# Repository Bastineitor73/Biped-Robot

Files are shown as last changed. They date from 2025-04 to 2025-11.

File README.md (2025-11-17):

# Contacto

Quieres ser parte de B1P0? Envía un correo a josespi@udec.cl, mariomedina@udec.cl, agarrido2018@udec.cl o ginostroza2020@udec.cl

# Contenidos
- [Proyecto B1P0](#proyecto-b1p0)
  * [Objetivo](#objetivo)
  * [Visiones](#visiones)
  * [Temas actuales](#temas-actuales)
  * [Diagrama Electrico](#diagrama-electrico)
- [Avances](#avances)
- [Invitacion Charla](#invitacion-charla)
- [Contacto](#contacto)

# Proyecto B1P0


Quieres ser parte de B1P0? Envía un correo a agarrido2018@udec.cl o a ginostroza2020@udec.cl

## Objetivo
"Crear un robot bípedo estable y escalable a lo largo del tiempo desarrollado por alumnos del DIE, capaz de desenvolverse en entornos industriales complejos, catástrofes naturales, inspecciones y escenarios de alto riesgo humano"

## Visiones
<p align="center">
  
  
  
</p>

## Temas actuales
1.- Modelación física y desarrollo de un gemelo digital para entrenamiento y simulaciones

2.- Rediseño estructural del robot bípedo existente, mediante análisis de esfuerzos, estudio de materiales, mejoras en sistemas mecánicos y resistencia.

3.- Diseño e integración de una arquitectura de software basada en ROS/ROS2 para la comunicación entre CPU, microcontroladores, actuadores y usuario

4.- Diseño e implementación de un sistema de control remoto inalámbrico utilizando tecnologías RF, WiFi o Bluetooth.

5.- Diseño e implementación de un sistema de control adaptativo o predictivo para la estabilidad del robot bípedo

6.- Desarrollo de un sistema de estimación de estados mediante fusión de datos inerciales (IMU) y modelos dinámicos

7.- Implementación de un sistema de percepción visual y mapeo de entorno mediante cámara de profundidad

# Avance Actual

## Octubre 2025

https://github.com/user-attachments/assets/e0c73ede-dcd1-4829-920c-aed435cbe2b3

# Revisa nuestra Charla

https://www.canva.com/design/DAG2QE-IAb0/ETZ7DED0be4jHASCjCmeyw/view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

invitacion_2

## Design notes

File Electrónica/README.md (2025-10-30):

# Diagrama Electrico


# Lista de Dispositivos

## Microcontrolador Teensy 4.1


## SparkFun OpenLog Artemis


## Raspberry Pi 5, 16 GB RAM


## Cámara Intel RealSense D435i


## Batería Lipo
- 22.2V
- 6 celdas
- 5000 mAh


# Desarollo PCB's
Interacción de los componentes



## Monitor de bateria y Medidor de combustible
- Monitor MP2790
- Fuel Gauge MPF42795
- Comunicacion por I2C con librería "MP27XX.h"

- Placa accesoria para llave de paso MOS

- Placa accesoria UI Medidor de combustible
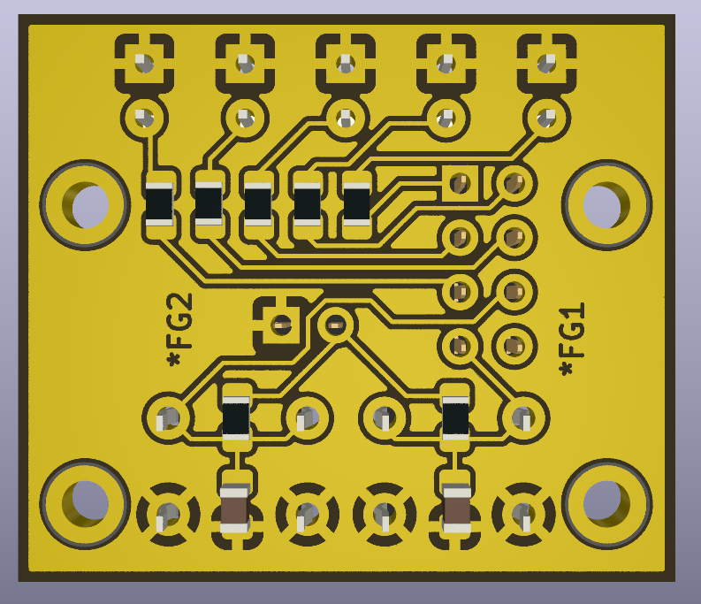
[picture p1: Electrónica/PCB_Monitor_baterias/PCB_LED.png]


## Placa de alimentacion
- Conversor buck TPS54531 5V @25W
- Regulador lineal TLV757p 3V3 @3W
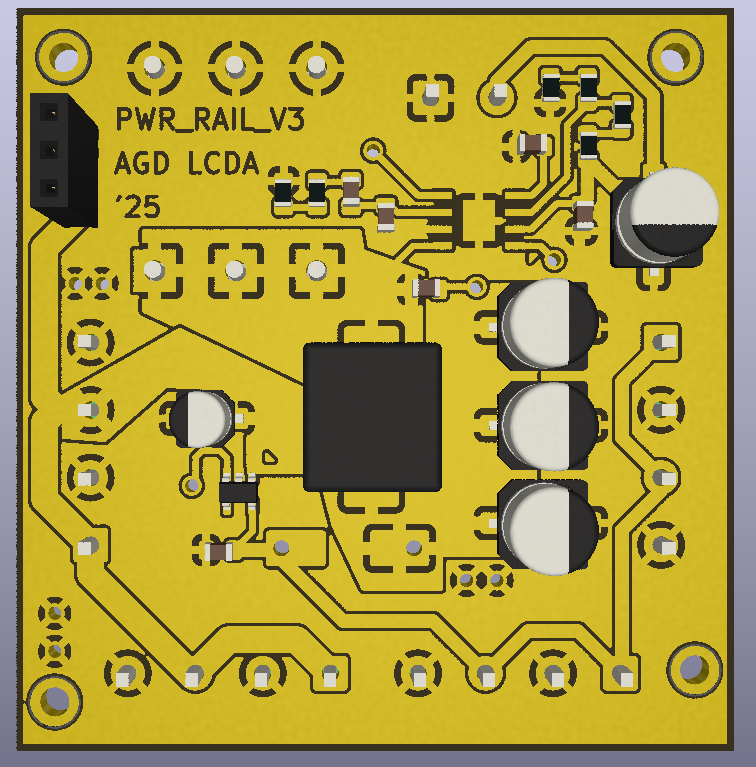
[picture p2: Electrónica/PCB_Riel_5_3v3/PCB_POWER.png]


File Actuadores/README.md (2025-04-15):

# Lista de Dispositivos

## Odrive S1
Driver de control de motores, utilizados para manejar los 6 actuadores del robot utilizando comunicación CAN.
- Voltaje de Operación: 12-48V
- Corriente Máxima: 40A (Continua)
- Modos de Control: Torque, Velocidad, Posición y Trayectoria
- Incluye encoder magnético MA702
- Peso: 35g
- Datasheet: https://docs.odriverobotics.com/v/latest/hardware/s1-datasheet.html
  


## Motor Eaglepower
Músculos principales del robot, cada motor (6 en total) son montados en 2 piernas (3 en cada una) por medio de una caja reductora de relación 9:1, amplificando así el torque de cada actuador.
- 90KV
- 40 polos





Parametros tabla KV90 con propeller T2795

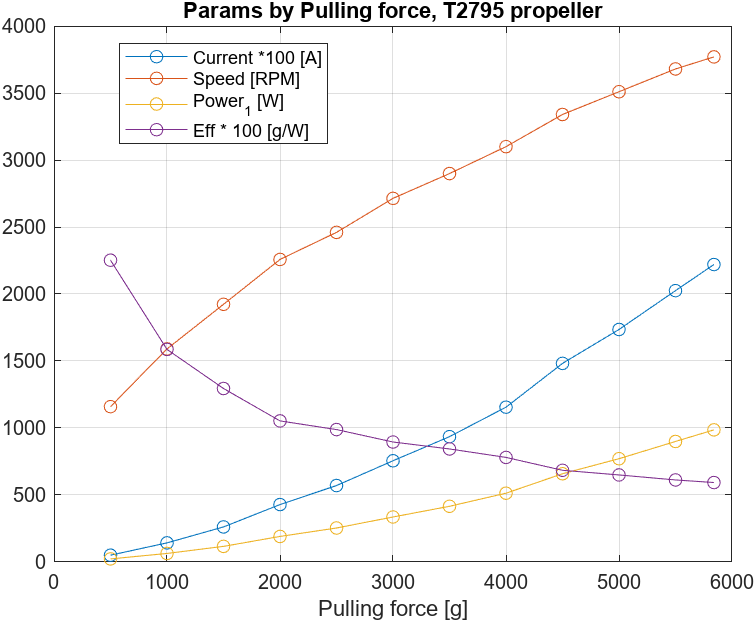
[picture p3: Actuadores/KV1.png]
Tabla KV90


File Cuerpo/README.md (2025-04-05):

# Materiales

## Filamento PLA


## Placa de fibra de carbono 
- 200x250mmx2mm



## Tubos de Fibra de carbono
- 19x17mm largo 500mm (x2)
- 12x10mm largo 500mm (x2)
- 28x26mm largo 500mm (x2)



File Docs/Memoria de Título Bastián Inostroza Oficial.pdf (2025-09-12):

UNIVERSIDAD DE CONCEPCIÓN
FACULTAD DE INGENIERÍA
DEPARTAMENTO DE INGENIERÍA ELÉCTRICA

DISEÑO E INTEGRACIÓN DE ACTUADORES QUASI-DIRECT DRIVE PROPIOCEPTIVOS EN UN ROBOT BÍPEDO DE ALTA DINÁMICA

POR

Bastián Nicolás Inostroza Sanzana

Memoria de Título presentada a la Facultad de Ingeniería de la Universidad de Concepción para optar al título profesional de Ingeniero(a) Civil Electrónico(a)

Profesor(es) Guía
José Rubén Espinoza Castro

Septiembre 2025
Concepción (Chile)

©2025 Bastián Nicolás Inostroza Sanzana

ii

©2025 Bastián Nicolás Inostroza Sanzana

Se autoriza la reproducción total o parcial, con fines académicos, por cualquier medio o procedimiento, incluyendo la cita bibliográfica del documento.

iii

A Dios por la fuerza que me da para no rendirme. A toda mi familia que amo y siempre me ha apoyado. A mi pareja y amigos que creyeron en mí. Y por los alumnos del pasado, presente y futuro del L.C.D.A.

iv

## Agradecimientos

Primero que todo le doy gracias a Dios por darme la energía y perseverancia en esta memoria. Sin duda, si no fuera por Él, no habría logrado terminar un proyecto tan ambicioso y grande como lo

es el construir un robot de este alcance.

También le doy gracias a mis padres y familia que siempre creyeron en mis capacidades, me

educaron para lograr todas las metas que me proponga, me apoyaron cuando necesitaba ayuda y para

aconsejarme.

Gracias le doy al profesor José Espinoza por creer en este proyecto desde el primer día,

gestionar cada material, ser un excelente mentor y académico, que en mi opinión, es el mejor de la

Universidad de Concepción.

Gracias le doy a mi pareja por alentarme cada día, apoyarme cuando me sentía cansado y

siempre levantarme los ánimos durante largas jornadas de trabajo.

Gracias le doy a mis amigos que creyeron en mí, me brindaron ideas, me criticaron

constructivamente y en ciertas ocasiones me colaboraron con el armado del robot.
Gracias le doy enormemente a don René Álvarez por apoyarme en el ensamblado del robot y

la manufactura de piezas, además de sus sabios consejos profesionales que los llevaré siempre en mis

recuerdos.

Gracias por su puesto al director del Departamento de Ingeniería Eléctrica, el profesor Juan

Tapia, junto con el profesor Luis Morán y el vicedecano Eduardo Balladares, por haber contribuido

en gran manera con el financiamiento de este proyecto.

También agradezco a don Ramón Lillo por facilitar sus instrumentos de laboratorio y su

colaboración en la mantención de algunos motores.

Por último pero no menos importante, agradezco a los compañeros del L.C.D.A. que fueron

casi como una familia a lo largo del semestre, sin duda sus consejos u opiniones fueron de gran ayuda

para el desarrollo de este proyecto.

Nadie llega lejos solo, detrás de grandes proyectos, hay grandes equipos. Sin embargo, a pesar

de todo, mi mayor fuente de inspiración y perseverancia ha sido la fe. Con ese espíritu de confianza y

resiliencia que ha guiado cada paso, concluyo con una cita que resume mi experiencia:

“Bendito el varón que confía en Jehová, y cuya confianza es Jehová. Porque será como el

árbol plantado junto a las aguas, que junto a la corriente echará sus raíces, y no verá cuando viene

el calor, sino que su hoja estará verde; y en el año de sequía no se fatigará, ni dejará de dar fruto.”

(Jeremías 17:7-8)

v

## Sumario

En la última década, la robótica bípeda ha experimentado un progreso gigante. El desarrollo

de plataformas como Atlas (Boston Dynamics), Cassie (Agility Robotics) o Tron 1 (Limx Dynamics)

han mostrado que los principales desafíos siguen siendo la estabilidad, planificación de trayectorias,

eficiencia energética, reducción de masa y últimamente los tipos de actuadores. En este escenario, los

actuadores Quasi Direct Drive (QDD) se han transformado en un hito tecnológico al permitir

transmisiones bajas y compactas, con alta densidad de torque, bajo peso y buena eficiencia energética,

condiciones críticas para lograr movimientos rápidos y controlados en tiempo real. Universidades

reconocidas como MIT, Stanford, UCLA o empresas privadas como Boston Dynamics han liderado

estas investigaciones, estableciendo un estándar que enseña e inspira desarrollos a nivel global.

En este contexto, la presente memoria aborda el diseño y validación de un actuador QDD

propioceptivo e integrado en el robot bípedo B1P0 de 6 grados de libertad, cumpliendo los objetivos

de: (i) comunicación CAN multi-driver operativa; (ii) modelo 3D e integración mecánica; (iii) control

independiente por eje con demostración funcional; y (iv) un actuador de alta densidad de torque capaz

de retroalimentar su posición con exactitud en tiempo real. El actuador desarrollado con un reductor

planetario 9:1 impreso en 3D alcanza una densidad de torque de 20.9 [Nm/kg], con aproximadamente

un 95 % de eficiencia frente al motor desnudo (sin reductor) que genera 5.3 [Nm/kg]. Concluyendo

además, que el actuador construido entrega 8.8 veces más torque útil sin penalizar corriente.

El chasis modular de tres niveles (potencia, control y sensores) permitió fácil mantenimiento

y alta escalabilidad; el sistema entra de forma confiable en lazo cerrado y ejecuta trayectorias por

CAN (video demo en el repositorio). En conjunto, B1P0 constituye hasta donde se tiene registro, el

primer prototipo de robot bípedo de esta envergadura en Chile, desarrollado íntegramente en el

Laboratorio de Control Digital Aplicado (L.C.D.A.) de la Facultad de Ingeniería de la Universidad de

Concepción, dejando una base sólida para iterar en: estructura y materiales livianos, simulaciones

avanzadas, sistemas de control, visión por computadora e inteligencia artificial.

vi

## Summary

Over the last decade, bipedal robotics has experienced tremendous progress. The development

of platforms such as Atlas (Boston Dynamics), Cassie (Agility Robotics), and Tron 1 (Limx

Dynamics) have shown that the main challenges remain stability, trajectory planning, energy

efficiency, mass reduction, and, more recently, actuator types. In this context, Quasi Direct Drive

(QDD) actuators have become a technological milestone, enabling low and compact transmissions

with high torque density, low weight, and good energy efficiency—critical conditions for achieving

rapid, controlled movements in real time. Renowned universities such as MIT, Stanford, and UCLA,

as well as private companies such as Boston Dynamics, have led this research, setting a standard that

teaches and inspires developments globally.

In this context, this paper addresses the design and validation of a proprioceptive QDD actuator

integrated into the 6-degree-of-freedom B1P0 biped robot, fulfilling the objectives of: (i) operational

multi-driver CAN communication; (ii) 3D model and mechanical integration; (iii) independent axis

control with functional demonstration; and (iv) a high-torque-density actuator capable of accurate

position feedback in real time. The developed actuator with a 3D-printed 9:1 planetary gearbox

achieves a torque density of 20.9 [Nm/kg], with approximately 95% efficiency compared to the bare

motor (without gearbox) that generates 5.3 [Nm/kg]. Furthermore, it is concluded that the constructed

actuator delivers 8.8 times more useful torque without any current penalty.

The three-level modular chassis (power, control, and sensors) allowed for easy maintenance

and high scalability. The system reliably enters a closed loop and executes trajectories via CAN (demo

video in the repository). Overall, B1P0 constitutes the first bipedal robot of this size in Chile,

developed entirely in the Applied Digital Control Laboratory (LCDA) of the Faculty of Engineering

at the University of Concepción, leaving a solid foundation for iterating in: lightweight structure and

materials, advanced simulations, control systems, computer vision, and artificial intelligence.

vii

## Tabla de Contenidos

viii

ix

## Lista de Tablas

x

## Lista de Figuras

Figura 1.2: Comparación anatómica de articulaciones inferiores entre humano y avestruz (Haberland

Figura 1.3: Comparativa del movimiento articular entre el colapso de rodilla hacia adelante y la

Figura 1.5: Vista transversal superior del actuador de acero-molibdeno robótico diseñado por la

Figura 2.4: Funcionamiento interno de un motor BLDC comparando señales de entrada y salida ... 14

Figura 2.12: Componentes de un nodo (dispositivo) conectado a un bus de CAN (datasheet modulo

Figura 2.13: Funcionamiento de 2 estados lógicos en protocol CAN, recesivo 1 y dominante 0 (A. Martínez Requena, "Introducción a CAN bus: Descripción, ejemplos y aplicaciones de tiempo

Figura 4.4: Región de operación del control de torque basado en límites de corriente y velocidad.. 42

xi

Figura 5.4: Actuador impreso; a) sin carcasa y salida de pernos, b) con carcasa y salida con polea

### 1. Introducción

### 1.1. Introducción General

Los robots bípedos han evolucionado desde prototipos experimentales de universidades

destacadas hasta plataformas con aplicaciones prácticas en industrias como minería, manufactura,

logística y rescate. Su principal ventaja radica en la capacidad de operar en entornos diseñados para

humanos, incluyendo terrenos irregulares y espacios confinados donde los sistemas con ruedas

resultan ineficientes. Sin embargo, su desarrollo enfrenta tres desafíos fundamentales: (1) la

complejidad en mantener estabilidad con solo dos puntos de apoyo, (2) la alta demanda energética en

movimientos explosivos (como saltos, escaladas, caídas, etc.), y (3) la necesidad de actuadores que

combinen alto torque, precisión y baja inercia sin incrementar excesivamente costos o el peso.

En este contexto, los actuadores eléctricos propioceptivos han surgido como solución clave

para robots dinámicos, destacándose en plataformas como el MIT Mini Cheetah [1], Cassie de Agility

Robotics [2] o en robots comerciales como el construido por la empresa China Limx Dynamics [3],

Fig. 1.1. Estos sistemas integran sensores de posición y control de torque en lazo cerrado, permitiendo

movimientos precisos bajo cargas variables y mejorando la eficiencia energética [4]. No obstante, su

implementación en entornos académicos suele verse limitada por los altos costos de componentes

personalizados y la complejidad en el diseño mecánico de reductores planetarios, como se evidenció

en los prototipos preliminares desarrollados para esta investigación [5].

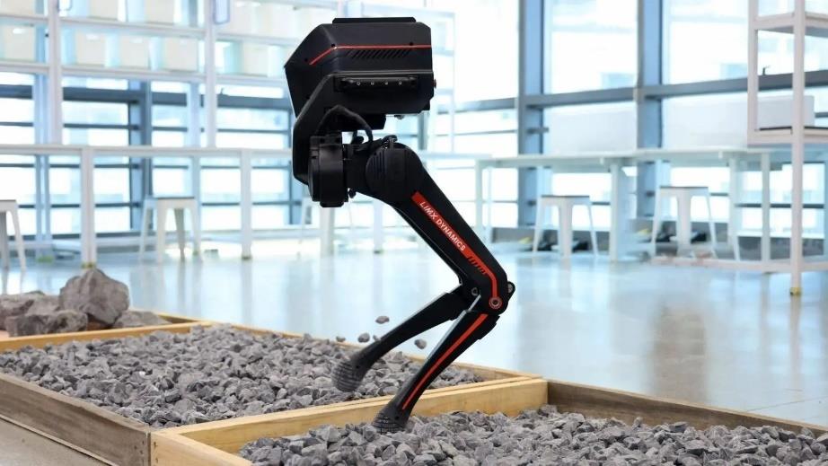
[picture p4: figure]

Figura 1.1: Robot bípedo Tron 1, desarrollado por la empresa LimX Dynamics

Esta memoria, además aborda el diseño, construcción y validación experimental de un

actuador robótico QDD propioceptivo modular de bajo costo, destinado a un robot bípedo de 6 grados

de libertad. La propuesta se basa en tres pilares: (i) el uso de motores BLDC comerciales acoplados a

engranajes planetarios impresos en 3D, validando experimentalmente como se mejora el torque

continuo de salida y la densidad de torque; (ii) la implementación de un sistema de control basado en

el driver Odrive S1 [6], utilizando protocolos CAN bus para sincronización multi-actuador; y (iii) la

modelación 3D de un robot bípedo con su respectivo prototipo físico.

Los resultados obtenidos no solo tienen potencial aplicación en industrias de alta dinámica y

terrenos complejos como minería, construcción, agronomía, entre otros. Sino que además, presentan

un gran avance en el desarrollo de robots humanoides en Chile, siendo la Universidad de Concepción

de las primeras casas de estudios en diseñar y construir un prototipo de robot bípedo modular y

altamente escalable para investigaciones futuras, dando un paso al frente en la robótica avanzada para

nuestro país.

### 1.2. El riesgo inherente de labores humanas

El uso de robots bípedos en labores de alto riesgo se presenta como una solución eficiente y viable en sectores donde las condiciones de trabajo son peligrosas para los seres humanos. Ámbitos

como el rescate en incendios forestales, las labores de salvamento en entornos urbanos o las

actividades en minería enfrentan riesgos constantes, que van desde accidentes por caídas, colapsos

estructurales, hasta la exposición a gases tóxicos y químicos. Un bombero en acción, por ejemplo, se

ve constantemente expuesto a peligros como quemaduras, derrumbes o la caída de elementos pesados,

como árboles y ramas. En la industria minera, los informes del Servicio Nacional de Geología y

Minería (Sernageomin) señalan que las principales causas de accidentes fatales son los golpes de

rocas, las caídas desde alturas y los deslizamientos de tierra [7]. Además, las estadísticas de

accidentabilidad laboral del 2020 revelan que los accidentes más comunes se originan a partir de

factores materiales, como el uso de herramientas no eléctricas, y condiciones ambientales o

estructurales adversas [8]. Como se ilustra en la Tabla 1.1:

Tabla 1.1: Tabla de indicadores de accidentabilidad año 2021, por SISESAT SUSESO

A partir de estos datos, es evidente que, si bien algunos accidentes pueden originarse por

errores humanos, muchos otros son el resultado de condiciones imprevistas o peligrosas que no pueden

ser fácilmente mitigadas por la intervención directa de los trabajadores. Los robots bípedos, equipados

con sensores avanzados, podrían realizar tareas como la inspección de zonas peligrosas, la detección

de sustancias tóxicas y la evaluación de la estabilidad estructural, minimizando así la exposición de

los trabajadores a estos riesgos. Estos robots no solo serían capaces de acceder a lugares inaccesibles

para los humanos, sino que también ofrecerían una capa adicional de seguridad al acompañar a los

operativos en terreno, anticipando y previniendo posibles accidentes.

Aunque los robots móviles autónomos con ruedas también podrían realizar algunas de estas

tareas, su capacidad para maniobrar en terrenos complejos es limitada. Las ruedas enfrentan

dificultades al sortear obstáculos, subir escaleras o desplazarse en terrenos irregulares, lo que

incrementa el consumo energético y, en muchos casos, hace inviable su uso en entornos altamente

dinámicos. En cambio, un robot bípedo, gracias a su capacidad para adaptarse a variaciones en el

terreno y sortear obstáculos con mayor facilidad, representa una solución más eficiente, segura y

energética para enfrentar desafíos en estos entornos.

### 1.3. Una breve revisión sobre los robots de alta dinámica con patas

Los robots humanoides y con patas han experimentado avances tecnológicos considerables en

las últimas dos décadas. Dos factores principales que han contribuido al desarrollo de la investigación

sobre robots con patas: el hardware y la tecnología de control.

Ahora bien, la pregunta que cualquiera podría realizarse es porque con patas y no con ruedas.

La promesa de los robots con patas frente a los robots con ruedas estándar es proporcionar una

movilidad mejorada en terrenos difíciles. Esta promesa se basa en el desacoplamiento entre el entorno

y el cuerpo principal del robot que permite la presencia de piernas articuladas, con dos consecuencias.

En primer lugar, el movimiento del cuerpo principal del robot puede hacerse en gran medida

independiente de la rugosidad del terreno, dentro de los límites cinemáticos de las piernas. En segundo

lugar, este desacoplamiento permite que las piernas abandonen temporalmente su contacto con el

suelo, pudiendo así superar los puntos de apoyo aislados en un terreno discontinuo, lo que permite

visitar lugares absolutamente fuera de alcance de otro modo y además mejorar la eficiencia energética

en ciertos periodos de tiempo cuando una pierna esté en caída libre.

Aunque todavía no igualan las capacidades de los humanos y los animales, los robots con patas

sí contribuyen a comprender su locomoción y estilo de movimiento, como lo demuestran las muchas

colaboraciones fructíferas entre investigadores en robótica y biomecánica.

Recientemente, diferentes institutos de investigación han desarrollado robots cuadrúpedos más

avanzados, como HyQ, ANYmal, MITCheetah y MiniCheetah. En el caso de los robots bípedos y

humanoides, se han publicado en la literatura muchos logros de investigación significativos como

TORO, TALOS, E2-DR, Cassie o algunos robots industriales de origen privado como el Biped Robot

Tron 1 de Limx Dynamics, Digit de Agility Robotics, Optimus Gen 2 de Tesla, o el recientemente

actualizado robot Atlas de Boston Dynamics.

El progreso en las últimas décadas ha sido notable. Preguntas profundas han sido finalmente

respondidas: ahora se entiende cómo hacer que los robots con patas caminen y corran de manera

bastante práctica. Pero aún quedan otras preguntas profundas por responder, como cuál es la mejor

manera (o manera óptima) de hacer que caminen y corran eficientemente, o también si es posible

estandarizar o generalizar un método de locomoción bípeda en la mayoría de robots.

El rendimiento de los robots con patas necesita ser mejorado de muchas maneras: energía,

velocidad, reactividad, versatilidad, robustez, etc. Por lo tanto, seguiremos discutiendo en el siguiente

tema los problemas más relevantes que actualmente intrigan a nuestra comunidad robótica.

### 1.4. La eficiencia anatómica de robots bípedos con rodillas hacia atrás

El diseño de robots bípedos se basa en principios anatómicos observados en la naturaleza,

destacando la orientación de las rodillas. En el estudio de Haberland y Kim (2015) [4], se demuestra

que las rodillas hacia atrás optimizan la eficiencia de locomoción al reducir la dependencia del torque

en la cadera y permitir que una sola articulación combine funciones de propulsión y elevación. Este

diseño es más eficiente en un 80% de los casos evaluados en cuanto al costo mecánico de transporte,

con una significativa disminución del esfuerzo en la cadera.

Sin embargo, es importante aclarar que el diseño del robot bípedo no utiliza rodillas en el

sentido convencional. Aunque el estudio se basa en la eficiencia de rodillas hacia atrás, en el futuro

robot lo que parecen ser las rodillas, de hecho, son tobillos modificados con una configuración similar

a las rodillas hacia atrás como se puede ver en la Figura 1.2. Esto significa que, aunque la anatomía y

la mecánica son las de un tobillo, visual y funcionalmente adoptan un principio similar al de las

rodillas hacia atrás, favoreciendo la propulsión y la elevación sin depender del movimiento de la

cadera.

Figura 1.2: Comparación anatómica de articulaciones inferiores entre humano y avestruz (Haberland y Kim, 2015)

Ventajas funcionales clave de este diseño:

1. Propulsión y elevación simultáneas: Las articulaciones modificadas, que imitan el

comportamiento de las rodillas hacia atrás, permiten que el robot mantenga propulsión

sin depender de la cadera. Como se observa en la Figura 1.3, una rodilla tradicional

hacia adelante no podría realizar este tipo de propulsión sin la ayuda de la cadera.

2. Reducción de pérdidas de energía por impacto: Al igual que en el caso de las

rodillas hacia atrás, este diseño reduce el torque cuadrático, optimizando el costo de

transporte y mejorando la eficiencia energética.

Figura 1.3: Comparativa del movimiento articular entre el colapso de rodilla hacia adelante y la propulsión con rodilla hacia atrás (Haberland y Kim, 2015)

Aunque el estudio de Haberland y Kim [4] no evalúa explícitamente terrenos irregulares, los

principios mencionados sugieren que este tipo de diseño también es ventajoso en contextos de

variabilidad del terreno debido a:

- Menor dependencia de la cadera: La reducción del torque necesario en la cadera minimiza

los desbalances causados por cambios en la altura del terreno o impactos laterales.

- Adaptación a variaciones del terreno: La capacidad de los tobillos modificados para realizar

propulsión y elevación permite ajustes rápidos en la zancada sin comprometer la estabilidad.

- Centro de masa estable: Concentrar la masa cerca del torso reduce el momento de inercia,

facilitando el equilibrio ante perturbaciones externas.

Este diseño con tobillos modificados que simulan rodillas hacia atrás se presenta como una

solución eficiente y funcional para superar las limitaciones comunes en la locomoción robótica. La

capacidad de reducir la dependencia de la cadera, optimizar el torque en las articulaciones y adaptarse

dinámicamente a variaciones del terreno resalta como una ventaja clave para el rendimiento del robot,

posicionándolo como una opción robusta para aplicaciones en terrenos complejos.

### 1.5. Requisitos de diseño en actuadores modulares para robots de alta dinámica

Un robot bípedo sin un buen actuador, es como un deportista sin buenos músculos. El diseño

de actuadores modulares para robots de alta dinámica, siendo generalmente estudiado por las

universidades mas reconocidas del mundo en robótica, debe equilibrar torque, eficiencia, velocidad y

peso. A continuación se presentan los requisitos clave extraídos de actuadores desarrollados por

algunas academias, como la Universidad de Genoa, la Universidad de Denver y el Instituto

Tecnológico de Massachusetts (MIT).

1. Densidad de torque y eficiencia:

El robot Mini Cheetah del MIT (ver Figura 1.4) optimiza la densidad de torque mediante un

rotor personalizado, logrando un torque máximo de 34 [Nm] sin aumentar el tamaño del motor [9].

Este enfoque de alta densidad de torque es esencial para generar fuerza en un tamaño compacto.

Similarmente, el actuador de la Universidad de Genoa prioriza alta velocidad y torque continuo

mediante un diseño de baja reducción, alcanzando un torque continuo de 26.4 [Nm] con una eficiencia

de 80% [10].

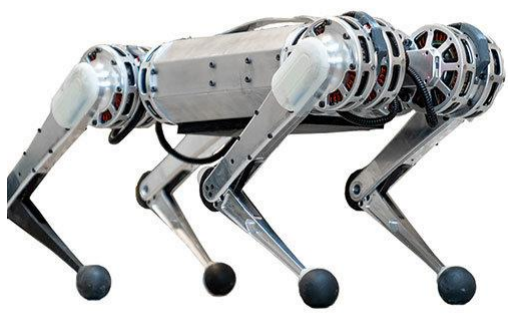
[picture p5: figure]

Figura 1.4: Robot Mini Cheetah del Instituto Tecnológico de Massachusetts

2. Reducción de inercia y aumento de compacidad:

El Mini Cheetah y el robot Mithra de la Universidad de Denver colocan los actuadores de

manera proximal para reducir la inercia, facilitando movimientos rápidos y controlados [9][11].

Mithra también utiliza mecanismos de 4 barras en el tobillo para reducir la masa distal y mejorar la

dinámica.

3. Adaptabilidad dinámica y control:

El actuador del MIT y de Genoa integran sensores de retroalimentación como encoders

magnéticos y control FOC, lo que permite ajustar la respuesta del actuador en tiempo real durante

tareas dinámicas [9][10], asegurando un control preciso incluso en altas velocidades, permitiendo que

el actuador mantenga un rendimiento estable bajo condiciones dinámicas

4. Resistencia estructural:

La resistencia estructural es clave para soportar fuerzas de impacto y garantizar la durabilidad

del actuador. El uso de materiales ligeros y resistentes en el MIT Mini Cheetah y el robot Mithra

aseguran la resistencia estructural sin aumentar mucho el peso. El robot de Genoa utiliza engranajes

de acero-molibdeno (ver Figura 1.5) en su caja reductora para proporcionar rigidez adicional [10].

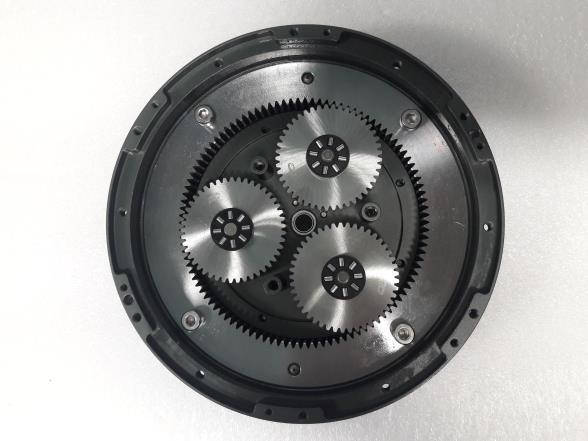
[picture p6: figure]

Figura 1.5: Vista transversal superior del actuador de acero-molibdeno robótico diseñado por la Universidad de Genoa, Italia.

### 1.6. Objetivos

1.6.1 Objetivo General

Diseñar, construir y validar actuadores robóticos QDD propioceptivos capaces de funcionar

simultáneamente integrados en un robot bípedo de 6 grados de libertad.

1.6.2 Objetivos Específicos

- Establecer un protocolo de comunicación para el trabajo simultáneo de múltiples drivers

y verificar su correcto funcionamiento.

- Construir un actuador robótico de baja relación de transmisión capaz de retroalimentar su

posición en tiempo real.

- Diseñar un modelo 3D para un robot bípedo de 6 grados de libertad.
- Lograr un movimiento independiente de cada eje del robot bípedo.

### 1.7. Alcances y Limitaciones

Este trabajo se enfoca en desarrollar actuadores robóticos para un robot bípedo, pero con

algunas restricciones importantes. No se diseñarán los circuitos electrónicos ni los motores desde cero,

se utilizarán componentes ya disponibles en el mercado. Tampoco se harán optimizaciones mecánicas

muy avanzadas, sino que se limitará a modelado 3D básico con los materiales que se tengan a mano.

Lo que sí se logra es crear un sistema completo donde varios actuadores trabajen

independientemente, con un protocolo de comunicación implementado. El robot tendrá 6 grados de

libertad y se validará el funcionamiento con pruebas prácticas de movimiento y torque, sabiendo que

será un prototipo académico más que un producto industrial terminado.

La idea es demostrar que se puede armar un sistema robótico funcional con componentes

accesibles, sentando bases para futuras mejoras. No es perfecto, pero sirve para investigar conceptos

clave de locomoción bípeda, sistemas de comunicaciones, actuadores eléctricos, cinemática, visión

artificial y varios conceptos más abordados por diferentes alumnos de la facultad de ingeniería, de tal

manera de crear un proyecto sólido y escalable a lo largo del tiempo.

### 1.8. Temario y Metodología

Esta memoria sigue una estructura progresiva que avanza desde los fundamentos teóricos hasta

la implementación práctica, organizada en seis capítulos principales. El Marco Teórico (Capítulo 2)

establece las bases físicas y mecánicas del proyecto, incluyendo dinámica rotacional, diseño de

actuadores y protocolos de comunicación, respaldado por revisión bibliográfica de referencias clave.

Los Capítulos 3 y 4 analizan soluciones existentes y presentan una propuesta de diseño, centrada en

modularidad y bajo costo mediante modelado 3D y componentes comerciales.

La metodología combina prototipado ágil (impresión 3D, pruebas incrementales) con

validación experimental sistemática. Finalmente el Capítulo 5 detalla la implementación del actuador

y los resultados de torque y sincronización de actuadores, contrastando datos teóricos y empíricos. El

proceso se apoya en herramientas como Fusion 360, lenguaje C++, Python, entre otras. Asegurando

constantemente el cumplimiento de los objetivos específicos planteados en la sección 1.6.2.

### 2. Marco Teórico

### 2.1. Motores DC Brushless y operación

Los motores DC Brushless, conocidos popularmente como BLDC (Brushless DC), son

motores eléctricos de corriente continua que no poseen escobillas ni sistemas de conmutación

mecánica, a diferencia de los motores DC tradicionales. Esta ausencia de partes móviles de fricción

proporciona beneficios como mayor vida útil, menor mantenimiento y una eficiencia energética

superior.

Aunque estos motores suelen clasificarse como motores DC debido a su alimentación directa

con corriente continua, técnicamente pertenecen a la familia de motores síncronos, caracterizados por

operar a una velocidad sincronizada con la frecuencia de la corriente aplicada mediante un inversor

electrónico. Esta velocidad se define según la fórmula:
N =

120f
P

(2.1)

donde N representa la velocidad de sincronismo en [rpm], f la frecuencia de alimentación, y

P el número de pares de polos del motor [12]. De esta ecuación se concluye que, para realizar un

control continuo y eficiente de la velocidad, es imprescindible modificar la frecuencia de excitación

eléctrica del motor ya que la alternativa de variar físicamente el número de pares de polos es inviable

para aplicaciones dinámicas donde buscamos obtener velocidades variantes y no discretas en el

tiempo.

2.1.1 Construcción

Los motores BLDC presentan dos configuraciones constructivas principales [13]:

- Inrunner: El rotor se ubica en el interior del estator, proporcionando mayores

velocidades de rotación a costa de un menor torque.

- Outrunner: El rotor rodea externamente al estator, resultando en mayores niveles de

torque pero a menores velocidades, como se muestra en la Figura 2.1.

Figura 2.1: Configuraciones clásicas de estator y rotor en motores BLDC

La estructura interna consiste en un rotor provisto de imanes permanentes y un estator con

devanados distribuidos en fases generalmente trifásicas. La Figura 2.2 ilustra esta configuración

básica.

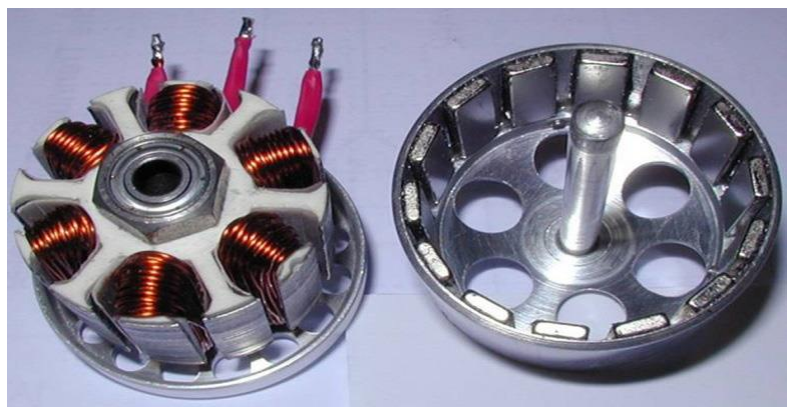
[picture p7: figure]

Figura 2.2: Estructura interna de un motor BLDC de tipo Outrunner

2.1.2 Principio de funcionamiento y sistemas de control

El principio de operación del motor BLDC radica en la interacción entre los campos

magnéticos generados por los imanes permanentes del rotor y los campos electromagnéticos

generados por los devanados del estator. Estos motores están diseñados específicamente para lograr

una fuerza electromotriz (FEM) de forma trapezoidal, lo que exige un flujo magnético uniforme por

parte del rotor [14].

En un motor BLDC trifásico típico, las fases del estator (A, B y C) se energizan

secuencialmente mediante un controlador electrónico, generalmente un inversor trifásico. Esta

secuencia de activación crea un campo magnético rotatorio que interactúa con el campo magnético estático generado por los imanes permanentes del rotor, induciendo así su rotación. La activación de

cada fase debe sincronizarse cuidadosamente en función de la posición angular del rotor, generalmente

detectada por sensores Hall o mediante técnicas de detección de fuerza contraelectromotriz (FCEM).

La Figura 2.3 muestra una configuración típica de un motor trifásico BLDC, donde se

identifican el estator con las bobinas trifásicas (fases U, V y W), el rotor provisto de imanes

permanentes, y el espacio de aire que facilita la interacción magnética.

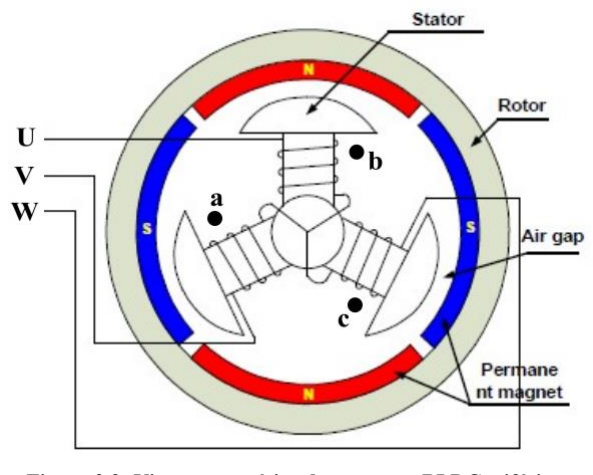
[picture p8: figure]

Figura 2.3: Vista esquemática de un motor BLDC trifásico

La secuencia típica de activación de las fases sigue un patrón como U→V→W, con cada fase

activada en intervalos específicos y alternando la polaridad para asegurar una rotación continua y

uniforme del rotor. Este proceso se repite continuamente mientras se aplica energía al motor [14].

Como se ha explicado anteriormente, para poder controlar la velocidad de un motor síncrono

de una manera continua es necesario ajustar la frecuencia de excitación, por este motivo los motores

BLDC precisan de algún dispositivo capaz de transformar una señal continua en otra alterna; para la

tarea anterior se suele utilizar un inversor, capaz de generar una señal de excitación alterna de

frecuencia deseada con la que poder alimentar a cada fase del motor.

La conmutación y control preciso de los motores BLDC generalmente se realiza mediante

sensores de efecto Hall. Estos sensores proporcionan señales discretas que informan al controlador

electrónico sobre la posición angular del rotor, lo que permite realizar una conmutación adecuada y

precisa de los devanados del estator, asegurando un control estable y eficiente.

Figura 2.4: Funcionamiento interno de un motor BLDC comparando señales de entrada y salida

La Figura 2.4 muestra la relación entre la señal generada por la FEM y la posición codificada

por los sensores de efecto Hall.

En aplicaciones donde los sensores no son una opción viable, por ejemplo en ambientes

herméticos como compresores, se utiliza un método denominado control "sensorless", basado en la

detección de la fuerza contraelectromotriz (FCEM). En este enfoque, la conmutación se realiza

detectando los cruces por cero de la señal FCEM [14].

2.1.3 Comparación respecto a alternativas de motores DC

La elección de motores BLDC para robots dinámicos bípedos está justificada por varias

razones técnicas. Los motores síncronos alimentados por corriente alterna no son adecuados debido a

la limitación práctica de disponer de una red fija de 220 [V]. Por ende, los motores BLDC alimentados

por corriente continua destacan como la opción ideal, al proporcionar alto torque, respuesta rápida y

eficiencia energética con fuentes de alimentación portátiles.

En comparación con otras opciones populares como servomotores o motores paso a paso, los

motores BLDC ofrecen ventajas claras en aplicaciones robóticas dinámicas debido a su mayor

relación torque-peso, alta eficiencia energética y capacidad para respuestas rápidas y precisas en

situaciones cambiantes. Los servomotores tienden a ser más pesados y lentos, mientras que los motores paso a paso generalmente presentan limitaciones en términos de torque dinámico y eficiencia

energética.

### 2.2. Fundamentos físicos y mecánicos

En el desarrollo de actuadores robóticos es preciso entender la física detrás de todo y por

supuesto los objetivos que se desean alcanzar. Cuando se busca obtener un actuador robótico robusto,

de alta dinámica, poca masa y alto torque, buscamos cumplir con principios básicos de física general

y mecánica, como lo es el concepto de torque (o par) ya sea mecánico o eléctrico, un concepto poco

conocido pero muy usado en el diseño de sistemas mecánicos fuertes, como lo es la densidad de

torque. Siguiendo la misma línea, como se ve en capítulos posteriores el diseño de un actuador siempre

debe considerar un sistema de amplificación de fuerzas (torque), lo cual en mecánica, siempre lleva a

la teoría y base de todo, como lo es las velocidades angulares, tangenciales y transmisión de potencia.

2.2.1 Torque eléctrico y mecánico

Cuando se ejerce una fuerza en un objeto rígido que se articula en torno a un eje, el

objeto tiende a dar vuelta en torno a dicho eje. La tendencia de una fuerza a dar vuelta un

objeto en torno a cierto eje se mide mediante una cantidad llamada momento de torsión, torque, par o

en algunos países torca. Denominado comúnmente con la letra griega tau (τ). [15]

La magnitud del momento de torsión se define mediante la siguiente expresión medida en

Newton metro [Nm]:
τ = rFsen(φ) | (2.2)

donde r es la distancia entre el punto de aplicación de la fuerza F y φ es el ángulo con la

horizontal en el punto donde se aplica la fuerza. Notar que si φ = 90° el torque es máximo, por lo

tanto en esos casos se puede simplificar la expresión a simplemente la fuerza aplicada multiplicada

por la distancia al eje de rotación.

Por otro lado, pero de manera similar, en las máquinas eléctricas rotatorias, como lo es

anteriormente explicado un motor BLDC, el concepto de torque físicamente es el mismo orientado a

un eje como lo es el rotor, pero se consideran otras propiedades para calcularlo. como por ejemplo la

corriente que circula por la armadura del motor ya que todos los conductores en el devanado de

armadura desarrollan torque en la misma dirección entonces contribuyen a este torque. De esta manera

el torque medio eléctrico total es:

τ = KaΦIa | (2.3)

donde Φ es el flujo magnético que fluye desde el polo a la armadura, Ka la constante del devanado

que depende del diseño del motor y finalmente Ia que es la corriente de armadura que es proporcional

a la carga del motor [16]. De esta manera, el torque claramente depende de la carga sometida en el eje

la cual se ve reflejada en el consumo de corriente.

2.2.2 Densidad de Torque

En el diseño de sistemas mecánicos y actuadores robóticos, un parámetro frecuentemente

subestimado pero de gran relevancia es la densidad de torque. Este concepto permite evaluar la

capacidad de un componente para entregar fuerza rotacional (torque) en relación con el espacio o

volumen que ocupa, lo que resulta fundamental en aplicaciones donde el tamaño y el peso están

restringidos, como en robótica bípedo.

La densidad de torque se define como la relación entre el torque que puede entregar un

componente y su volumen:

### Densidad de Torque =

τ
V
| (2.4)

donde es el torque entregado y el volumen físico del componente. Sus unidades típicas son Newton-metros por metro cúbico [Nm/m³
] o Joules por metro cúbico. En esencia, cuantifica cuánta fuerza

rotacional puede generar un sistema por unidad de espacio disponible [17].

Este parámetro complementa a la tradicional potencia mecánica, definida como:
Pm = τω | (2.5)

donde ω representa la velocidad angular. Si bien la potencia indica cuánto trabajo puede realizar un

sistema por unidad de tiempo, la densidad de torque se centra en dónde ocurre el trabajo dentro del

espacio físico ocupado. En el mundo de la robótica y a lo largo de esta memoria, este parámetro se

expresa en [Nm/kg], ya que se busca comparar directamente el torque disponible con la masa del

actuador. Porque si bien, el volumen es relevante, este se puede flexibilizar dentro del espacio de un

robot o bien adaptar piezas. Sin embargo, el peso es un factor crítico que determina la dinámica y

eficiencia del robot, no pudiendo modificarse fácilmente.

En el diseño de actuadores robóticos, una alta densidad de torque permite integrar sistemas

potentes en estructuras compactas, optimizando espacio y reduciendo masa. Esto mejora la eficiencia

energética, estabilidad y agilidad del robot, aspectos clave en locomoción bípeda.

Usar este parámetro desde etapas tempranas del diseño facilita decisiones inteligentes al

comparar alternativas con igual potencia pero distinta eficiencia volumétrica. Sus beneficios incluyen

reducción de peso, menor volumen ocupado, ahorro de costos y posibilidad de diseños más

innovadores.

En suma, la densidad de torque es un indicador clave para lograr actuadores eficientes y

funcionales en robots de alta dinámica.

2.2.3 Cinemática rotacional

Cuando un objeto rígido gira respecto a un eje fijo, sus partículas se mueven en trayectorias

circulares alrededor de dicho eje. Este tipo de movimiento da origen a dos conceptos fundamentales

para el análisis cinemático de sistemas rotacionales: velocidad angular y velocidad tangencial [15].

La velocidad angular ω describe qué tan rápido gira un objeto respecto a un eje. Si la

aceleración angular α es constante, la variación de ω a lo largo del tiempo se obtiene integrando la

aceleración, es decir:

ωf = ωi + αt | (para α constante) | (2.6)

Esta expresión permite determinar la velocidad angular en cualquier instante t, siendo ωi
| | la

velocidad angular inicial. Es análoga a la ecuación del movimiento rectilíneo uniformemente

acelerado en dinámica lineal.

Por otro lado, la velocidad tangencial v representa la rapidez lineal de una partícula situada a

una distancia r del eje de rotación. Si bien todas las partículas del objeto giran con la misma velocidad

angular, aquellas más alejadas del eje recorren trayectorias circulares más extensas en el mismo

tiempo, por lo que su velocidad lineal es mayor [15].

La relación entre v y ω se obtiene derivando la distancia recorrida s por una partícula en

función del tiempo como se muestra en la Figura 2.5:

Figura 2.5: Partícula P moviéndose en círculo bajo el centro O con una trayectoria s

v =

ds
dt

= r

dθ
dt

(2.7)

Dado que ω =

dθ
dt

, se concluye que:
v = rω | (2.8)

Esta ecuación muestra que la velocidad tangencial de un punto en rotación es directamente

proporcional a su distancia al eje. Por tanto, en un objeto rígido, aunque todos los puntos compartan

la misma velocidad angular, su velocidad tangencial varía linealmente con r.

En el diseño de sistemas rotacionales como actuadores y transmisiones, estas relaciones son

esenciales para calcular velocidades y fuerzas en distintos puntos del mecanismo, y así optimizar su

desempeño mecánico y dinámico.

### 2.3. Sistema de transmisión mecánica

Un sistema de transmisión eficiente es clave para transformar correctamente la energía del

motor en movimiento útil, especialmente cuando se requiere aumentar el torque disponible. En esta

sección se presentan las generalidades necesarias para comprender el funcionamiento de los

engranajes, base indispensable para entender los sistemas planetarios analizados posteriormente.

2.3.1 Generalidades sobre engranajes

Los engranajes son mecanismos diseñados para transmitir movimiento de rotación entre ejes

mediante el contacto sucesivo de dientes tallados en ruedas dentadas. Su función principal es

modificar el torque y la velocidad angular de manera precisa, sin deslizamientos, lo que los convierte

en elementos fundamentales en sistemas de transmisión mecánica [18].

La geometría de un engranaje está definida por varios parámetros clave. El más importante es

la circunferencia primitiva, que es el círculo teórico donde ocurre el contacto ideal entre dientes. Su

diámetro se denota como d0, y está relacionado con el módulo m y el número de dientes Z por la

expresión:
m =

d0
Z

(2.9)

El módulo representa el tamaño del diente (en mm) y debe ser idéntico en todos los engranajes

que engranan entre sí, siendo un parámetro normativo fundamental en el diseño y fabricación.

Otros elementos relevantes son la circunferencia exterior, que delimita el extremo superior de

los dientes, y la circunferencia de fondo, que marca el límite inferior, el paso circular pc que es el

ancho entre un diente y el hueco siguiente medido sobre la circunferencia primitiva. El diente en sí se

compone de la cara, el flanco y el fondo, zonas que deben estar perfiladas de forma que aseguren un

contacto suave y continuo [18].

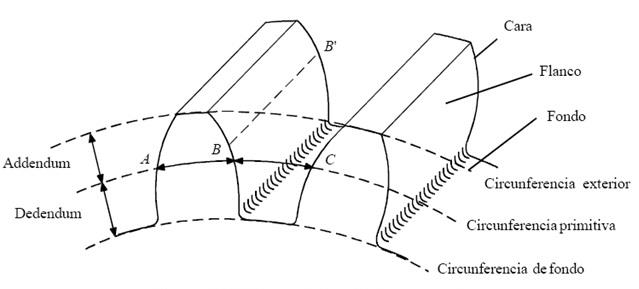
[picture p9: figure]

Figura 2.6: Nomenclatura general de engranajes

Además, la línea de presión define la dirección en que se transmite la fuerza entre dientes y

debe pasar siempre por el punto primitivo, es decir, el punto de tangencia entre las circunferencias

primitivas de los engranajes en contacto.

Estos conceptos geométricos constituyen la base para un análisis riguroso del funcionamiento

de los engranajes y permiten garantizar una transmisión mecánica precisa y confiable.

2.3.2 Tren de engranajes planetarios

Los trenes de engranajes planetarios son sistemas de transmisión en los que al menos un

engranaje denominado planeta gira sobre su propio eje mientras simultáneamente rota en torno a otro

eje central. Este tipo de tren se compone típicamente de tres elementos: el sol o engranaje central, los planetas o satélites que giran y orbitan alrededor del sol, el portador, carrier, o portaplaneta, que

sostiene los planetas y gira junto a ellos y por último [19].

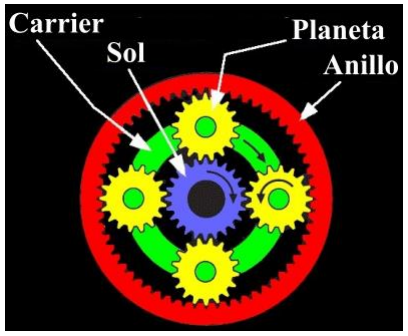
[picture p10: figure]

Figura 2.7: Elementos de un tren de engranajes planetarios

Este sistema permite una alta compacidad y eficiencia en la transmisión de potencia. En el

caso del diseño de nuestro actuador, buscamos con este sistema un incremento de torque mediante la

redistribución de velocidades angulares entre los elementos móviles. El principio físico fundamental

que explica este aumento de torque es la conservación de la potencia mecánica. Recordemos que la

potencia de un sistema rotacional se define como:
Pm = τω | (2.10)

En condiciones ideales (sin pérdidas), la potencia de entrada es igual a la de salida, es decir:

τinωin = τoutωout | (2.11)

De esta igualdad se deduce que, cuando un tren planetario reduce la velocidad angular en la

salida (ωout < ωin), el torque aumenta de manera proporcional (τout > τin). Así, al sacrificar

velocidad se obtiene un incremento directo en el torque disponible, manteniendo constante la potencia

transmitida.

Para comenzar con el diseño de un engranaje planetario, es necesario entender primero como

las velocidades tangenciales y angulares se relacionan en el cálculo de cada engranaje.

Figura 2.8: Velocidades tangenciales de un engranaje en un punto central y exterior

Recordando las secciones anteriores y observando la Figura 2.8, podemos ver que la velocidad

tangencial en el centro y el exterior de un engranaje cualquiera serán:

vcentro = rω | (2.12)
vexterior = 2vcentro | (2.13)

Por ende, para un sistema de engranajes planetarios típico de 3 planetas como se muestra en la

Figura 2.9. Podemos deducir que la velocidad de salida del carrier o porta planeta vc
| (que normalmente

se ubica en el centro de un planeta) y la velocidad tangencial del sol vs
son,
vc = ωc(rs + rp) | (2.14)
vs = ωsrs | (2.15)

Figura 2.9: Velocidades tangenciales y radios de un engranaje planetario de 3 planetas

Donde rp corresponde al radio del planeta. Pero también sabemos que en el punto donde

impacta el engranaje solar, al igual como deducimos anteriormente, la velocidad tangencial es 2 veces

la del carrier.
vs = ωsrs = 2vc = 2ωc(rs + rp) | (2.16)

Luego, si se busca una relación entre la velocidad de salida con la de entrada (carrier con sol

respectivamente) se obtiene,

ωs
ωc

=

2rs+2rp
rs

(2.17)

Sin embargo, si se observa detenidamente la Figura 2.9 podemos derivar el radio de un planeta

a partir del radio del anillo de la siguiente manera,
rr = rs + 2rp | (2.18)
2rp = rr − rs | (2.19)

Donde se obtiene finalmente la siguiente relación de transmisión de velocidad

ωs
ωc

=

2rs+rr−rs rs
= 1 +
rr rs | (2.20)

Para continuar, es necesario expresar la relación anterior en función del número de dientes de

los engranajes. Esto se fundamenta en la condición de engrane, la cual establece que el paso circular

pc debe ser el mismo para todos los engranajes en contacto:

pc =

πds Zs
=
πdr Zr | (2.21)

Finalmente, simplificando obtenemos la relación de transmisión i,

i =

ωs ωc
= 1 +

rr rs
= 1 +
Zr Zs | (2.21)

Cabe destacar que una condición poco considerada en los diseños de engranajes planetarios es

que el número de dientes entre anillo y sol sobre el número planetas Np debe ser un número entero,

asegurando así una correcta simetría en el espacio disponible.

Zr+Zs
Np
= N° entero | (2.22)

Todas estas condiciones nos servirán en un futuro para el diseño de nuestro actuador basado

en una transmisión de potencia con engranajes planetarios.

### 2.4. Protocolo de comunicación CAN

2.4.1 Protocolos de comunicación serial

Los protocolos y estándares de comunicación serial son ideales para dispositivos digitales o

mixtos (analógico-digitales), especialmente con microcontroladores. A diferencia de las

comunicaciones en paralelo, los buses seriales utilizan menos pines para intercambiar información entre múltiples dispositivos como se evidencia en la Figura 2.10. Aunque son más lentos que las

opciones en paralelo, su velocidad es suficiente para la mayoría de circuitos integrados y dispositivos,

permitiendo el envío de comandos y datos eficientemente.

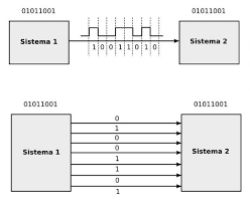
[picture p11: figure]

Figura 2.10: Transmisión de datos serial (superior) y paralela (inferior)

La comunicación serial se puede clasificar en síncrona y asíncrona, la primera requiera una

fuente de reloj común para enviar datos sincronizadamente (según el canto del reloj), la segunda en

cambio no requiere una fuente de reloj común entre el transmisor y receptor, ambos lados funcionan

con relojes independientes. En general los protocolos de comunicación serial más comunes son:

- SPI: De tipo síncrona, usa cuatro líneas (MOSI, MISO, SCK y SS), con un maestro

que controla el reloj y varios esclavos que responden cuando son seleccionados. Es

rápido y confiable, aunque requiere más cables y depende totalmente del maestro.

- I2C: Comunicación síncrona de dos hilos (SDA y SCL) que admite múltiples maestros

y esclavos, cada uno con dirección propia. Simplifica el cableado y la interconexión,

pero es más lento que SPI por el proceso de enmarcado.

- UART/USART: Comunicación serial punto a punto que utiliza TX y RX; en UART

es asíncrona y en USART puede ser también síncrona. Es sencilla y flexible en

velocidad de transmisión, pero solo conecta dos dispositivos a la vez.

- CAN: Protocolo serial asíncrono diseñado para aplicaciones robustas en tiempo real,

especialmente en entornos industriales y automotrices. Utiliza solo dos líneas (CAN_H y CAN_L) para transmitir mensajes basados en identificadores en lugar de direcciones,

lo que permite que múltiples nodos compartan el bus y determinen la prioridad de

forma automática. Es altamente confiable frente a interferencias eléctricas y permite la

comunicación eficiente entre numerosos dispositivos con un cableado reducido.

Para aplicaciones robóticas, aeronáuticas y automotrices de alto estándar, donde se requiere

estar comunicándose en tiempo real con diferentes sensores, motores, periféricos y ser robusto ante

ruido electromagnético, el protocolo dominante en el mercado por creces es el Controller Area

Network (CAN), en la sección siguiente se estudiará en detalle su funcionamiento.

2.4.2 Capa física del protocolo CAN

El protocolo CAN posee una topología del tipo bus, es decir diversos dispositivos se pueden

conectar a un mismo par de cables, llamados CAN-H y CAN-L, y así todos ser parte de una misma

red, como se muestra en la Figura 2.11 extraída del módulo SN65HVD230.

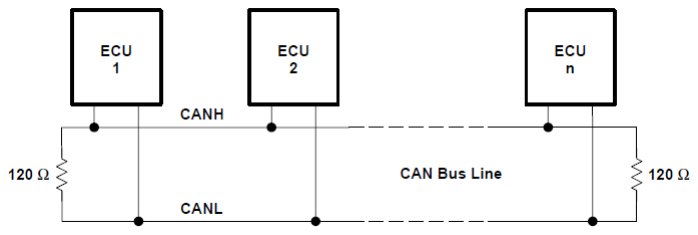
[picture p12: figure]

Figura 2.11: Topología típica de CANbus extraída del datasheet del modulo SN65HVD230

A pesar de poseer una topología simple, no todos los microcontroladores son capaces de

manejar este protocolo, debido a que se necesita un controlador dedicado de CAN. Un sistema CAN

típico se compone de 2 elementos básicos [20].

- Controlador: Gestiona la trama de datos, verifica errores en la transmisión propia o de otros

nodos, así también la detección de colisiones.

- Transmisor/Receptor: También llamado transceptor de CAN. Este módulo se encarga de la

codificación y decodificación de los mensajes en el bus, sincronización, control de los niveles

de la señal o control de acceso al medio llamado arbitraje.

Tanto el controlador como el transceptor de CAN son modulos independientes, pero en conjunto

forman un solo dispositivo (ver Figura 2.12), el cual se llama nodo. Cada nodo puede enviar mensajes y cualquiera lo puede recibir ya que están todos conectados al mismo bus, sin embargo, como se ve

en la sección siguiente cada mensaje al inicio lleva un identificador de nodo (node ID), de esta manera

los dispositivos pueden descartar el mensaje si no coincide con su node ID o bien leerlos si coincide

[20].

Figura 2.12: Componentes de un nodo (dispositivo) conectado a un bus de CAN (datasheet modulo SN65HVD230).

2.4.3 Descripción del protocolo CAN y envío de datos

Una de las mayores ventajas del protocolo CAN es su alta inmunidad al ruido

electromagnético, razón por la cual se emplea ampliamente en la industria automotriz, donde los

cables suelen recorrer grandes distancias cerca de bobinas, altavoces y sensores. A diferencia de otros

protocolos seriales que podrían corromperse fácilmente en estas condiciones, CAN utiliza transmisión

en modo diferencial, lo que significa que la información se transporta mediante dos señales de igual

magnitud pero en direcciones opuestas (CAN_H y CAN_L).

El receptor no mide cada línea respecto a tierra, sino la diferencia entre ambas. Cuando

CAN_H y CAN_L mantienen el mismo nivel (por ejemplo, 2,5 V cada una), el bus se interpreta en

estado recesivo (lógico “1”). En cambio, cuando se genera una diferencia significativa (CAN_H

aumenta y CAN_L disminuye), se obtiene un estado dominante (lógico “0”) [20]. Este principio,

mostrado en la Figura 2.13, permite que el bus distinga con fiabilidad los niveles lógicos incluso en

presencia de ruido, ya que las interferencias afectan a ambas líneas de igual manera y se cancelan al

compararlas.

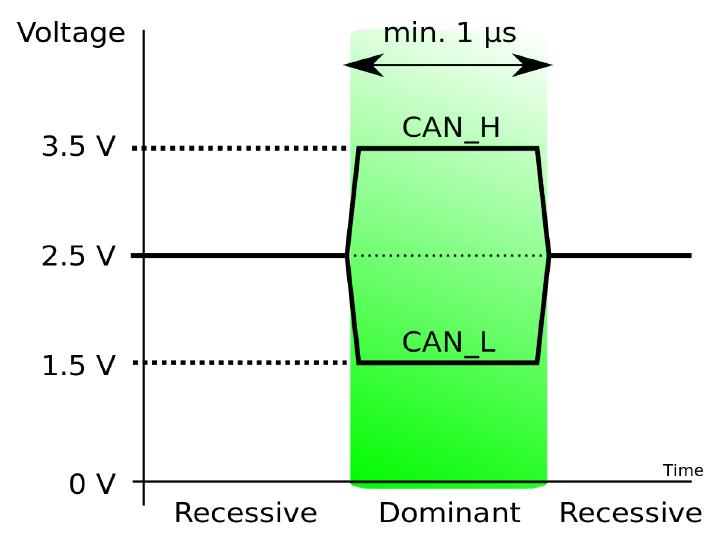
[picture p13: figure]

Figura 2.13: Funcionamiento de 2 estados lógicos en protocol CAN, recesivo 1 y dominante 0 (A. Martínez Requena, "Introducción a CAN bus: Descripción, ejemplos y aplicaciones de tiempo real").

Los mensajes CAN están estructurados en varias tramas de datos garantizando una comunicación

robusta y priorizada entre nodos (ver Figura 2.14) [20].

1. Bit de inicio (SOF - Start of Frame). Un bit dominante marca el inicio de la transmisión,

sincronizando todos los nodos del bus antes de enviar datos.

2. Campo de identificador (ID) y RTR. El identificador (11 bits en formato estándar, 29 bits en

formato extendido) determina la prioridad de la trama: valores más bajos tienen mayor

prioridad debido a su mayor cantidad de bits dominantes al inicio. Incluye un bit RTR (Remote

Transmission Request), que diferencia entre una trama de datos (0) y una solicitud remota (1).

3. Campo de control. Contiene 6 bits, 2 bits reservados (generalmente dominantes) y 4 bits DLC

(Data Length Code), que indican el tamaño del campo de datos.

4. Campo de datos. Transporta la información útil, con un tamaño variable según el DLC. CAN

admite hasta 8 bytes por trama, optimizando la eficiencia en transmisiones cortas.

5. CRC (Cyclic Redundancy Check). Un código de 16 bits (incluyendo un bit delimitador

recesivo) que permite a los receptores detectar errores en los datos recibidos. Si hay

discrepancia, la trama se descarta y se solicita retransmisión.

6. ACK (Acknowledgment). 2 bits (incluyendo delimitador) de reconocimiento, los cuales

confirman recepción correcta.

7. EOF (7 bits recesivos): Marca el fin de la trama y libera el bus para nuevas transmisiones.

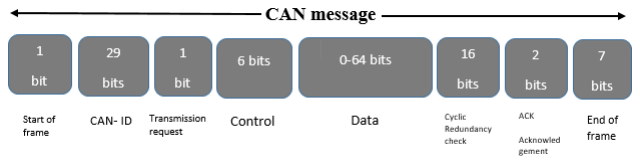
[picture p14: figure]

Figura 2.14: Trama clásica de datos CAN

Como se pudo ver, el manejo de errores en CAN con su sistema de nodos y la protección

contra ruido, convierten al protocolo en un sistema robusto para aplicaciones de altas exigencias.

Sin embargo, lo que destaca al protocolo en usos como la robótica, automóviles y aeronáutica,

es la capacidad de manejar múltiples dispositivos a una velocidad de transmisión muy alta y protegida,

sin la necesidad de mucho material, mas bien con el simple uso de un par de cables trenzados.

### 2.5. Modelación e impresión 3D

La impresión 3D, una tecnología revolucionaria de fabricación por adición permite crear

objetos tridimensionales superponiendo capas de material de manera precisa y eficiente. Surge en los

años 80 con los primeros desarrollos de estereolitografía y el formato STL, pero fue en las últimas dos

décadas cuando se popularizó gracias a la reducción de costos y la mejora en accesibilidad. Hoy, esta

tecnología se usa en campos tan diversos como la medicina, la ingeniería y el diseño industrial,

destacando por su capacidad para producir prototipos rápidos y piezas personalizadas sin necesidad

de costosas herramientas de moldeo.

El proceso comienza con el modelado 3D mediante software CAD, donde se diseña la pieza

con las dimensiones y geometrías necesarias. Una vez definido el modelo, un software de laminado

(o slicer) divide el objeto en capas y genera las instrucciones para la impresora. Entre las técnicas más

comunes está el modelado por deposición fundida (FDM/FFF), donde un filamento termoplástico se

extruye capa por capa como se muestra en la Figura 2.15, ideal para prototipos funcionales por su bajo

costo y versatilidad. Otras técnicas, como el sinterizado láser (SLS), permiten mayor precisión y

resistencia, aunque con equipos más costosos.

Figura 2.15: Proceso de modelado por deposición fundida

Para construir un robot bípedo, la impresión 3D es fundamental. Permite crear piezas ligeras,

resistentes y a medida, optimizando el diseño mediante pruebas rápidas y correcciones inmediatas: si

un componente falla, basta reimprimirlo en horas. Además, su versatilidad de materiales (PLA, nylon,

etc.) permite ajustar flexibilidad y resistencia según cada pieza. Esta tecnología no solo acelera el

desarrollo y abarata costos, sino que también simplifica la fabricación de prototipos complejos, desde

una pierna del robot, hasta la caja reductora de engranajes planetarios, convirtiéndola en una

herramienta clave para la robótica actual.

### 3. Solución propuesta

### 3.1. Problemática actual y sistema para proponer

El diseño y construcción de robots de alta dinámica enfrenta múltiples desafíos:

- Alto costo de componentes.
- Escasa documentación disponible a nivel global.
- Desarrollos aún en etapas tempranas, sin soluciones maduras.
- Poco incentivo para innovar, debido al liderazgo de instituciones académicas y privadas.

Si bien los avances recientes en robótica se han centrado principalmente en software como el

estudio de trayectorias, la visión artificial o los modelos de aprendizaje automático y en la mecánica

con materiales ligeros y rígidos que mejoran la eficiencia estructural, el desarrollo de actuadores

continúa siendo un campo rezagado. Sin actuadores capaces de combinar alta densidad de torque, bajo

peso y retroalimentación precisa, resulta imposible materializar los algoritmos de locomoción más

avanzados ni responder adecuadamente a las exigencias de la robótica dinámica. Los actuadores

tradicionales, como servomotores, motores paso a paso o motores industriales, no ofrecen el

desempeño requerido debido a su exceso de peso, volumen y limitaciones de respuesta.

Frente a esta problemática, el eje central de esta memoria es el diseño y construcción de actuadores

robóticos propioceptivos Quasi Direct Drive (QDD), capaces de integrarse en sistemas de locomoción

dinámica. Para validar su desempeño, dichos actuadores se implementan luego en un prototipo bípedo

modular denominado B1P0 (Biped Penquista), concebido como plataforma experimental para ensayar

y caracterizar simultáneamente múltiples actuadores. Como se muestra en la Figura 3.1, el diseño de

B1P0 contempla una arquitectura en niveles: la base inferior destinada a sistemas de potencia y

baterías, el nivel intermedio para electrónica de control y procesamiento central, y el nivel superior

para cargas ligeras como cámaras o sensores LiDAR. Esta disposición modular facilita la

escalabilidad, el mantenimiento y futuras mejoras, asegurando un entorno de prueba versátil y robusto.

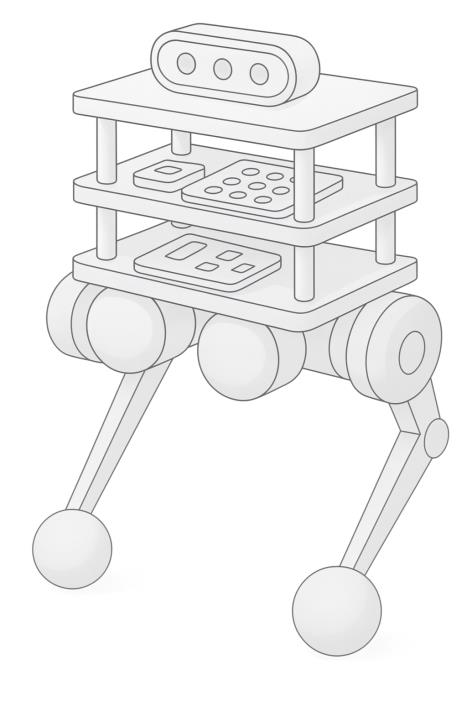
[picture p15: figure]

Figura 3.1: Dibujo conceptual de robot B1P0

La elección de un robot bípedo responde a su capacidad para desenvolverse en entornos de alta

dinámica particularmente aquellos diseñados para el ser humano donde los sistemas con ruedas

resultan poco eficientes frente a terrenos irregulares, escaleras o espacios confinados [7] [8]. Además,

B1P0 incorpora articulaciones que simulan el comportamiento de rodillas hacia atrás, tal como se

fundamenta en estudios previos [4]. Esta configuración no solo mejora la eficiencia de locomoción al

reducir la dependencia del torque en la cadera, sino que también facilita la combinación de funciones

de propulsión y elevación, favoreciendo la estabilidad y la adaptabilidad frente a variaciones del

terreno.

De esta manera, el sistema propuesto permite cumplir con el objetivo central de este trabajo, el

cual es: diseñar, construir y validar actuadores propioceptivos QDD de bajo costo y alta eficiencia,

dentro de una plataforma bípedo modular que asegure condiciones reales de operación para su correcta

evaluación.

### 3.2. Actuadores propuestos

3.2.1 Quasi Direct Drive (QDD)

Los actuadores Quasi-Direct Drive (QDD) se han convertido en la solución preferida para la

robótica dinámica en las principales universidades del mundo. La razón es clara: ofrecen el mejor

equilibrio entre torque y velocidad, manteniendo la capacidad de sentir fuerzas externas, algo esencial

para robots ágiles.

El robot Stanford Doggo [21] es un excelente ejemplo de esta tecnología. Utiliza una

transmisión por correa con relación 6:1, lo que le permite lograr saltos excepcionales y movimientos

dinámicos. Este diseño le dio una ventaja del 22% en agilidad vertical sobre robots anteriores. Lo más

interesante es que todo el robot fue diseñado para ser accesible, con un costo menor a $3000 USD y

usando herramientas comunes.

En la misma línea, el MIT Mini Cheetah emplea también una relación 6:1 (usando engranajes

planetarios) [9], demostrando la efectividad de esta configuración para robots cuadrúpedos que

requieren una locomoción ágil y capacidad de salto. Este robot ha establecido nuevos estándares en

movimientos dinámicos y recuperación de caídas.
Por otro lado, el trabajo presentado en la Universidad de California en Los Ángeles muestra

otra variante del QDD usando engranajes cicloidales con relación 10:1 [22]. Esta solución es

particularmente robusta para aplicaciones donde se esperan cargas pesadas e impactos fuertes, como

en robots que deben soportar caídas. El sistema incluye un estimador de torque basado en redes

neuronales para compensar las no linealidades propias de este tipo de engranajes.

Estos ejemplos demuestran que el QDD no es una solución única, sino un concepto flexible que

puede adaptarse a diferentes necesidades. Tanto la versión de correa (6:1) como la cicloidal (10:1), o

los planetarios del MIT comparten características clave:

- Reducciones moderadas (entre 5:1 y 10:1)
- Baja inercia reflejada
- Capacidad de retroalimentación natural (backdrivability)
- Diseños compactos y eficientes

La elección entre estas variantes depende del balance específico que se busque entre torque,

velocidad y robustez. En todos los casos, desde Stanford [21] hasta el MIT [9] y el actuador cicloidal de UCLA [22], los resultados confirman que estas son las soluciones que están permitiendo a los

robots más avanzados del mundo realizar movimientos dinámicos y complejos.

3.2.2 Actuador propioceptivo

La propiocepción, ese "sexto sentido" que nos permite movernos con precisión sin depender

de la visión, es fundamental para la robótica dinámica. En sistemas biológicos, esta capacidad surge

de mecanorreceptores especializados que monitorean constantemente la posición y movimiento de las

articulaciones. Casos clínicos como el de Ian Waterman, quien perdió esta capacidad y quedó

severamente limitado en sus movimientos, demuestran su importancia fundamental [23].

La solución propuesta implementa esta capacidad mediante encoders magnéticos de alta

resolución, específicamente el modelo MA702 incluido en la placa electrónica ODrive S1 [24]. Estos

sensores proporcionan una precisión angular de hasta 12 bits, actuando como los propioceptores

artificiales del sistema robótico. Su diseño sin contacto los hace particularmente resistentes para

aplicaciones dinámicas donde vibraciones y cargas mecánicas son frecuentes.

El controlador ODrive S1 integra esta información sensorial con un potente sistema de control

para motores BLDC. Sus características clave incluyen: capacidad para manejar hasta 40 [A]

continuos, soporte para múltiples modos de control (torque, velocidad y posición), y una arquitectura

que permite actualizaciones en tiempo real a 8 [kHz] [24]. La combinación de estos componentes crea

un sistema de retroalimentación propioceptiva completo, donde la electrónica de control está

físicamente integrada con el actuador, minimizando latencias y mejorando la respuesta dinámica.

Esta implementación mantiene los principios esenciales de los sistemas biológicos -monitoreo

autónomo y continuo del estado mecánico mientras aprovecha las ventajas de la electrónica moderna.

### 3.3. Diseño conceptual del sistema robótico

3.3.1 Diagrama conceptual de actuador QDD

El actuador Quasi Direct Drive (QDD) propuesto integra en un mismo módulo los elementos

necesarios para generar y controlar el movimiento de manera eficiente y propioceptiva. La

arquitectura del sistema se ilustra en la Figura 3.2.

El actuador recibe energía desde una fuente de corriente continua (DC), la cual alimenta al

driver ODrive S1, encargado de controlar el motor BLDC trifásico mediante las fases A, B y C. A

través de una señal digital de control proveniente de un microcontrolador central, el ODrive con el firmware en su versión más reciente 0.6.11, ejecuta de forma precisa los lazos de posición, velocidad

y torque, además de rutinas de calibración automática y protocolos de comunicación en tiempo real

para la operación de múltiples actuadores en simultáneo.

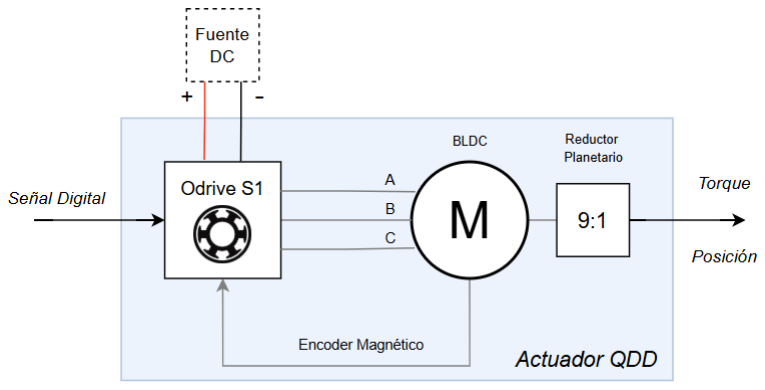
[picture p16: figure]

Figura 3.2: Arquitectura interna del actuador propioceptivo QDD

La propiocepción se obtiene mediante un encoder magnético montado frente al rotor, el cual

detecta el campo magnético rotatorio a través de sensores de efecto Hall. El procesamiento de estas

señales permite calcular en tiempo real el ángulo absoluto del eje [25].

De este modo, el actuador QDD entrega a la salida el torque y la posición requeridos para la

locomoción dinámica, constituyéndose en el núcleo operativo de la plataforma B1P0.

3.3.2 Arquitectura eléctrica de robot B1P0

La Figura 3.3 muestra la arquitectura eléctrica del robot B1P0, organizada para garantizar un

suministro de energía estable y una adecuada separación entre el control de baja y alta complejidad.

La batería principal alimenta a un sistema de monitoreo y distribución de potencia, encargado

de entregar los niveles adecuados de tensión a cada subsistema y medir los consumos de potencia de

ellos.

El microcontrolador recibe datos de sensores como el IMU (Unidad de Medición Inercial) y

otros periféricos, gestionando tareas de baja complejidad pero de alta velocidad de respuesta, tales

como la lectura de posiciones y velocidades angulares, y envío de señales de control a los actuadores.

Solo la información procesada y relevante es transmitida a la CPU, que actúa como el centro de alto

nivel del sistema.

Figura 3.3: Diagrama eléctrico del robot B1P0

La CPU, posiblemente implementada en una plataforma como Raspberry Pi, se encarga de

procesar sensores más complejos, como cámaras de profundidad o sistemas LiDAR, y de ejecutar un

sistema operativo que permita la futura interacción con el usuario mediante una interfaz gráfica.

Además, está destinada a correr algoritmos avanzados de control de estabilidad, locomoción bípeda y

modelos de inteligencia artificial, funciones críticas para aprovechar el potencial dinámico del robot

en labores humanas de alto riesgo.

Las líneas negras en el diagrama corresponden a la distribución de potencia, mientras que las

líneas amarillas indican los canales de comunicación que integran la información entre todos los

subsistemas. Además, como se planteó en un principio del capítulo, la solución propuesta es un robot

bípedo de 6 grados de libertad (6DoF), lo cual se evidencia en el conjunto de 3 actuadores que

conforman una sola pierna.

3.3.3 Condiciones de diseño

El desarrollo del robot bípedo B1P0 se define a partir de las exigencias propias de la

locomoción dinámica y de los aprendizajes obtenidos de proyectos desarrollados en universidades

líderes como el MIT, Stanford, entre otras. A continuación, se detallan las principales condiciones de

diseño y su justificación.

Requisitos para el robot B1P0

- Peso total entre 6–8 [kg] con baterías. Un peso moderado facilita la estabilidad y la

capacidad de sumar cargas livianas. Proyectos como el Stanford Doggo [21] o el Mini Cheetah

[1] priorizan estructuras ligeras para maximizar la agilidad vertical y rápidos movimientos.
- Capacidad para caminar en distintos terrenos. En entornos de rescate, minería, plantas

industriales o espacios urbanos, las irregularidades del suelo hacen inviable el uso de robots

con ruedas. El robot B1P0, al tener dos patas le permite mejorar su adaptabilidad ante los

terrenos mencionados reduciendo riesgos para operadores humanos.

- Soporte de cargas livianas. La arquitectura modular del B1P0, como se ilustra en la Figura

3.1, destina el nivel superior a cargas como cámaras, sensores LiDAR o herramientas ligeras.

Esta característica está alineada con el diseño del robot Mithra, que distribuye masas de forma

proximal para reducir momentos de inercia en las extremidades [11], asegurando estabilidad

pese al agregado de dispositivos.

- Capacidad para subir y bajar escaleras. Diseños como el Stanford Doggo han demostrado

que transmisiones de baja reducción mejoran la agilidad vertical [21], mientras que el uso de

QDD en el MIT Mini Cheetah permite recuperarse de caídas y ejecutar movimientos

explosivos como saltos o trotes [9]. Estas evidencias respaldan la necesidad de que B1P0

cuente con actuadores capaces de generar impulsos suficientes para superar escalones u

obstáculos.

- Articulaciones inspiradas en rodillas hacia atrás. Tal como se fundamenta en estudios de

Haberland y Kim [4], la orientación de rodillas hacia atrás reduce la dependencia del torque

de cadera y mejora la eficiencia del costo mecánico de transporte en un 80% de los casos

evaluados. Aunque en B1P0 se implementan tobillos modificados que replican este principio,

se mantiene la misma ventaja funcional de propulsión y elevación.

Condiciones para el actuador QDD propioceptivo

- Peso máximo de 800 [g] por actuador incluyendo drivers. Considerando que el robot debe

poseer 6 actuadores (6 grado de libertad), el peso total será aproximadamente (incluyendo solo

estos) 4,8 [kg], dejando margen de carga para baterías, sensores y restos del cuerpo como

piernas.

- Relación de transmisión de 9:1 con engranaje planetario. Universidades como Stanford y

UCLA han demostrado que reducciones moderadas (entre 5:1 y 10:1) maximizan la agilidad

y la backdrivability en sistemas QDD [21][22]. La elección de 9:1 en el robot B1P0 prioriza

un aumento significativo de torque sacrificando levemente la velocidad de respuesta ya que

los usos del robot no están pensados para saltos rápidos o carreras, además se usa un reductor

basado en engranajes planetarios por su fácil prototipado y diseño.

- Torque máximo objetivo de 16 [Nm]. El torque requerido se determina considerando la

capacidad del motor sin reductor, la cual según estudios previos fue de un torque máximo de

1.78 [Nm], por lo tanto, este nuevo torque objetivo debe ser nueve veces más que el anterior.

Además, este requisito de torque debe cumplir con la capacidad de levantar al menos el peso

del robot (6-8 [kg]) más un 10% (movimientos de impulso).

- Propiocepción integrada mediante encoders magnéticos. El uso de encoders magnéticos de

alta resolución ha sido un estándar en todos los proyectos de diversas academias

internacionales. En este trabajo se emplean encoders basados en sensores de efecto Hall,

capaces de medir ángulos absolutos en tiempo real y robustos frente a vibraciones.

3.3.4 Lista de materiales

En base a las consideraciones de diseño anteriores, se propone la siguiente lista de materiales para el

desarrollo de ambos sistemas (actuador y robot).

Tabla 3.1: Lista de materiales y su uso para el actuador QDD propioceptivo

Material | Uso
Brushless motor Eaglepower 90KV LA8308 | Motor DC principal (eje solar)
Odrive S1 | Driver de control y monitoreo de parámetros
Rodamiento de bolas 32x15x8mm (x18) | Soporte de engranajes planetarios
Rodamientos de bolas 35x44x5mm (x6) | Soporte de portaplanetas
Imán radial de neodimio 6x2.5mm | Envío de posición mediante encoder magnético
Filamento Creality PLA+ (2kg) | Fabricación de carcasa y reductores en 3D
Pernos y tuercas M2, M3 y M4 | Montaje estructural del actuador
Golillas de presión M4 y M3 | Fijación de pernos
EP-2 Lithium Vistony | Grasa blanca de litio para lubricar engranajes

Tabla 3.2: Lista de materiales y su uso para el resto del robot B1P0

Material | Uso
Placas de fibra de carbono 200x250x2mm (x2) | Placa soporte niveles inferior y superior
Placas de fibra de carbono 200x250x1mm (x1) | Placa soporte nivel intermedio
Tubos de fibra de carbono 12x10x500mm (x3) | Vigas estructurales verticales
Tubos de fibra de carbono 10x8x500mm (x2) | Vigas estructurales cruzadas
Filamento Creality PLA+ (1kg) | Impresión de restos del cuerpo y soportes.
Microcontrolador Teensy 4.1 | Control y monitoreo de bajo nivel
Raspberry Pi 5, 16GB RAM | CPU principal para procesamiento avanzado
SparkFun OpenLog Artemis | Sensor principal IMU
RealSense D435i | Cámara de profundidad para trayectorias
Sistema de montaje PCB y periféricos | Integración y conexión de la electrónica
Conectores JST GH-4Pines | Comunicación entre drivers y microcontrolador
Set de pernos CORGI M2, M3 y M4 1080Pcs | Montaje estructural general del robot
Set de insertos M2, M2.5, M3 y M4 1400Pcs | Refuerzo de uniones roscadas en piezas 3D
Set de tornillos Zonsanta M2, M3 y M4 460Pcs | Fijación de piezas 3D
Polea dentada GT2 diámetro 19mm | Transmisión de torque mediante correas
Correa dentada GT2-6 500mm | Transmisión de movimiento hacia extremidades

### 4. Diseño en detalle

En este capítulo se describen los aspectos técnicos que materializan la solución propuesta,

abordando desde el diseño de la caja reductora y las estrategias de control y comunicación, hasta el

desarrollo del algoritmo y el modelo 3D del robot bípedo B1P0.

### 4.1. Diseño de caja reductora

Como se ha estudiado y definido antes, el sistema de transmisión de potencia mecánica

escogido es un diseño de caja reductora de engranajes planetarios, utilizando un tipo de engranajes

rectos por su facilidad de diseño y prototipado.

Del marco teórico, se obtuvo la siguiente relación de transmisión i para un sistema de

transmisión planetaria.
i = 1 +

Zr
Zs

(4.1)

De las condiciones de diseño, sabemos que se debe reducir la velocidad 9 veces, es decir por

cada 9 vueltas en el eje solar, a la salida (porta planeta) se debe dar 1 vuelta (relación 9:1). Luego, el

módulo de un engranaje está dado por la ecuación 4.2.
m =

d0
Z

(4.2)

Ya que el motor escogido tiene una configuración de rotor Outrunner y cuenta con un diámetro

de 92 [mm] según su hoja de datos, podemos aprovechar este espacio para construir el sistema

planetario de manera de optimizar el torque final. Por ende, si se considera un módulo típico para este

tipo de engranajes de 1 [mm] y un diámetro primitivo de 96 [mm]. Se puede encontrar el número de

dientes inicial para el anillo o corona de la siguiente manera,
Zr =

d0
m

=

96
1
= 96 | (4.3)

Reemplazando el número de dientes en la ecuación de relación de transmisión se obtiene,
9 = 1 +
96 Zs | (4.4)
Zs = 12 | (4.5)

Luego, usando la misma relación del número de dientes con el radio de un engranaje, se puede

derivar el número de dientes de cada planeta mediante el siguiente reemplazo,

rr = rs + 2rp ⟺ Zr = Zs + 2Zp | (4.6)
96 = 12 + 2Zp | (4.7)
Zp = 42 | (4.8)

Luego, se valida su relación geométrica para que cada engranaje esté simétricamente espaciado

mediante la siguiente condición (2.22).

Zr+Zs
Np

=

96+12
3
= 36 | (4.9)

Al ver que se obtiene un número entero, se valida esta condición geométrica y se concluye que

el reductor de engranajes planetarios queda conformado por los siguientes parámetros de diseño.

- Número de dientes del anillo (Zr
): 96
- Número de dientes del sol (Zs): 12
- Número de dientes de cada planeta (Zp): 42
- Módulo (m): 1[mm]
- Relación de transmisión (i): 9

Con estas consideraciones se puede continuar con el diseño 3D del sistema.

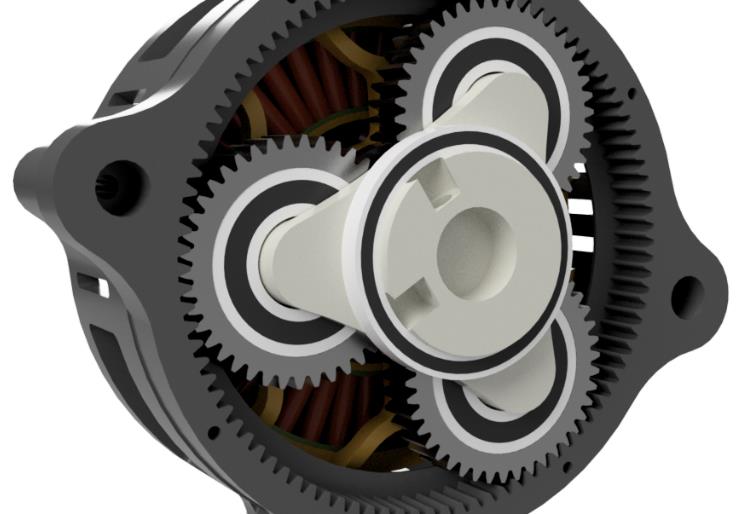
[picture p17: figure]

Figura 4.1: Tren de engranajes planetarios con porta planeta y rodamientos

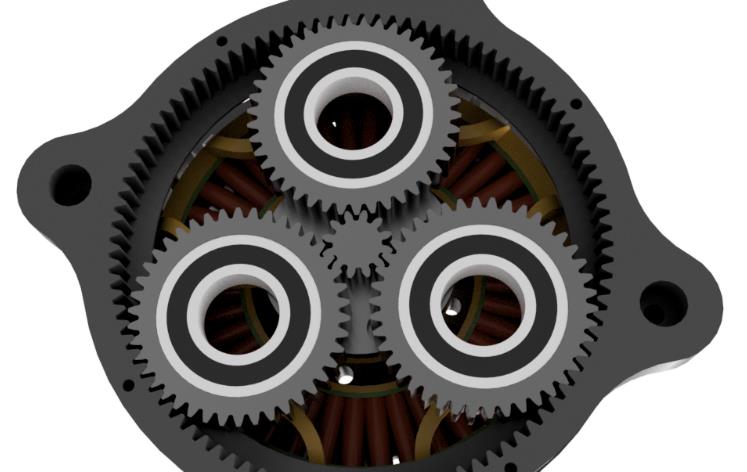
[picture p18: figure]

Figura 4.2: Tren de engranajes planetario sin porta planeta

En las Figuras 4.1 y 4.2 se muestran los resultados del diseño en 3D del sistema planetario.

Como se puede apreciar, se optó por un diseño tipo pancake (utilizado comúnmente en la robótica

académica). Este diseño se caracteriza por ir “apilando” subsistemas desde el eje de giro inicial, hasta

el final. Por esto mismo, detrás de todo se puede apreciar el motor BLDC con sus respectivos

devanados (color rojo). En el eje del motor se acopla el engranaje solar y de esta manera se va

transmitiendo el movimiento hasta llegar al eje final (porta planeta).

### 4.2. Estrategias de control

ODrive implementa una arquitectura de lazos de control en cascada compuesta por

controladores de posición, velocidad y corriente, como se muestra en la Figura 4.3. Cada lazo es de

tipo P o PI, dependiendo del nivel, y opera a distintas velocidades: el lazo de corriente (más interno)

tiene la dinámica más rápida, seguido por el de velocidad, mientras que el de posición (más externo)

opera con la dinámica más lenta [26].

Figura 4.3: Diagrama de control en lazo cerrado en cascada utilizado en Odrive S1

Aunque ODrive cuenta con múltiples modos de operación [26] orientados a diversas

aplicaciones, en el contexto de un robot desarrollado en este trabajo, los modos relevantes son:

- Modo trayectoria: Genera movimientos suaves a partir de límites definidos de velocidad,

aceleración y desaceleración. Mejora la capacidad de rechazo a perturbaciones y facilita el

tuning de los controladores.

- Modo velocidad: Permite aplicar directamente una velocidad angular al motor en [rev/s].
- Modo torque (Figura 4.4): Controla directamente el par aplicado en [Nm]. Para seguridad, este

modo incluye una limitación automática de torque basada en la velocidad.

- Modo posición: Intenta alcanzar una posición objetivo lo más rápido posible, sin considerar

transiciones suaves.

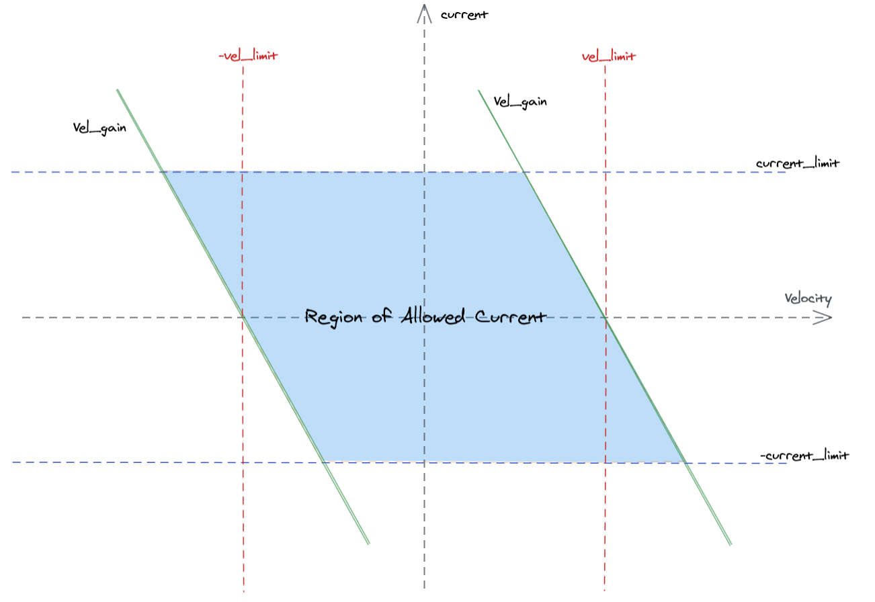
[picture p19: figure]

Figura 4.4: Región de operación del control de torque basado en límites de corriente y velocidad

La región azul de la Figura 4.4 representa la zona segura de operación, delimitada por

vel_limit, current_limit y vel_gain [26].

En cuanto a la implementación física, se utiliza un encoder magnético integrado en el ODrive

S1 (sensor MA702), el cual detecta la rotación de un imán de neodimio montado en el eje del rotor.

Para una lectura confiable del ángulo, se mantiene una distancia entre 0.5 y 3 [mm] entre el sensor y

el imán, tal como recomienda la documentación oficial [25]. Este montaje puede observarse en la

Figura 4.5.

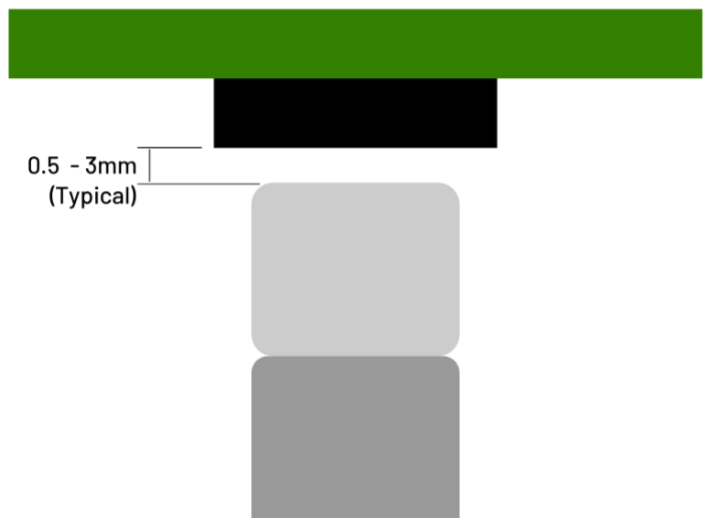
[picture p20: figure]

Figura 4.5: Espacio sugerido entre la cara cercana del imán y el circuito integrado MA702

Previo a la operación, el firmware de ODrive permite ejecutar una rutina de calibración

automática desde la Web GUI y guardarla en la memoria no volátil del hardware. Posteriormente, la

misma interfaz permite ajustar los parámetros de los controladores (Figura 4.6) y analizar

gráficamente las respuestas del sistema (Figura 4.7).

Figura 4.6: Configuración de parámetros de controladores por medio de Web GUI

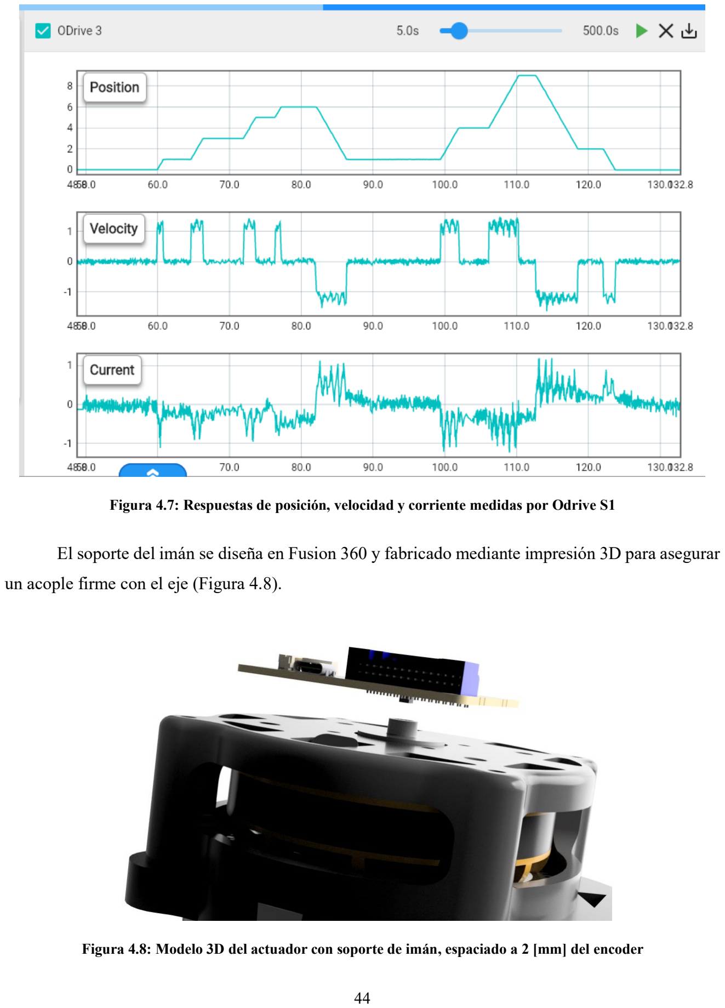
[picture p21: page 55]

Figura 4.7: Respuestas de posición, velocidad y corriente medidas por Odrive S1

El soporte del imán se diseña en Fusion 360 y fabricado mediante impresión 3D para asegurar

un acople firme con el eje (Figura 4.8).

Figura 4.8: Modelo 3D del actuador con soporte de imán, espaciado a 2 [mm] del encoder

Con el sistema calibrado, los lazos de control afinados y el encoder correctamente montado,

el sistema queda en condiciones de aceptar referencias externas y operar bajo los distintos modos de

control habilitados por ODrive.

### 4.3. Estrategia de comunicación CAN para sistema multi driver

4.3.1 Arquitectura electrónica

Esta arquitectura CAN une al Teensy 4.1 (nodo maestro) con los ODrive S1 que actúan como

nodos de potencia. El Teensy trabaja a 3.3 [V] y entrega/recibe tramas por CTX/CRX hacia un

SN65HVD230, que convierte la lógica CMOS a la señal diferencial y viceversa. El pin D del módulo

fuerza los dos bits para ser enviados sobre el bus, percatándose que CANL vaya negado; luego para

recibir, el comparador interno lee la diferencia VCAN_H − VCAN_L y entrega el bit recibido por R

(dominante o recesivo) hacia CRX (ver Figura 4.9).

En el pin 8 se fija una resistencia Rs para escoger el modo de control slope, el cual disminuye

las pendientes de subida y bajada de cada bit para minimizar la interferencia electromagnética (EMI).

Figura 4.9: Diagrama lógico del módulo SN65HVD230

Desde el módulo CAN, el par diferencial se redistribuye por la PCB a los conectores J16 de

cada driver como se muestra en la Figura 4.10. Cada ODrive integra su propio transceptor, por lo que

se conecta en paralelo al bus (solo CAN_H/CAN_L y una referencia GND). Aunque la decisión de

bit es puramente diferencial, llevar GND mantiene el modo común dentro de rango y mejora la

inmunidad frente a ruidos. Los pines 12 [V] de entrada en el conector J16 no participan del enlace

CAN ya que cada dispositivo cuenta con sus propias alimentaciones independientes, como por

ejemplo los drivers que reciben 22.2 [V] por líneas de potencia externas.

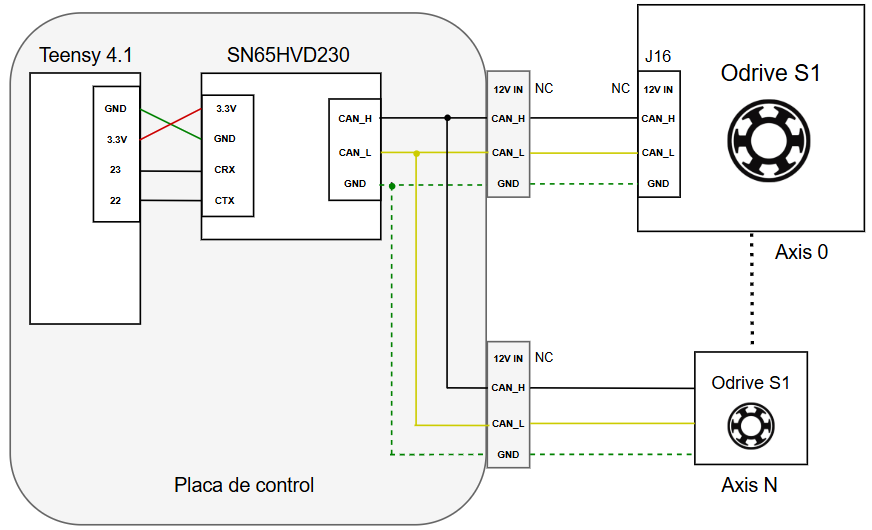
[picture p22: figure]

Figura 4.10: Diagrama electrónico de comunicación CAN

Para el cierre del enlace, el tramo físico debe quedar terminado con 120 [Ω] en cada extremo:

el módulo CAN ya aporta un terminador; el segundo se instala en el último ODrive del mazo o bien

se puede incluir la resistencia de manera externa en la PCB al final del bus. Con esta disposición, el

Teensy direcciona N drivers por su identificador CAN, mantiene el cableado de potencia y

comunicación desacoplado y deja una base escalable para el control simultáneo de todos los

actuadores.

4.3.2 Protocolo CAN en firmware Odrive

En ODrive el bus se maneja con CANSimple y un identificador estándar de 11 bits que parte

el ID en dos campos: node_id (quién) y cmd_id (qué), ver Figura 4.11. Con esto, desde el Teensy se

puede enviar de forma directa a cada driver/axis del robot B1P0 solo tres tipos de órdenes de control:

SetPosition, SetVelocity y SetTorque. Esas tres son las que realmente “mueven” un eje y,

además, reinician el watchdog del ODrive.

Figura 4.11: Trama simple de mensajes CAN

La configuración de cada driverse muestra en la Figura 4.12. El Bitrate es un parámetro crucial

en el cual todos los nodos deben compartir la misma tasa. Para B1P0 se fijó 250 [kbit/s] ya que da

margen suficiente entre cableado interno y ruido electromagnético sin penalizar la latencia de mando.

El Node ID es el identificador de cada eje que debe ser único para cada uno. Puede asignarse por

GUI/USB o vía comandos.

Figura 4.12: Configuración de interfaz CAN por medio de la Web GUI

Los mensajes cíclicos son típicos en este tipo de dispositivos para revisar estados en tiempo

real, el Heartbeat (configurado en 150 [ms]) por ejemplo, es útil para saber si el eje está “vivo”, su

estado y si terminó una trayectoria. El resto de variables importantes como Get_Encoder_Estimates

(corriente, temperatura, etc.) queda desactivado y se pide puntualmente cuando hace falta. Así el

tráfico recurrente es bajo y el bus queda libre para las órdenes Set.

Con estos 3 ajustes: tasa fija, IDs únicos y telemetría cíclica mínima el esquema CAN de B1P0

queda claro: el Teensy publica setpoints (posición/velocidad/torque) a cada node_id, los ODrive

ejecutan en lazo cerrado y devuelven Heartbeats al ritmo configurado, lo suficiente para supervisar

salud básica sin comprometer el ancho de banda del bus.

### 4.4. Algoritmo de control y monitoreo central

El control central se ejecuta en un Teensy 4.1, encargado de coordinar los seis controladores

ODrive S1 a través de un bus CAN. Para organizar esta comunicación, se implementa una estructura

de software que separa dos funciones clave:

- La gestión de los mensajes CAN de forma clara y directa.
- La lógica de control que define qué órdenes enviar y cómo reaccionar a la información

recibida.

Esta división simplifica el desarrollo, evita errores en el manejo de datos y facilita la ampliación

del sistema en el futuro.

4.4.1 Librería ODriveTeensyCAN

ODriveTeensyCAN.h es una librería desarrollada para facilitar la comunicación con

controladores ODrive usando el protocolo CANSimple. Su función es traducir, de forma automática,

las órdenes y datos del Teensy a mensajes CAN que el ODrive entiende, y viceversa. Esto evita que

el programador tenga que construir manualmente cada mensaje byte por byte o descifrar la

información recibida.

En lugar de trabajar con números y tramas CAN crudas, la librería ofrece funciones con

nombres claros, por ejemplo SetPosition() para mover un motor a una posición específica, o

RunState() para cambiar el estado de un eje. De esta manera, la programación se centra en lo que se

quiere hacer, no en los detalles del formato del mensaje.

En este sistema, la librería permite un arranque rápido y seguro de los motores manteniendo

movimientos precisos. Funciones como SetPosition() envían de forma confiable la posición

objetivo a cada motor sin tener que preocuparse por la codificación interna.

A pesar de que la librería cuenta con una serie de comandos integrados, los usados en el código

para validaciones generales son:

- odriveCAN.RunState(axis,8): Cambia un motor a modo control en lazo cerrado,

condición necesaria para que pueda seguir órdenes de movimiento como posición, velocidad

o torque.

- | odriveCAN.SetPosition(axis,position): | Ordena al motor ir a una posición

determinada. Es el comando más usado en las rutinas de prueba y simulación de caminata.

- odriveCAN.Heartbeat(hb,msg): Lee el mensaje (msg) periódico que envía cada ODrive,

obteniendo información sobre su estado y posibles fallos, una vez codificado lo almacena en

la variable hb.

Gracias a esta librería, el código principal se mantiene claro y enfocado en la lógica del robot,

mientras que el envío y recepción de mensajes CAN se maneja de forma confiable y estandarizada.

4.4.2 Lógica y funciones principales

La lógica de control y monitoreo central implementada en el firmware se basa en un flujo

estructurado de inicialización, gestión de comunicaciones y ejecución de comandos hacia los

controladores ODrive mediante el bus CAN. La Figura 4.13 ilustra de forma simplificada este flujo,

destacando las funciones principales y la interacción entre ellas.

En la etapa de inicio, el sistema configura los periféricos esenciales: interfaz CAN a 250

[kbps], puertos seriales, estructuras de datos y pines de control. Para la gestión de parámetros de cada

motor, se utiliza la estructura MotorConfig, diseñada para centralizar la configuración y facilitar el

control individual de cada eje:

// La estructura 'MotorConfig' define las propiedades de cada motor.
struct MotorConfig { | //Estructura de Configuración
uint8_t node_id; | // Node ID en el bus CAN
float pos_a; | // Posición inicial (vueltas)
float pos_b; | // Posición final (vueltas)
float current_target; | // Último objetivo enviado
unsigned long lastMoveTime; // Último cambio
unsigned long intervalo_ms; // Tiempo de espera entre movimientos
float last_position_deg; | // Última posición en grados
float last_current_A; | // Última corriente
};

Cada instancia de esta estructura almacena tanto los parámetros de control (posiciones

objetivo, límites, intervalo de ejecución) como variables para el seguimiento del estado en tiempo

real (posición y corriente leída), permitiendo que las funciones de control accedan a toda la

información relevante desde un único lugar.

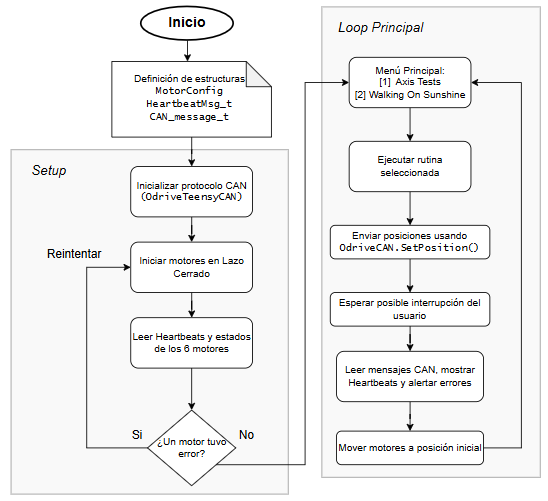
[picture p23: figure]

Figura 4.13: Diagrama de flujo para validación de actuadores integrado en robot B1P0

Una vez configurado el hardware, el sistema ejecuta la secuencia de inicialización de

motores. Mediante la función RunState, cada ODrive recibe el comando para entrar en Closed Loop

Control. Para confirmar que el cambio de estado fue exitoso y que no existen fallos, se utilizan los

mensajes Heartbeats que el ODrive transmite de forma periódica. La gestión de estos mensajes se

realiza principalmente en dos funciones:

- leerErroresCAN(): Lee todos los mensajes CAN entrantes, filtra los que correspondan a

Heartbeats y analiza el contenido para verificar si existe algún axisError o si el estado

(currentState) difiere del esperado. En caso de error, el eje se coloca en IDLE de forma

automática.

- imprimirHeartbeats(): Realiza una lectura puntual de los Heartbeats de todos los ejes,

mostrando por consola valores clave como axisError, estado actual y banderas de

procedimiento.

Durante la operación, el sistema mantiene un ciclo de lectura continua de mensajes CAN, lo que

permite reaccionar ante fallos o desconexiones en tiempo real.

Para la ejecución de movimientos, las funciones SetPosition, SetVelocity y SetTorque

envían comandos precisos a los motores, tomando como referencia los datos definidos en la

estructura MotorConfig. El retorno a la posición inicial se gestiona con

moverMotoresAPosicionInicial(), que envía repetidamente las posiciones de reposo para

garantizar que no se active el watchdog del ODrive.

El bucle principal funciona como un menú interactivo que permite seleccionar distintas rutinas

de prueba o ejecución. Durante la ejecución de cualquier rutina, la función

esperarConInterrupcion() supervisa entradas del usuario para interrumpir el movimiento y

devolver el sistema a un estado seguro.

En conjunto, este flujo de instrucciones permite un control seguro y organizado de múltiples

ejes, priorizando el diagnóstico en tiempo real, inicialización estructurada y alta escalabilidad.

### 4.5. Diseño 3D de robot bípedo

El diseño tridimensional del robot bípedo B1P0 se desarrolla en Autodesk Fusion 360, con el

objetivo de integrar todos los actuadores, sistemas electrónicos y cableado en una plataforma física

coherente con la arquitectura de control previamente descrita. Este modelo 3D permite visualizar la

disposición de los seis actuadores, la estructura de soporte, los puntos de montaje, piernas y cuerpo,

asegurando que los componentes tengan el espacio y fijación necesarios para su operación.

El robot B1P0 como se ha mencionado anteriormente presenta una arquitectura modular por

niveles, el primer piso o nivel más bajo está apartado para sistemas de potencia y baterías, el nivel del

medio está destinado para dispositivos de control y monitoreo, por último el nivel superior está

reservado para agregar sensores LiDAR, cámaras de profundidad o incluso cargas livianas. Este tipo

de estructuras facilita el mantenimiento y sustitución de componentes.

Cada pierna dispone de tres grados de libertad (6 DoF robot completo) distribuidos en los ejes

de cadera, rodilla y tobillo, permitiendo un rango de movimientos suficiente para las pruebas de

locomoción previstas en esta etapa del desarrollo.

a) b)

Figura 4.14: Modelo 3D de robot B1P0; a) vista frontal, b) vista trasera

La Figura 4.14 muestra diferentes vistas del modelo 3D del robot, destacando modularidad y

la anatomía basada en “tobillos” (visualmente simulan rodillas) hacia atrás optimizando su impulso y

menor gasto energético como se menciona en los estudios de Haberland y Kim [4].

Tal como se establece en los objetivos de esta memoria, se omiten estudios avanzados de

mecánica estructural, análisis de esfuerzos o cálculos de resistencia de materiales. El diseño

presentado corresponde a una configuración funcional orientada a la validación del sistema

electrónico y de control, constituyendo un primer prototipo sobre el cual podrán realizarse iteraciones

posteriores.

### 5. Resultados

### 5.1. Pruebas de torque

A partir de las pruebas experimentales que se realizaron anteriormente al motor Eaglepower,

se logra caracterizar dicho motor sin reductor obteniendo sus parámetros más relevantes. Estos datos

son de suma relevancia para comparar el desempeño del actuador QDD y por supuesto, caracterizarlo

en secciones posteriores.

De la sección 2.2.1 se sabe que el torque eléctrico de un motor de corriente continua está dado

por:
τ = KaΦIa | (5.1)

Para efectos prácticos, es común reemplazar KaΦ por una constante, llamada constante de

torque KT. Como se menciona anteriormente, esta constante se determina en experimentos anteriores,

cuyo valor promedio es

KT_mean ≈ 0.42 [

Nm
A
] | (5.2)

Además, el torque máximo de saturación se determinó que era 1.78 [Nm] a una corriente de

4.17 [A]

Con estos datos en mente, procedemos a armar un setup experimental como se muestra en la

Figura 5.1 para medir el torque aplicado en una balanza digital, teniendo en mente la distancia entre

el eje de giro y el punto de apoyo (220 [mm]).

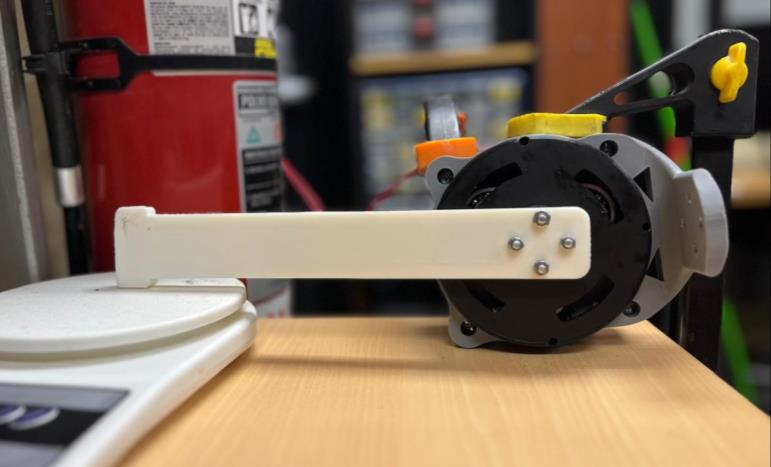
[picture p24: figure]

Figura 5.1: Setup experimental: actuador, balanza digital y brazo de fuerza de 220 [mm]

El objetivo de este experimento es poder obtener el torque máximo de saturación

implementando el reductor planetario, es por esto que se ajusta el controlador de posición del actuador

de tal manera de obtener respuestas agresivas y exigentes, forzándolo a sus límites de corriente.

Después de una serie de pruebas de torque, se obtiene las siguientes muestras en condiciones de

máxima corriente.

Figura 5.2: Resultados experimentales de torque en condiciones de saturación

Se puede ver en la Figuras 5.2, que a pesar de que la corriente tiende a aumentar ligeramente,

la fuerza generada por el actuador a penas logra llegar a los 15.67 [Nm], siendo este valor el torque

máximo medido en las pruebas de manera constante. Cabe destacar que en el momento de medir este

valor máximo de Torque se presentan sonidos agudos en los inductores del motor, aumentando

también su temperatura, lo que indica claramente el momento de saturación y corriente máxima que

soporta el motor, la cual alcanzó los 3.98 [A], muy cercano a la corriente máxima medida en pruebas

con el motor sin reductor (4.17 [A]).

Como observación importante, es posible medir valores de torque mayores al de saturación

mostrado, sin embargo estas mediciones deben ser con una instrumentación mucho más precisa para

poder observar peaks de torque en un instante de tiempo muy acotado.

Con estos datos en mente, se puede ver que el torque final obtenido con el reductor planetario

aumentó alrededor de 8.8 veces en comparación al torque inicial sin reductor, lo cual es

aproximadamente la relación de transmisión de diseño 9:1.

### 5.2. Caracterización final de actuadores

La caracterización comparativa entre el motor base y el actuador QDD desarrollado para el robot

B1P0 evidencia mejoras significativas en parámetros clave. El incremento de la relación de

transmisión a 9:1 permite elevar el torque máximo de 1.78 [Nm] a 15.67 [Nm], manteniendo una

corriente de saturación similar, lo que indica una mayor eficiencia en la conversión de energía eléctrica

en torque útil. La Tabla 5.1 detalla cada comparación.

Tabla 5.1: Caracterización final de actuador QDD propioceptivo

Parámetro | Motor | Actuador QDD Robot B1P0
Masa (g)
Diámetro (mm)
Ancho (mm)
KV (rev/V)
KT (Nm/A)
Relación de Transmisión
Torque máximo de saturación (Nm) Corriente a torque de saturación (A) Potencia máxima (W)
Densidad de torque (Nm/kg) Eficiencia (%)

336
92
28.5
90
0.42
1:1
1.78
4.17
91.74
5.3

750
139
108
10
3.94
9:1
15.67
3.98
87.56
20.9
95%

La densidad de torque pasa de 5.3 [Nm/kg] en el motor base a 20.9 [Nm/kg] en el actuador,

casi cuadruplicando su capacidad relativa y permitiendo un diseño más compacto y potente. La

eficiencia medida del 95% confirma que las pérdidas mecánicas y eléctricas del sistema de transmisión

son mínimas.

En conjunto, estos resultados validan el diseño del actuador como una solución óptima para

aplicaciones de locomoción bípeda, donde se busca un actuador que entregue alto torque sin sacrificar

su velocidad de respuesta y por supuesto, sin sacrificar su peso.

### 5.3. Prototipo final de robot bípedo e integración de actuadores

En esta sección se presentan las imágenes del prototipo final del robot bípedo B1P0, mostrando

la integración física de los actuadores y su disposición en la estructura completa del robot.


Figura 5.3: Piezas 3D impresas y motores previo a ensamblaje

En la Figura 5.3 se muestran las piezas impresas en 3D esenciales para la construcción de cada

actuador y pierna del robot, incluyendo motores.

En la Figura 5.4 se observa el interior de un actuador con y sin carcasa, viendo así el sistema

de reductor planetario que fue propuesto a lo largo de esta memoria, con su respectivo porta planeta

y rodamientos.

a) b)

Figura 5.4: Actuador impreso; a) sin carcasa y salida de pernos, b) con carcasa y salida con polea dentada

Cabe mencionar que se diseñaron 2 tipos de actuadores que, en esencia funcionan de la misma

manera pero el tipo de anclaje final es diferente. El actuador de la Figura 5.4 lado a) posee un eje de

salida con 4 pernos incrustados que sirven como punto de apoyo para unir otros sistemas rígidos.

Por otro lado en la Figura 5.4 lado b) se construyó el mismo actuador pero el porta planeta es

una polea dentada GT2 de 19 [mm] de diámetro. Por esta polea se rodea una correa dentada la cual

permite transmitir el giro desde el actuador hacia una articulación inferior de la pierna. Solamente se

diseñaron dos actuadores de este último modelo ya que solo era necesario dos correas para articular

las dos piernas.


Figura 5.5: Pierna completa de robot B1P0 de 3 grados de libertad

Luego, en la Figura 5.5 se ensamblan los 3 actuadores, pie y muzlo para construir una pierna

completa del robot B1P0 en sus tres ejes de giro. Un detalle no menor es el uso de una esfera como

punto de apoyo en el piso. Se toma esta decisión ya que al no contar con un cuarto actuador en la

planta baja de la pierna, no se puede generar una articulación extra, por lo tanto, se debe optar por un

punto de apoyo rígido en el piso. Sin embargo, para evitar posibles deslizamientos entre el plástico

del pie y el piso, se propone a futuro envolver los dos pies del robot con alguna goma antideslizante.

Figura 5.6: Ensamblaje completo de los 6 actuadores (con drivers) y 2 piernas completes

La integración completa de actuadores, piernas y drivers se muestra en la Figura 5.6, como se

mencionó antes, los únicos actuadores que cuentan con sistema de poleas son los que llevan las

piernas, así poder articularlas.


Figura 5.7: Robot B1P0 completamente armado con subsistemas eléctricos conectados

Finalmente, la integración de todos los sistemas tanto mecánicos, como electrónicos se

implementan en la plataforma robótica B1P0 (Biped Penquista) mostrada en la Figura 5.7. Aquí todos

los actuadores y piernas están unidos a un mismo cuerpo modular separado en niveles. Aunque en la

imagen no se logra apreciar bien, dentro de estos niveles se encuentran los subsistemas de potencia y

control que van conectados a una fuente de poder y a los actuadores. Además, de manera extra se

desarrolló un atril para sostener el robot y realizar pruebas en un entorno más seguro libre de impactos

con el suelo o posibles colisiones.

Aunque uno de los objetivos específicos era solamente el diseño en 3D del robot, con este

primer prototipo funcional no solo se valida dicho diseño, si no que facilita las pruebas posteriores

que se realizarán para validar el sistema de control basado en CAN y Odrive S1.
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

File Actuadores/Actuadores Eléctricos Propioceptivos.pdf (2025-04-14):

DEPARTAMENTO DE INGENIERÍA ELÉCTRICA

FACULTAD DE INGENIERÍA

UNIVERSIDAD DE CONCEPCIÓN

PROYECTO ELECTRÓNICO

### SEMESTRE 2024-2

### Informe final

## Diseño, implementación y caracterización de un actuador eléctrico propioceptivo para uso en robots de alta dinámica

Estudiante(s): | Bastián Nicolás Inostroza Sanzana
Profesor guía: | José Rubén Espinoza Castro


## Fecha de entrega: 5 de diciembre de 2024

# Contenidos

# 1 Introducción

En este último tiempo, el avance de los robots y la inteligencia artificial han sorprendido hasta su público más fanático con grandes innovaciones en temas de programación, hardware, sistemas de control, sensores o lo que se tratará en este documento, sus actuadores eléctricos.

En simples palabras un actuador dentro del entorno robótico ayuda a controlar el movimiento y a crear acciones precisas en los robots. Son básicamente la unión entre distintos enlaces mecánicos para el movimiento, analógicamente a un ser vivo, serían las articulaciones de esté, las que precisamente les dan los grados de libertad.
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

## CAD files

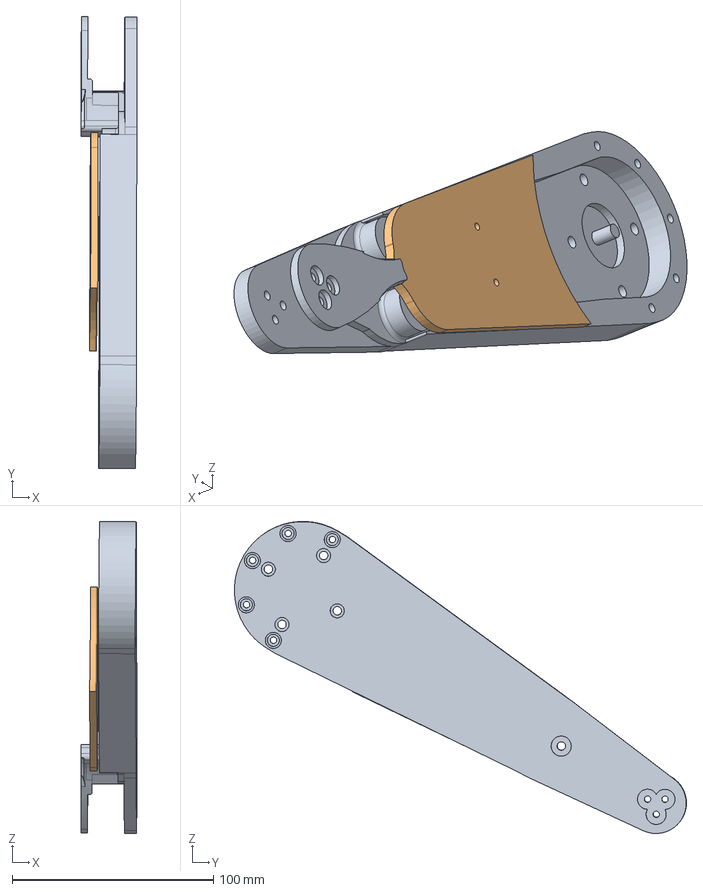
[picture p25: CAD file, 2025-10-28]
Cuerpo/Muzlo.step
27.8 x 224.6 x 155.0 mm
BLDC_Casing
Magnet_Holder FINAL
Encoder_Magnet
75x95x10mm_Bearing
12x28x8mm_Bearing x 3
Stator
Rotar
M4_10mm_Screw
12x28x8mm_Bearing (2)
Anillo_NUEVO
Porta_Planeta
Gear_098 x 3
Planeta_Oficial
Sujetador
Muslo
Componente26
M4_45mm_Screw (1)
Componente32

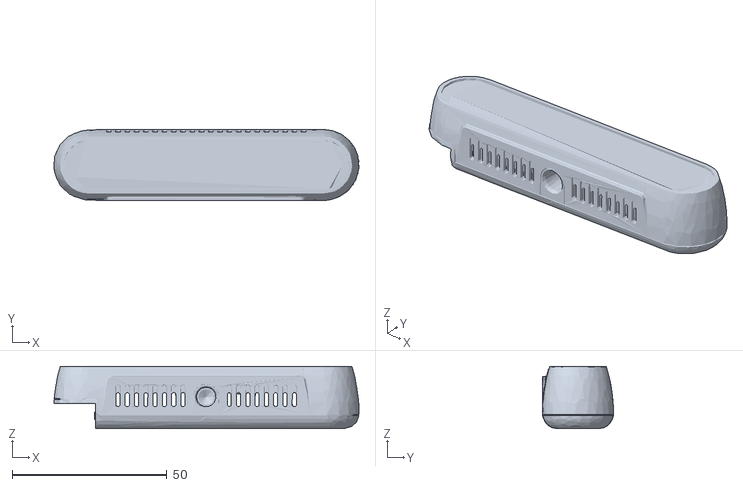
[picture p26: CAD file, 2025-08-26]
Software y Comunicación/Cámara/librealsense/common/res/sources/D415.obj
98.6 x 23.0 x 20.0

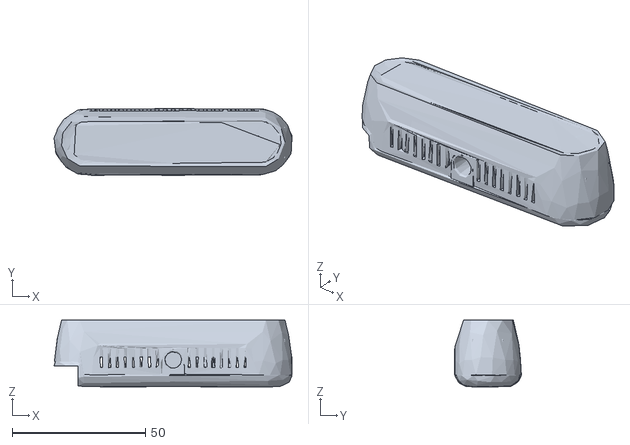
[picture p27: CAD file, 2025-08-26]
Software y Comunicación/Cámara/librealsense/common/res/sources/D435.obj
89.2 x 25.0 x 25.0

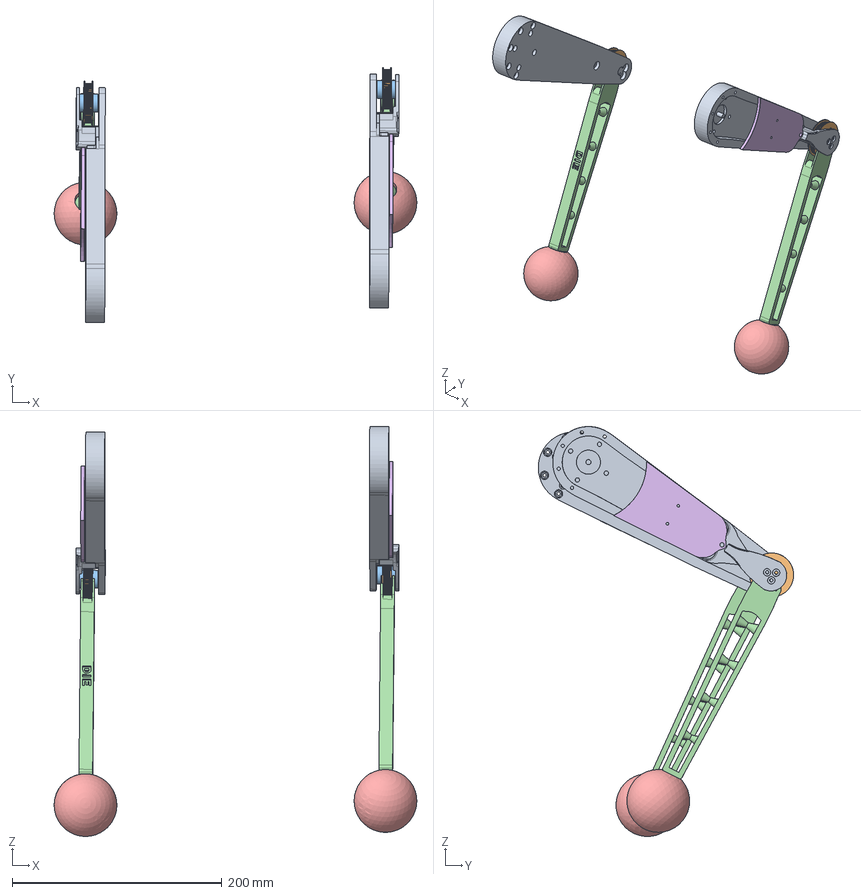
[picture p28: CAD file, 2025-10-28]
Cuerpo/2 piernas.step
346.3 x 243.7 x 391.3 mm
BLDC_Casing x 2
Magnet_Holder FINAL x 2
Encoder_Magnet x 2
75x95x10mm_Bearing x 2
12x28x8mm_Bearing x 6
Stator x 2
Rotar x 2
M4_10mm_Screw x 2
12x28x8mm_Bearing (2) x 2
Anillo_NUEVO x 2
Porta_Planeta x 2
Gear_098 x 6
Planeta_Oficial x 2
Sujetador x 2
Muslo x 2
Componente26 x 2
Rueda x 2
Rodillo x 2
Pata x 2
Pie x 2
M4_45mm_Screw (1) x 2
Componente32 x 2

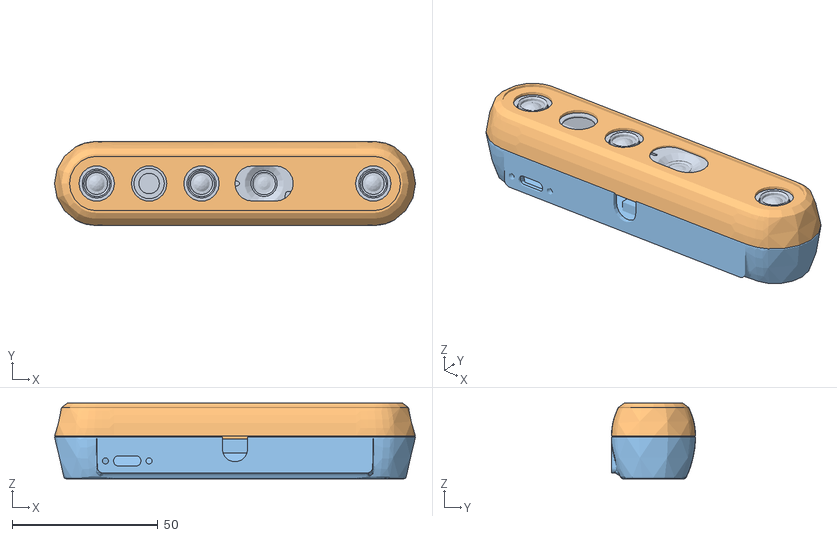
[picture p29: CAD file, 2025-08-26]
Software y Comunicación/Cámara/librealsense/common/res/sources/D455.obj
124.0 x 29.0 x 26.0

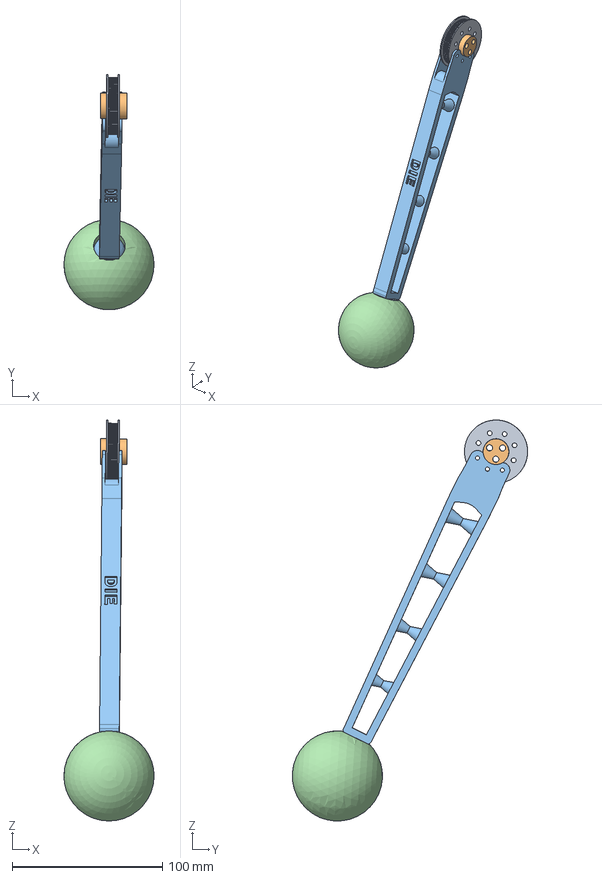
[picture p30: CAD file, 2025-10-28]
Cuerpo/Pantorrilla.step
60.0 x 156.4 x 266.6 mm
BLDC_Casing
Magnet_Holder FINAL
Encoder_Magnet
75x95x10mm_Bearing
12x28x8mm_Bearing x 3
Stator
Rotar
M4_10mm_Screw
12x28x8mm_Bearing (2)
Anillo_NUEVO
Porta_Planeta
Gear_098 x 3
Planeta_Oficial
Sujetador
Componente26
Rueda
Rodillo
Pata
Pie
M4_45mm_Screw (1)

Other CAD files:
Cuerpo/Muzlo 2.step

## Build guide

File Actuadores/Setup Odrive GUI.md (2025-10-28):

## Configuración general de actuadores usando Odrive GUI

### Power Source (Ajustar dependiendo de Batería)


### Motor



### Encoder


### Control Mode


### Interfaces


### Apply and Calibrate
Aplicar todos los cambios, calibrar actuadores y guardar



## Parámetros de controladores

Depende de cada eje!!


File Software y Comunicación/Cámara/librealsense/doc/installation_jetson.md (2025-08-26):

# NVIDIA® Jetson™ Devices

**NOTE**: See [support-matrix.md](./support-matrix.md) to learn more about Jetson support for RealSense devices.

> Check out [www.jetsonhacks.com](http://www.jetsonhacks.com/) for great content on everything Jetson! (not affiliated with Intel RealSense)

## Getting started

### 1. Prerequisites

* NVIDIA® **Jetson Nano™**, **Jetson TX2™**, **Jetson AGX Xavier™** or **Jetson AGX Orin™** board (may also work on other Jetson devices)
* A supported RealSense Camera device

### 2. Establish Developer's Environment

Follow [official instructions](https://developer.nvidia.com/embedded/learn/getting-started-jetson) to get your board ready. This guide will assume you are using **NVIDIA® L4T Ubuntu 18.04/20.04/22.04** image with kernels 4.9/5.10/5.15. Note that in most cases it is necessary to install a toll named "SDK Manager" to flash and install **Jetson** boards with both the L4T (Linux for Tegra) and NVIDIA-specific software packages (CUDA, Tensor Flow, AI, etc.)

For **Jetson Nano™** we strongly recommend enabling the Barrel Jack connector for extra power (See [jetsonhacks.com/jetson-nano-use-more-power/](https://www.jetsonhacks.com/2019/04/10/jetson-nano-use-more-power/) to learn how)

Jetson Nano

### 3. Choose LibRealSense SDK Backend

Librealsense2 SDK supports two API for communication with RealSense device on Linux platforms:

1. Linux native kernel drivers for UVC, USB and HID (Video4Linux and IIO respectively)
2. Using `RSUSB` - user-space implementation of the UVC and HID data protocols, encapsulated and activated by selecting the SDK's `-DFORCE_RSUSB_BACKEND` flag (a.k.a. `-DFORCE_LIBUVC` with SDK versions prior to v.2.30).  

When the second method is selected Librealsense2 communicates with the devices using the standard USB driver, while the higher-level protocols  (UVC/HID) stacks are compiled directly into the SDK.
Currently the two interfaces are mutually-exclusive, thus the choice taken during the SDK configuration stage (CMakes) predefines the selected backend API.

As a general rule it is recommended to use the native kernel drivers, especially in production environment.
The second method augments the native installation and allows for a fully-functional SDK deployment at the expense of certain performance and functional limitations (e.g. multi-cam).
The list of requirements for the second method comprise of a basic USB driver and GCC compiler, thus making it attractive for prototyping and demos in new/previously-unsupported environments.

If that's the case, what is the dilemma?

In order to enable the full capabilities of RealSense devices certain modifications in the kernel (driver) modules shall be applied, such as support of Depth-related streaming formats and access to per-frame metadata attributes. There is a small set of generic kernel changes that are mostly retrofitted with more advanced kernel versions aimed at improving the overall drivers stability.

NVIDIA's L4T delivers an Ubuntu-based distribution with a customized kernel based on version 4.9/5.10. The way the kernel is configured and deployed is different from a desktop Ubuntu image with two notable differences being the list of kernel modules included in default configuration and the way a new image is flashed.

And while it is possible to rebuild and flash a new kernel image the procedure can be perceived as challenging and shall be performed with extra caution.
This guide comes with a script that allows to modify the kernel modules with Librealsense2-related patches without replacing the kernel image. The script has been verified with **Jetson AGX Xavier™** board using L4T versions 5.0.2 and 6.0. Scroll to the end of the guide for details.

### 4. Install with Debian Packages
 The minimum JetPack SDK required to run the precompiled Debians is [JetPack version 5.0.2](https://developer.nvidia.com/jetpack-sdk-441-archive) ( L4T 35.1 , CUDA version 11.4).

Note that a lower version may not work due to non compatible CUDA versions limitation.

<u>Installation steps:</u>

1. Register the server's public key:

    ```sh
    sudo apt-key adv --keyserver keyserver.ubuntu.com --recv-key F6E65AC044F831AC80A06380C8B3A55A6F3EFCDE || sudo apt-key adv --keyserver hkp://keyserver.ubuntu.com:80 --recv-key F6E65AC044F831AC80A06380C8B3A55A6F3EFCDE
    ```

  > In case the public key cannot be retrieved, check and specify proxy settings: `export http_proxy="http://<proxy>:<port>"`, and rerun the command. See additional methods in the following [link](https://unix.stackexchange.com/questions/361213/unable-to-add-gpg-key-with-apt-key-behind-a-proxy).  

2. Add the server to the list of repositories:

    ```sh
    sudo add-apt-repository "deb https://librealsense.intel.com/Debian/apt-repo $(lsb_release -cs) main" -u
    ```

3. Install the SDK:

    ```sh
    sudo apt-get install librealsense2-utils
    sudo apt-get install librealsense2-dev
    ```

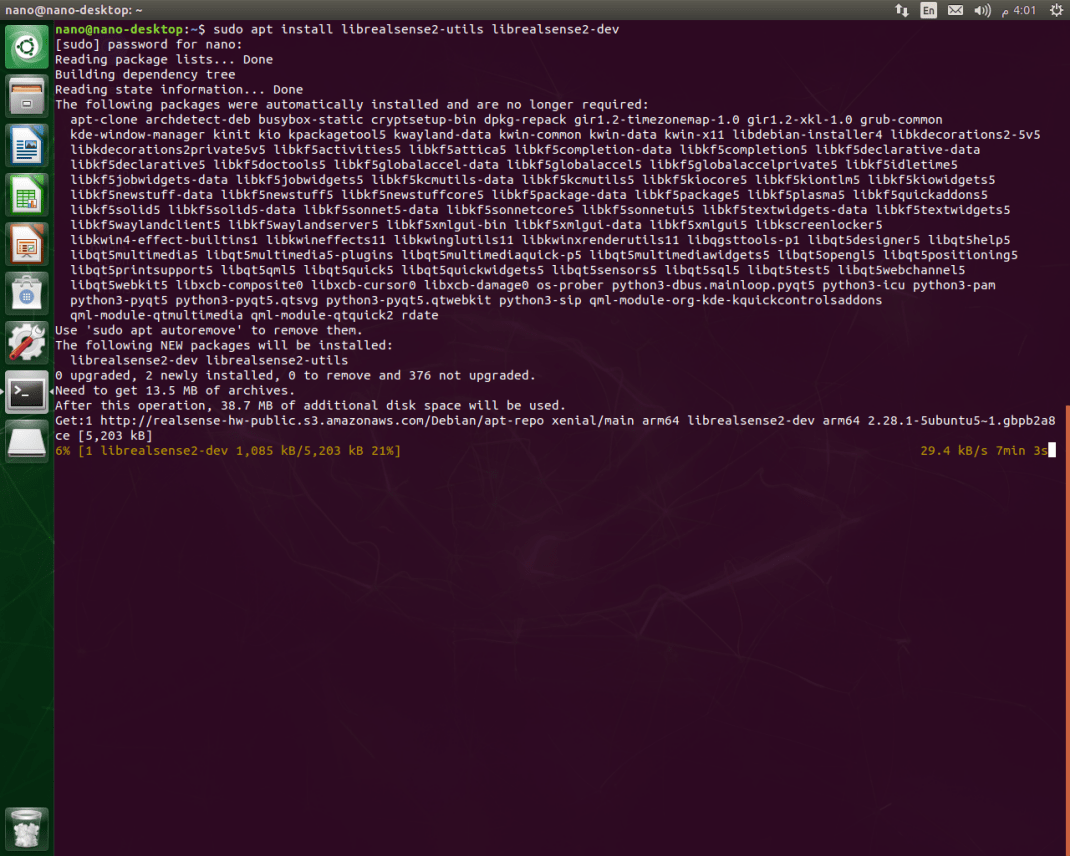
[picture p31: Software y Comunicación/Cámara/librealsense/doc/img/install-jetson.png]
installation
    

    With `librealsense2-dev` package installed, you can compile an application with **librealsense** using `g++ -std=c++11 filename.cpp -lrealsense2` or an IDE of your choice. To get started with RealSense using **CMake** check out [librealsense/examples/cmake](https://github.com/IntelRealSense/librealsense/tree/master/examples/cmake)

4. Reconnect the RealSense device and run the following to verify the installation: `realsense-viewer`

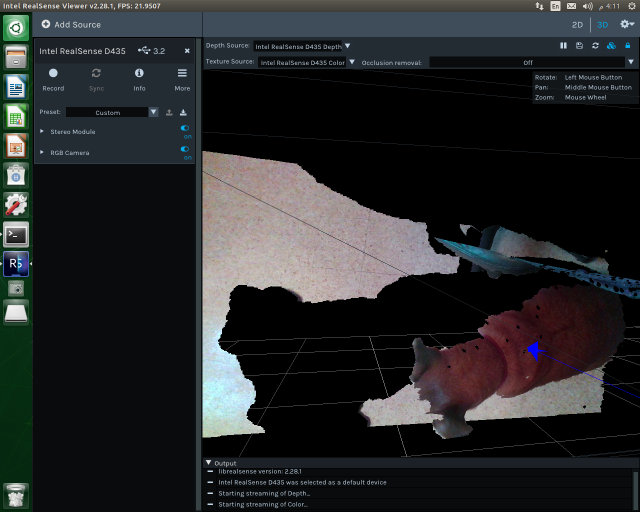
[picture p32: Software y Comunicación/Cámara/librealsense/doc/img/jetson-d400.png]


You can also double-TAB after typing `rs-` to see the full list of SDK examples.

## Building from Source using **RSUSB** Backend

⮕ Use the RSUSB backend without the kernel patching

* In order to build the SDK using the `RSUSB` method and avoid the kernel patching procedure, please refer to [libuvc_installation.sh](https://github.com/IntelRealSense/librealsense/blob/master/scripts/libuvc_installation.sh) script for details. If you have CUDA dev-kit installed, don't forget to add `-DBUILD_WITH_CUDA=true` for optimal performance.

## Building from Source using **Native** Backend

⮕ Use the V4L Native backend by applying the kernel patching

The method was verified with **Jetson AGX Orin™** with JetPack 6.0, **Jetson AGX Xavier™** boards with JetPack **5.0.2**[L4T 35.1.0].

For **Jetson Nano™** setup, please see the following user instructions [NVIDIA Jetson Nano with Intel RealSense Depth Camera Using ROS2 Humble | by Kabilankb | May, 2024 | Medium](https://medium.com/@kabilankb2003/nvidia-jetson-nano-with-intel-realsense-depth-camera-using-ros2-humble-c5926566a4d8)

* **Prerequisite**

  * Verify the board type and Jetpack versions compatibility.  
  * Verify internet connection.  
  * Verify the available space on flash, the patching process requires **~2.5Gb** free space  
    
    >df -h
  * Configure the Jetson Board into Max power mode (desktop -> see the upper right corner)  
  * Disconnect attached USB/UVC cameras (if any).  

* **Build and Patch Kernel Modules for Jetson L4T**

  * Navigate to the root of librealsense2 directory.  
  * Run the script (note the ending characters - `L4T`)

    ```sh
    ./scripts/patch-realsense-ubuntu-L4T.sh  
    ```

  * The script will run for about 30 minutes depending on internet speed and perform the following tasks:

    a. Fetch the kernel source trees required to build the kernel and its modules.  
    b. Apply Librealsense-specific kernel patches and build the modified kernel modules.  
    c. Try to insert the modules into the kernel.

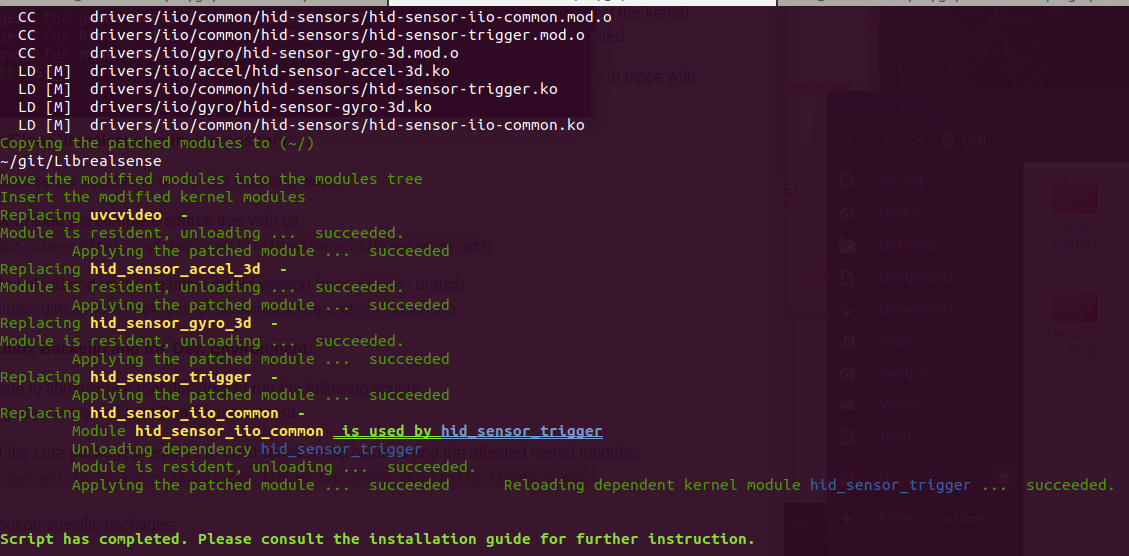
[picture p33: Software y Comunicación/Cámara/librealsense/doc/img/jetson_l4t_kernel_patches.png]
    

* **Build librealsense2 SDK**  
  
  * Navigate to the SDK's root directory.  
  * Follow the [Ubuntu installation guide](./installation.md) to install the missing components and configuration items:

    ```sh
    sudo apt-get install git libssl-dev libusb-1.0-0-dev libudev-dev pkg-config libgtk-3-dev -y
    ./scripts/setup_udev_rules.sh  
    mkdir build && cd build  
    cmake .. -DBUILD_EXAMPLES=true -DCMAKE_BUILD_TYPE=release -DFORCE_RSUSB_BACKEND=false -DBUILD_WITH_CUDA=true && make -j$(($(nproc)-1)) && sudo make install
    ```

  The CMAKE `-DBUILD_WITH_CUDA=true` flag assumes CUDA modules are installed. If not, please reconnect the board to the Ubuntu Host PC and use NVIDIA `SDK Manager` tool to install the missing components.

* **Connect Realsense Device, run `realsense-viewer` and inspect the results**

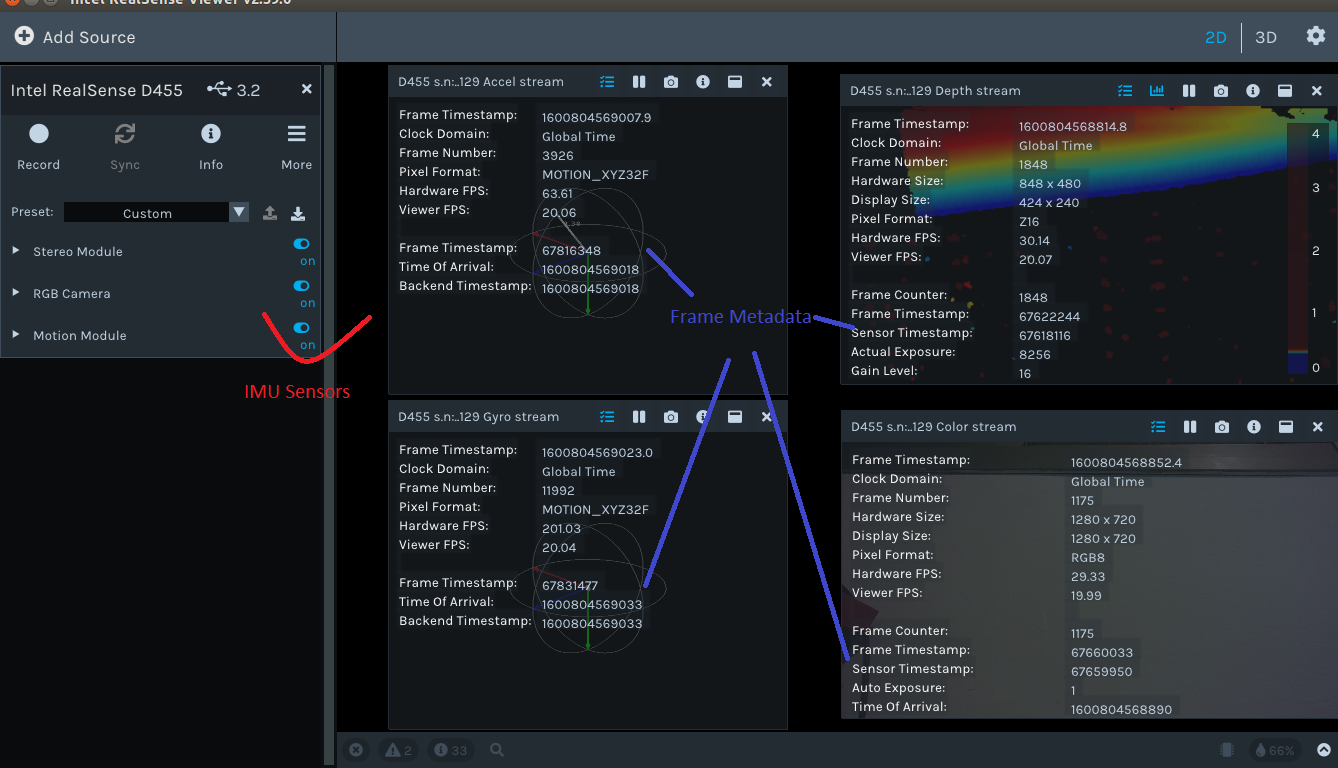
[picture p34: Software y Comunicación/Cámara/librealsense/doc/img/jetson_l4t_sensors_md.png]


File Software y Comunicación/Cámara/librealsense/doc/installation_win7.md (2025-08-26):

# Windows 7 Installation

> **Note:** Intel RealSense products are being regularly validated and receive official support for Windows 10 and Linux eco-systems. Not all product features are enabled on Windows 7. 

> We are constantly expanding the list of supported platforms, devices and features based on customer and community feedback. If your use case is not yet covered, please open [a new issue](https://github.com/IntelRealSense/librealsense/issues/new)

## Getting Started

1. Download [Intel RealSense SDK Installer for Windows 7](https://github.com/IntelRealSense/librealsense/releases/download/v2.16.1/Intel.RealSense.SDK.Win7.exe)
2. Connect the camera (the device must be connected to install the driver)
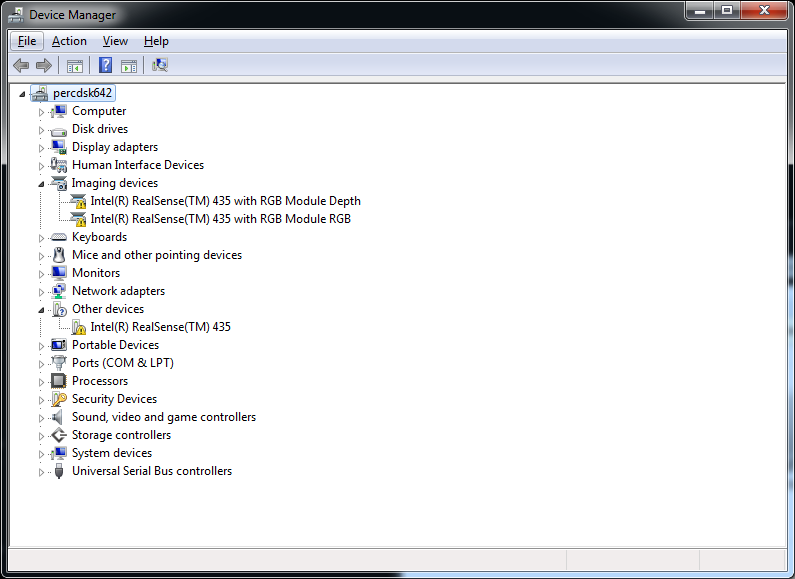
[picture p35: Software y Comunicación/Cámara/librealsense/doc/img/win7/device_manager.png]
dev_man
3. Check the device manager:<br /><br />
> Out of the box Windows 7 will not recognize the D4xx cameras using the inbox driver. 
4. Run the installer and make sure to check **Win7 Drivers**:<br/>
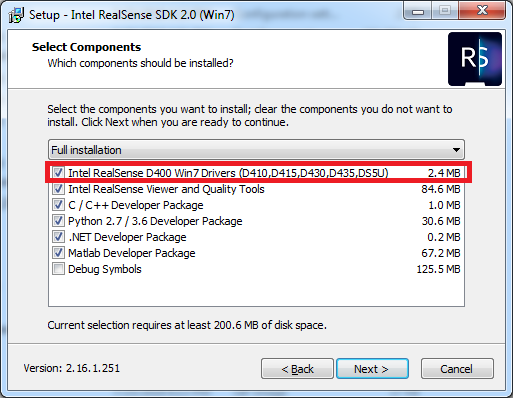
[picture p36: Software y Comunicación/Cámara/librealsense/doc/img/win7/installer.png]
install

5. The installer will prompt to install the driver. This is a one-time step:<br/>
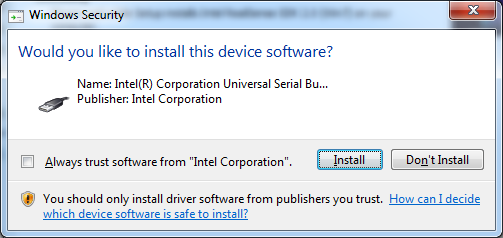
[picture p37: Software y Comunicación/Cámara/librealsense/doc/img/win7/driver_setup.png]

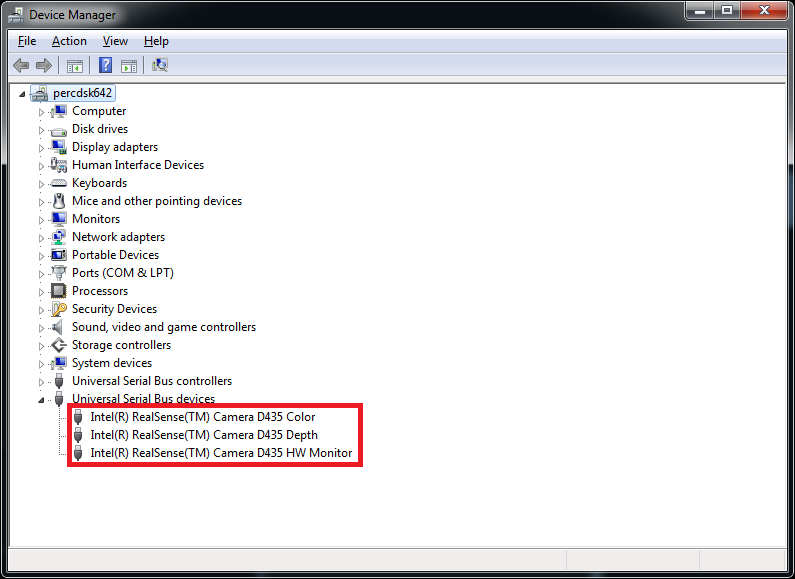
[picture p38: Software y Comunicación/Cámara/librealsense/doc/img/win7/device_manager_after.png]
after


## Supported Devices:
1. Intel(R) RealSense(TM) D410 Module
2. Intel(R) RealSense(TM) D415 Camera
3. Intel(R) RealSense(TM) D430 Module
4. Intel(R) RealSense(TM) D435 Camera

## Known Limitations:
1. Multiple cameras are likely not to work at the moment (not validated)

## Building from Source
The binaries supporting Win7 differ from ones supporting Win10. When building on Win7, CMake will automatically generate binaries for Win7. 
You can also build for Win7 from Win10 by adding `-DFORCE_WINUSB_UVC=true` to CMake flags.
Signed drivers are still required when building from source (can be extracted from the Win7 installer and freely redistributed)

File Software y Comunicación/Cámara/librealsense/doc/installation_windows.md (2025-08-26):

# Windows 10 & Windows 11 Installation

**Note:** Due to the USB 3.0 translation layer between native hardware and virtual machine, the librealsense team does not recommend or support installation in a VM.

librealsense shall be built on Windows using [CMake v3.8+](https://cmake.org/download/) and Visual Studio 2017 / 2019 / 2022: 
(MSVC2015 and older are not fully compatible with the C++14 feature-set).

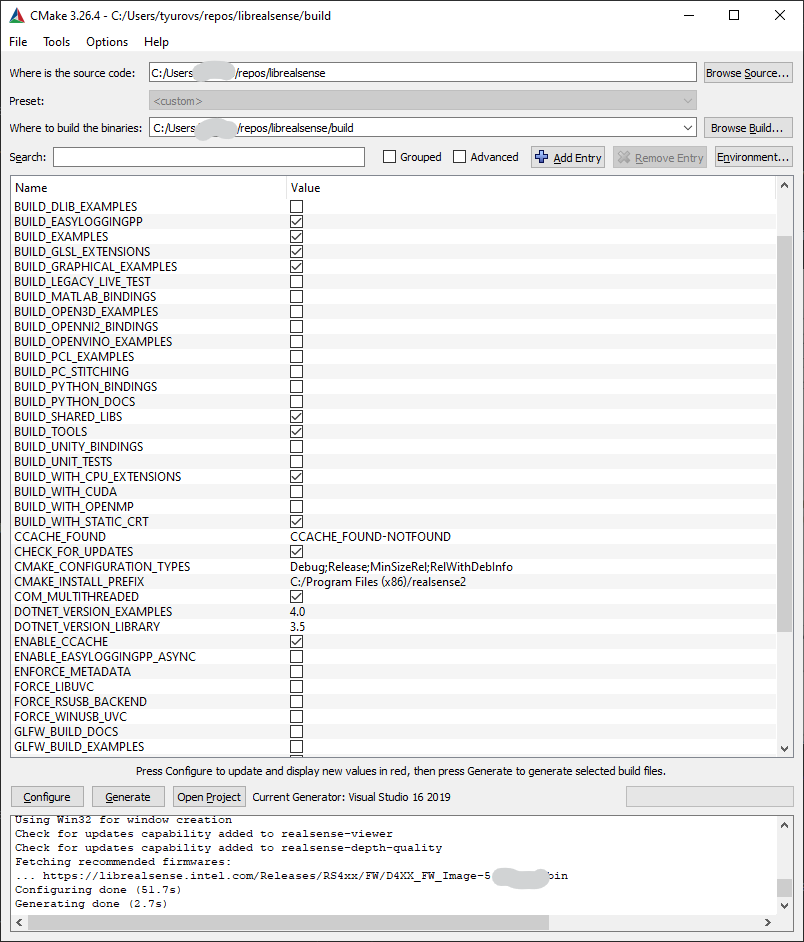
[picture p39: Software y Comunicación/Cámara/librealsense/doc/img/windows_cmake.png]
Windows CMake


Don't forget to check `BUILD_EXAMPLES` if you wish to use librealsense samples.

## Enabling metadata on Windows
Metadata attributes is an advanced capability provided by librealsense.
Read more on this feature in [link](./frame_metadata.md). 
Follow the instructions to enable metadata generation: 

Prerequisites:
- Windows 10 with administrator login.
- WinSDK ver 10 (10.0.15063) or later.

#### Installation:
- Verify OS version:
 - Run `winver` command from desktop/terminal - "Windows 10 (Build 15063 or later, 17763+ recommended) or Windows 11" is expected.

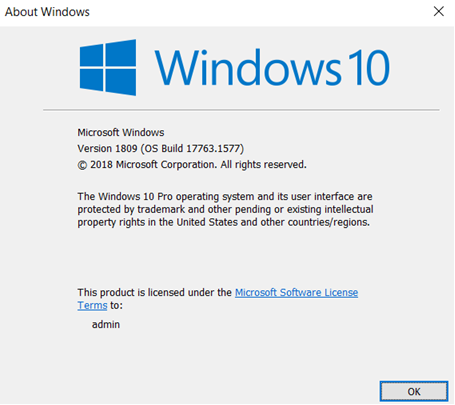
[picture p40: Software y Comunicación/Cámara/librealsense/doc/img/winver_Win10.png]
winver
 

- Install WinSDK ver10:
 - Navigate to "Control Panel" -> "Programs and Features"
 - Double-click on "Microsoft Visual Studio" and select "Modify"
 - Check that SDK version 10.0.10586 or later is present, install if needed:

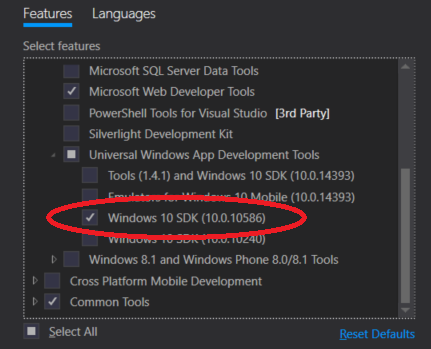
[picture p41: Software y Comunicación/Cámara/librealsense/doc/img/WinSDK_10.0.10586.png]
winsdk
 - 

 ##### Update Registry:
  - Windows OS requires a dedicated registry entry to be present for each unique video device in order to provide metadata. 

  ###### Use automation script:
  - Launch Windows `Powershell` tool as *_Admin_* and navigate to the script directory
  - Run the following: 
    `PS > .\realsense_metadata_win10.ps1 <optional:operation>` 
    The supported parameters are
    - `-op install` adds registry keys for connected Intel Realsense devices
    - `-op install_all` adds keys for all RealSense devices logged in the registry
    - `-op remove` removes registry keys for connected Intel Realsense devices
    - `-op remove_all` removes the keys for all RealSense devices logged in the registry
    Running the script without arguments will is similar to `-op install` operation. 

  -  If you receive `... cannot be
loaded because running scripts is disabled on this system` message, run:

    `PS > Set-ExecutionPolicy RemoteSigned` , answer `Y` and then rerun the script

    **Important** - The registry keys are device-unique. Therefore, __*the script must be executed each time a new RealSense device is attached*__ to the PC.

  ###### Modifying the registry manually
  In case the script cannot be executed due to permissions, or other Host-related issue please follow the instructions to  update the registry manually:
  - Connect Intel® RealSense™ device to the host
  - Navigate to "Control Panel" -> "Device Manager"
  - Browse for Intel® RealSense™ devices
  - Select the first device from the list, e.g. `Intel® RealSense™ Camera D415 Depth` (Step 1)
  - Find device's path (Step 2) and the additional interfaces (Step 3)

    win_dev_master_interface
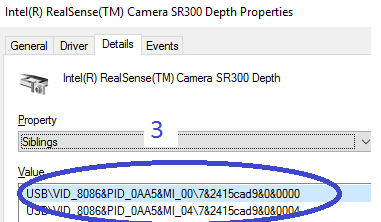
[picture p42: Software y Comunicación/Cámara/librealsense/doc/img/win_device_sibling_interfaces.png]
win_dev_master_interface
    

- Modifying the Windows Registry:
  - For each interface found (Steps 2 and 3) perform
    - Using Registry Editing tool such as "regedit" navigate to `HKLM\SYSTEM\CurrentControlSet\Control\DeviceClasses\{e5323777-f976-4f5b-9b55-b94699c46e44}` branch.
    - Browse into the subdirectory with the name identical to the `Device instance path` obtained from the previous step
      - Expand the entry into `#GLOBAL` -> `Device Parameters`
      - Add `DWORD 32bit` value named `MetadataBufferSizeInKB0` with value 5.
      - Add an additional `DWORD 32bit` value named `MetadataBufferSizeInKB1` with value 5 for RS400 device zero interface `##?##USB#VID_8086&PID... **MI_00**..`
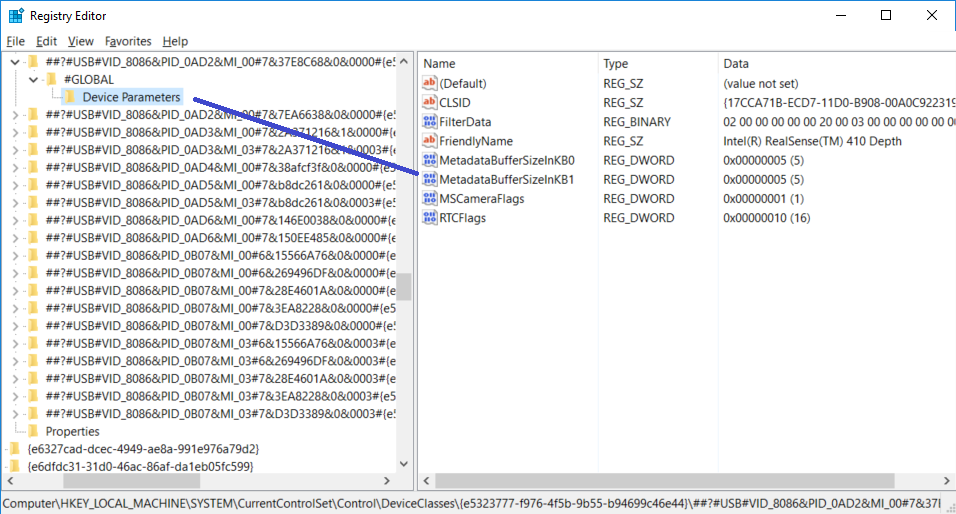
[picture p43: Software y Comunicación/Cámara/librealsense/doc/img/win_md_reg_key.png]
win_md_reg_key
       

    - Repeat the previous step for
      `HKLM\SYSTEM\CurrentControlSet\Control\DeviceClasses\{65E8773D-8F56-11D0-A3B9-00A0C9223196}` branch
- Repeat the procedure for all the additional RealSense devices (e.g. `Intel® RealSense™ Camera D415 RGB`)

#### Compiling Librealsense with Metadata support:
During compilation the library will automatically detect and enable/disable metadata functionality according to the WinSDK version selected.
In case the installed WinSDK doesn't expose metadata the user will be notified that the build does not include metadata generation: 
`Librealsense notification: Featuring UVC Metadata requires WinSDK 10.0.10586.0 toolset.  
The library will be compiled without the metadata support!`

In order to ensure compilation with metadata support check the  `ENFORCE_METADATA` in the [Cmake configuration stage](#cmake_snapshot_win).
When set, the compiler will check the target WinSDK version, and abort the build if it is not compatible with metadata requirements.

**Note** In case of multiple WinSDK version installed, CMake automatically selects the latest version of SDK. In some cases, however, the automatic selection may fail. Then you need to manually retarget the solution for the proper WinSDK version: 
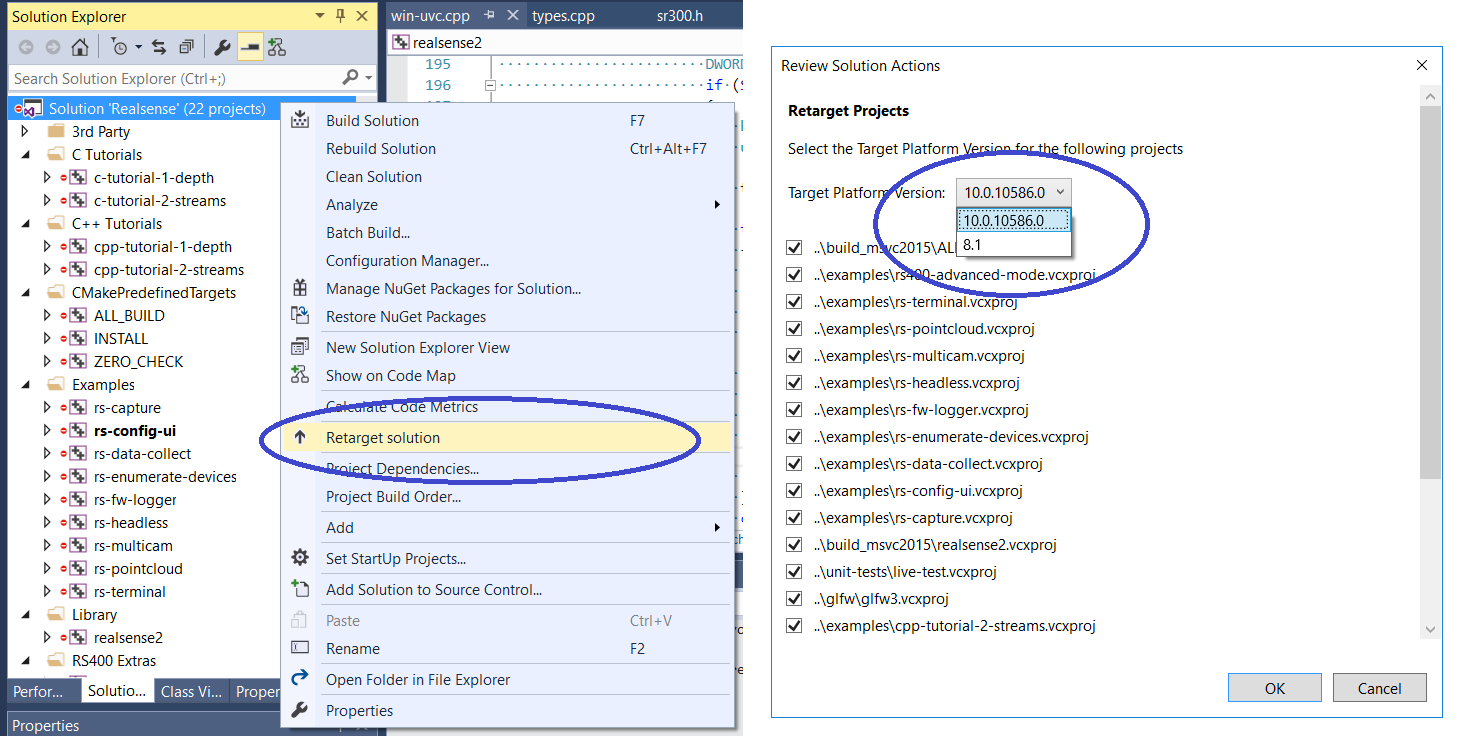
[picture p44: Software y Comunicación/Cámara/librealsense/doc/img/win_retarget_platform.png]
win_retarget_platform


## Troubleshooting Issues

| Error | Cause | Correction Steps |
|---|---|---|
| The camera is not recognized by the SDK | The SDK does not have access to the camera | Make sure that "Allow desktop apps to access your camera" setting is set to on in Windows OS (Setting -> Privacy -> Camera) |

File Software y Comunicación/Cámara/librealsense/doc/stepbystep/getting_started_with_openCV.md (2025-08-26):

# Getting Started with OpenCV

## Displaying Color Frame

In this demo, you will acquire color frame from the RealSense camera and display it using OpenCV.
Before you start, make sure you have librealsense and OpenCV installed and working properly on your system.
Using the editor of your choice create BGR_sample.cpp and copy-paste the following code-snippet:

```cpp
// include the librealsense C++ header file
#include <librealsense2/rs.hpp>

// include OpenCV header file
#include <opencv2/opencv.hpp>

using namespace std;
using namespace cv;

int main()
{
    //Contruct a pipeline which abstracts the device
    rs2::pipeline pipe;

    //Create a configuration for configuring the pipeline with a non default profile
    rs2::config cfg;

    //Add desired streams to configuration
    cfg.enable_stream(RS2_STREAM_COLOR, 640, 480, RS2_FORMAT_BGR8, 30);

    //Instruct pipeline to start streaming with the requested configuration
    pipe.start(cfg);

    // Camera warmup - dropping several first frames to let auto-exposure stabilize
    rs2::frameset frames;
    for(int i = 0; i < 30; i++)
    {
        //Wait for all configured streams to produce a frame
        frames = pipe.wait_for_frames();
    }

    //Get each frame
    rs2::frame color_frame = frames.get_color_frame();

    // Creating OpenCV Matrix from a color image
    Mat color(Size(640, 480), CV_8UC3, (void*)color_frame.get_data(), Mat::AUTO_STEP);

    // Display in a GUI
    namedWindow("Display Image", WINDOW_AUTOSIZE );
    imshow("Display Image", color);

    waitKey(0);

    return 0;
}
```

Compile and run the application from terminal using the following command line:

```shell
g++ -std=c++11 BGR_sample.cpp -lrealsense2 -lopencv_core -lopencv_highgui -o BGR && ./BGR
```

**Result:**

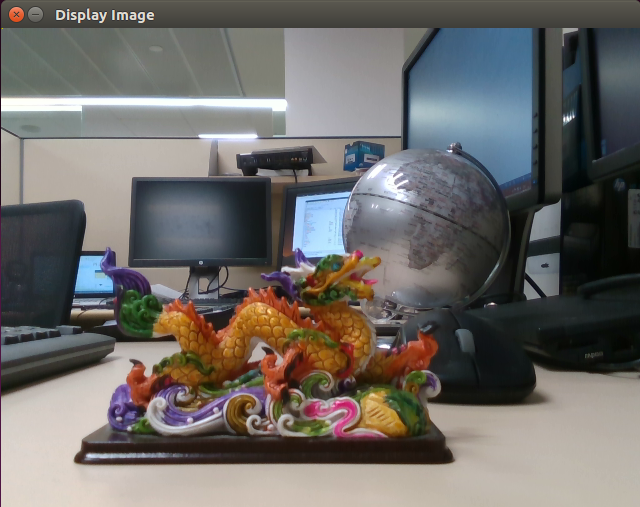
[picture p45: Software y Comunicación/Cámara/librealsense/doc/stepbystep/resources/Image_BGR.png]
BGR_Image


## Displaying Infrared Frame

Displaying Infrared and Depth data is not very different from Color data. Infrared frame is a single channel, 8 bits-per-pixel image.
Copy the following code snippet into IR_sample.cpp:

```cpp
// include the librealsense C++ header file
#include <librealsense2/rs.hpp>

// include OpenCV header file
#include <opencv2/opencv.hpp>

using namespace std;
using namespace cv;

int main()
{
    //Contruct a pipeline which abstracts the device
    rs2::pipeline pipe;

    //Create a configuration for configuring the pipeline with a non default profile
    rs2::config cfg;

    //Add desired streams to configuration
    cfg.enable_stream(RS2_STREAM_INFRARED, 640, 480, RS2_FORMAT_Y8, 30);
    cfg.enable_stream(RS2_STREAM_DEPTH, 640, 480, RS2_FORMAT_Z16, 30);

    //Instruct pipeline to start streaming with the requested configuration
    pipe.start(cfg);

    // Camera warmup - dropping several first frames to let auto-exposure stabilize
    rs2::frameset frames;
    for(int i = 0; i < 30; i++)
    {
        //Wait for all configured streams to produce a frame
        frames = pipe.wait_for_frames();
    }

    //Get each frame
    rs2::frame ir_frame = frames.first(RS2_STREAM_INFRARED);
    rs2::frame depth_frame = frames.get_depth_frame();

    // Creating OpenCV matrix from IR image
    Mat ir(Size(640, 480), CV_8UC1, (void*)ir_frame.get_data(), Mat::AUTO_STEP);

    // Apply Histogram Equalization
    equalizeHist( ir, ir );
    applyColorMap(ir, ir, COLORMAP_JET);

    // Display the image in GUI
    namedWindow("Display Image", WINDOW_AUTOSIZE );
    imshow("Display Image", ir);

    waitKey(0);

    return 0;
}
```

Compile and run the program from the terminal, with the following command:

```shell
g++ -std=c++11 IR_sample.cpp -lrealsense2 -lopencv_core -lopencv_imgproc -lopencv_highgui -o ir && ./ir
```

**Result :**

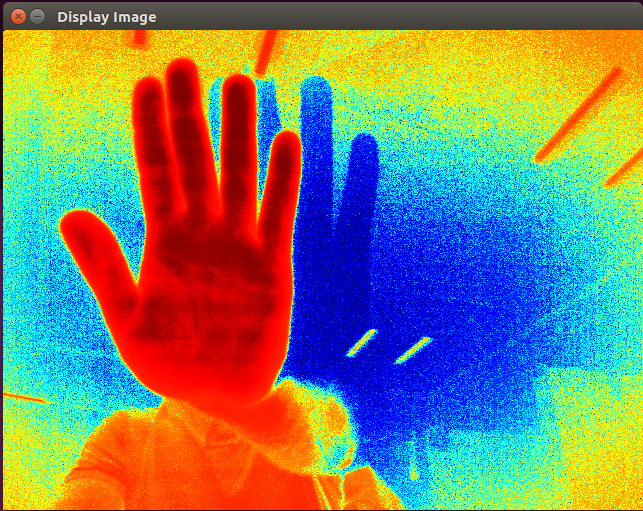
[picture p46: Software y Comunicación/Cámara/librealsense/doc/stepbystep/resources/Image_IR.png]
IR_Image2


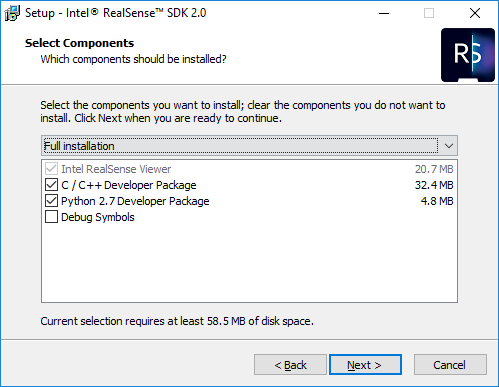
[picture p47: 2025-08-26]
Software y Comunicación/Cámara/librealsense/doc/img/win_step2.PNG

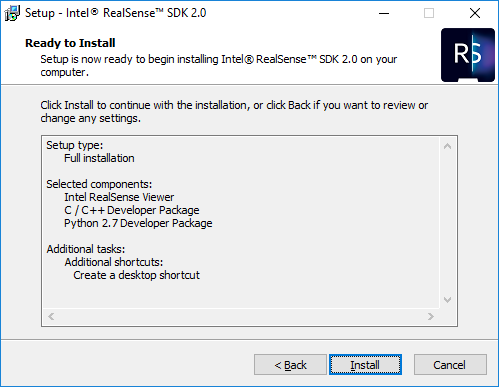
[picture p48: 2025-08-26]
Software y Comunicación/Cámara/librealsense/doc/img/win_step4.PNG

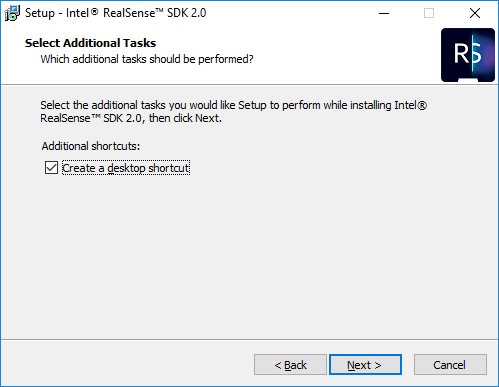
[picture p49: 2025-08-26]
Software y Comunicación/Cámara/librealsense/doc/img/win_step3.PNG

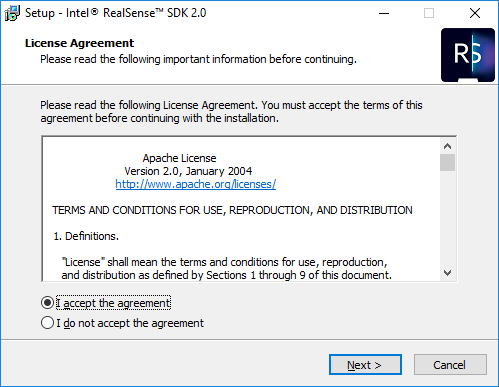
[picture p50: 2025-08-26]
Software y Comunicación/Cámara/librealsense/doc/img/win_step1.PNG

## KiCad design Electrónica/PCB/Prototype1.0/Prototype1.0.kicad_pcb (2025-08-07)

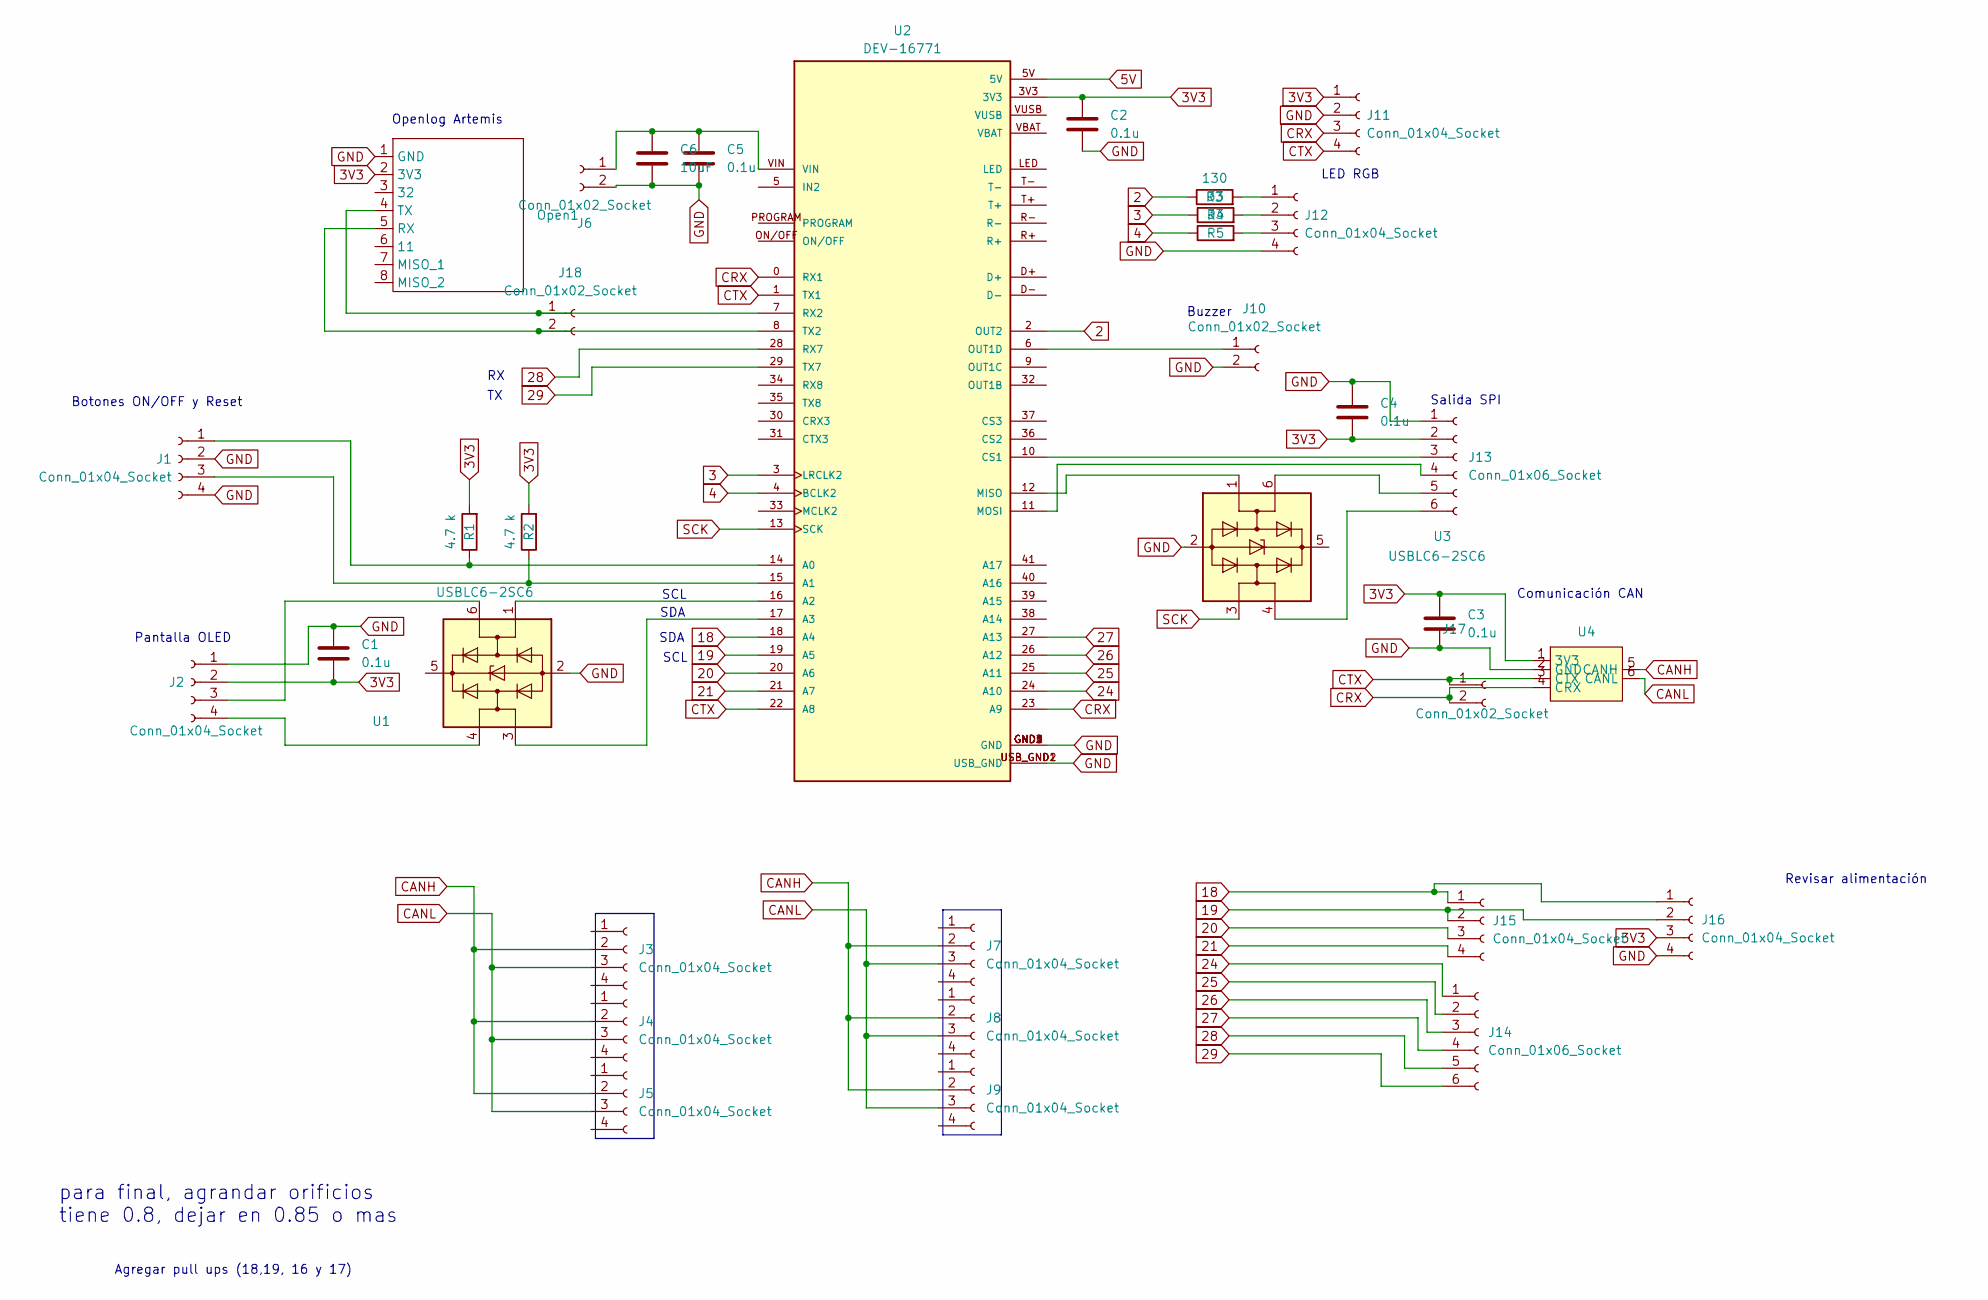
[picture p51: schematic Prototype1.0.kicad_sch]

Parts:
C1, C2, C3, C4, C5: 0.1u; C_0805_2012Metric_Pad1.18x1.45mm_HandSolder
C6: 10uF; C_0805_2012Metric_Pad1.18x1.45mm_HandSolder
J1, J2, J11, J12, J15, J16: Conn_01x04_Socket; PinSocket_1x04_P2.54mm_Vertical
J3, J4, J5, J7, J8, J9: Conn_01x04_Socket; JST_GH_SM04B-GHS-TB_1x04-1MP_P1.25mm_Horizontal
J6: Conn_01x02_Socket; TerminalBlock_Phoenix_MKDS-1,5-2-5.08_1x02_P5.08mm_Horizont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
J10, J17, J18: Conn_01x02_Socket; PinSocket_1x02_P2.54mm_Vertical
J13, J14: Conn_01x06_Socket; PinSocket_1x06_P2.54mm_Vertical
Open1: Openlog Artemis
R1, R2: 4.7 k; R_0805_2012Metric_Pad1.20x1.40mm_HandSolder
R3: 130; R_0805_2012Metric_Pad1.20x1.40mm_HandSolder
R4, R5: 33; R_0805_2012Metric_Pad1.20x1.40mm_HandSolder
U1, U3: USBLC6-2SC6; SOT-23-6
U2: DEV-16771; MODULE_DEV-16771; PARTREV 4.1
U4: ModuloCan

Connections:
2: R3.1, U2.2 (OUT2)
3: R4.1, U2.3 (LRCLK2)
3V3: C1.2, C2.1, C3.1, C4.2, J2.2, J11.1, J13.2, J16.3, Open1.2 (3V3), R1.2, R2.2, U2.3V3, U4.1 (3V3)
4: R5.1, U2.4 (BCLK2)
5V: U2.5V
18: J15.1, J16.1, U2.18 (A4)
19: J15.2, J16.2, U2.19 (A5)
20: J15.3, U2.20 (A6)
21: J15.4, U2.21 (A7)
24: J14.1, U2.24 (A10)
25: J14.2, U2.25 (A11)
26: J14.3, U2.26 (A12)
27: J14.4, U2.27 (A13)
28: J14.5, U2.28 (RX7)
29: J14.6, U2.29 (TX7)
CANH: J3.2, J4.2, J5.2, J7.2, J8.2, J9.2, U4.5 (CANH)
CANL: J3.3, J4.3, J5.3, J7.3, J8.3, J9.3, U4.6 (CANL)
CRX: J11.3, J17.2, U2.0 (RX1), U2.23 (A9), U4.4 (CRX)
CTX: J11.4, J17.1, U2.1 (TX1), U2.22 (A8), U4.3 (CTX)
GND: C1.1, C2.2, C3.2, C4.1, C5.2, C6.2, J1.2, J1.4, J2.1, J6.2, J10.2, J11.2, J12.4, J13.1, J16.4, Open1.1 (GND), U1.2 (GND), U2.GND1 (GND), U2.GND2 (GND), U2.GND3 (GND), U2.GND4 (GND), U2.GND5 (GND), U2.USB_GND1 (USB_GND), U2.USB_GND2 (USB_GND), U3.2 (GND), U4.2 (GND)
unnamed: J1.1, R1.1, U2.14 (A0)
unnamed: J1.3, R2.1, U2.15 (A1)
unnamed: J2.3, U1.6 (I/O1)
unnamed: J2.4, U1.4 (I/O2)
unnamed: C5.1, C6.1, J6.1, U2.VIN
unnamed: J10.1, U2.6 (OUT1D)
unnamed: J12.1, R3.2
unnamed: J12.2, R4.2
unnamed: J12.3, R5.2
unnamed: J13.3, U2.10 (CS1)
unnamed: J13.4, U2.11 (MOSI)
unnamed: J13.5, U3.6 (I/O1)
unnamed: J13.6, U3.4 (I/O2)
unnamed: J18.1, Open1.4 (TX), U2.7 (RX2)
unnamed: J18.2, Open1.5 (RX), U2.8 (TX2)
unnamed: U1.1 (I/O1), U2.16 (A2)
unnamed: U1.3 (I/O2), U2.17 (A3)
unnamed: U2.12 (MISO), U3.1 (I/O1)
SCK: U2.13 (SCK), U3.3 (I/O2)

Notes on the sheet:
Botones ON/OFF y Reset
SDA
Agregar pull ups (18,19, 16 y 17)
SCL
Buzzer
Comunicación CAN
Salida SPI
Revisar alimentación
LED RGB
para final, agrandar orificios tiene 0.8, dejar en 0.85 o mas
Openlog Artemis
Pantalla OLED

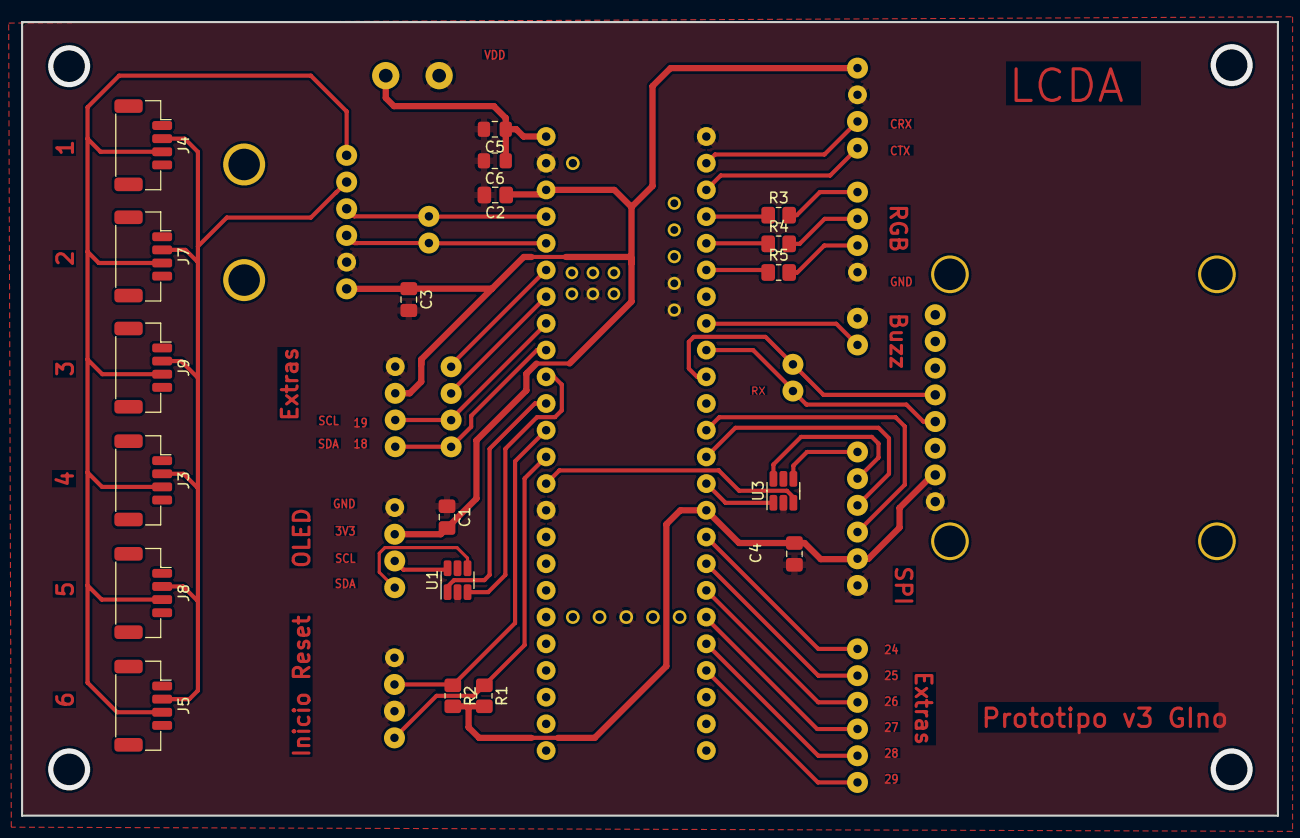
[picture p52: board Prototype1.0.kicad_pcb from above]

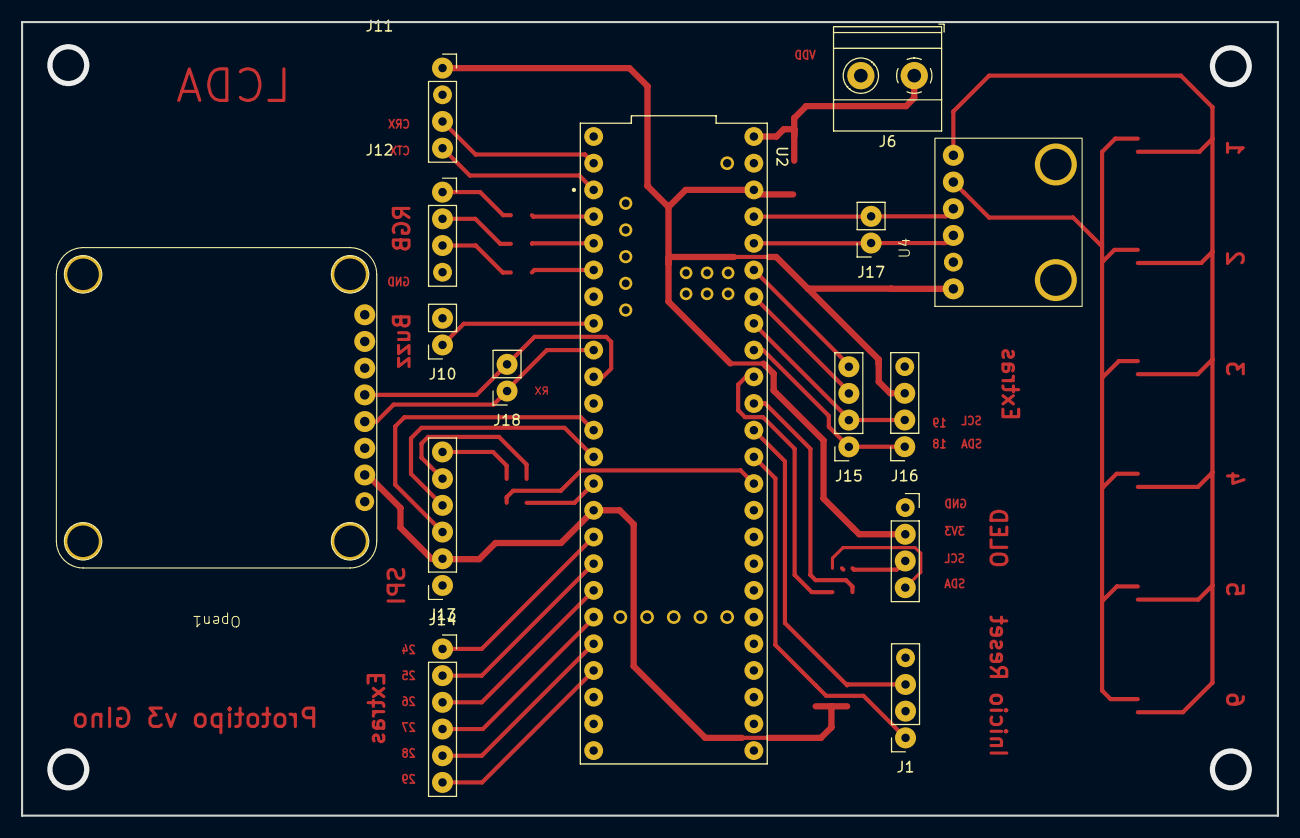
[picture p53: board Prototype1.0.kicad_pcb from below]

Board: 2 copper layers, 119.5 x 75.5 mm, 34 parts (15 on the bottom side), 38 nets.

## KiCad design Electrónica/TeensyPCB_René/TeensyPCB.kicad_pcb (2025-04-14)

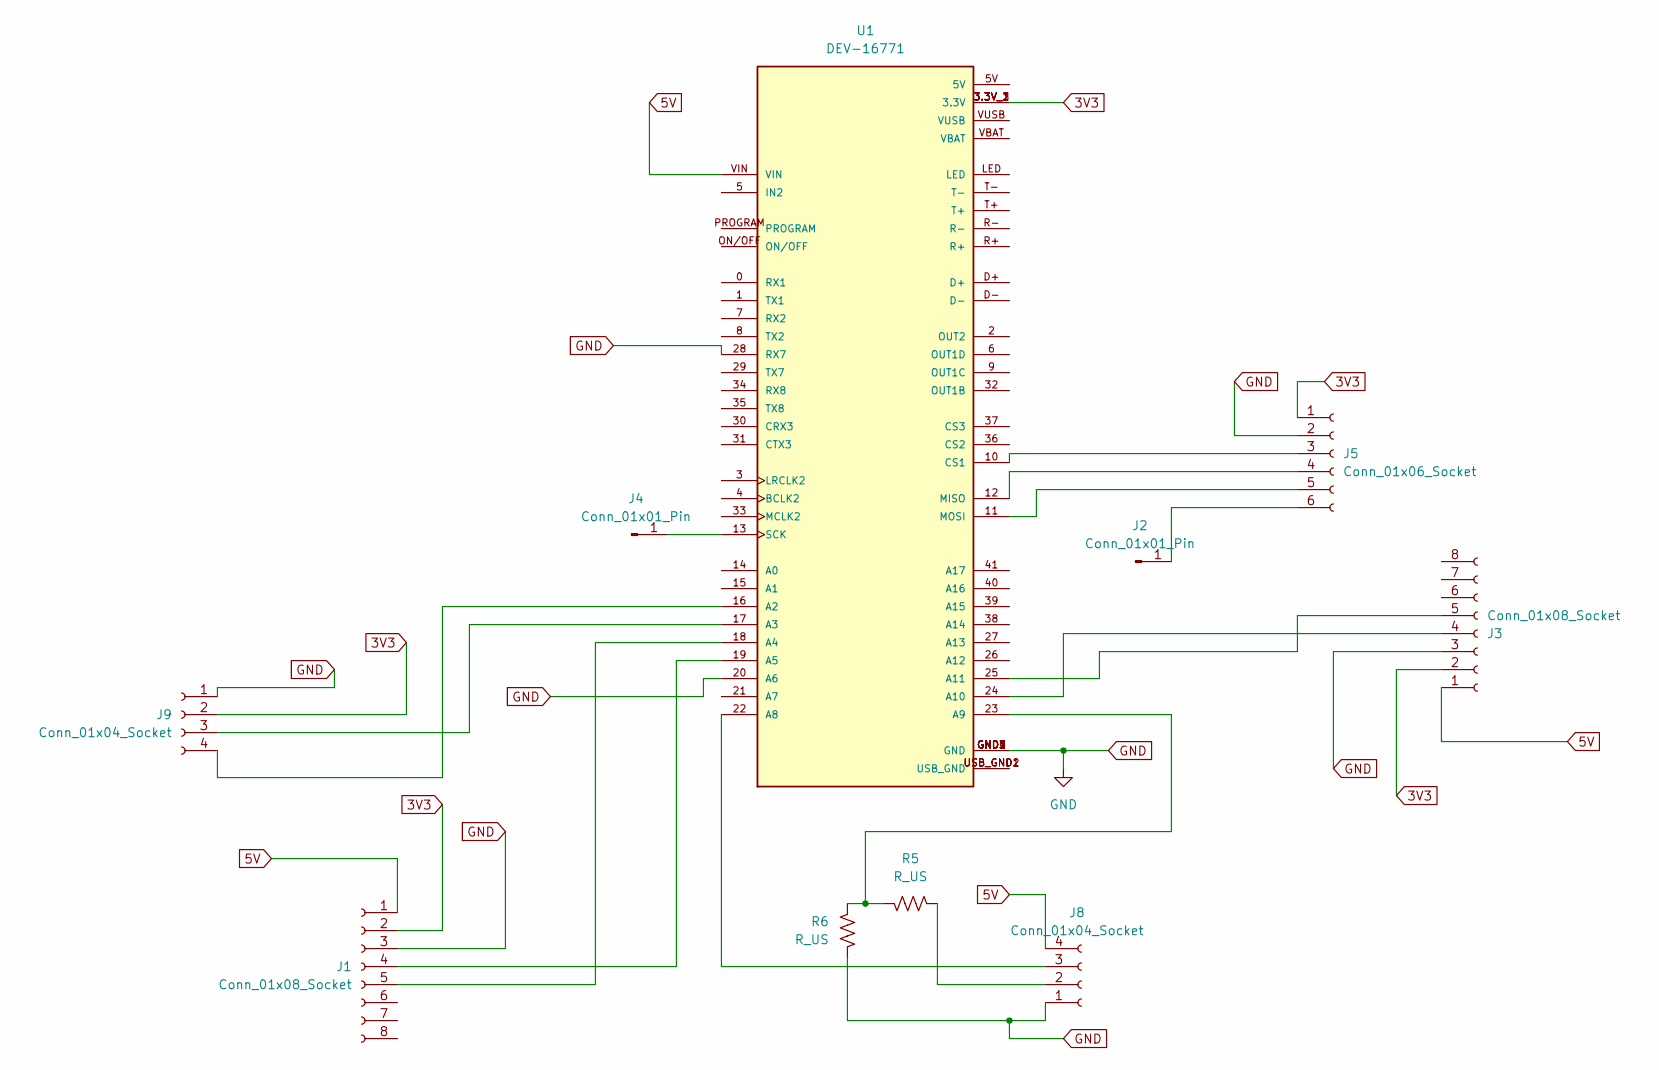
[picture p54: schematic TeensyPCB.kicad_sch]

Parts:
J1, J3: Conn_01x08_Socket; PinHeader_1x08_P2.54mm_Vertical
J2, J4: Conn_01x01_Pin; PinHeader_1x01_P2.54mm_Vertical
J5: Conn_01x06_Socket; PinHeader_1x06_P2.54mm_Vertical
J8, J9: Conn_01x04_Socket; PinHeader_1x04_P2.54mm_Vertical
R5, R6: R_US; R_Axial_DIN0207_L6.3mm_D2.5mm_P10.16mm_Horizontal
U1: DEV-16771; MODULE_DEV-16771; PARTREV 4.1

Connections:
3V3: J1.2, J3.2, J5.1, J9.2, U1.3.3V_1 (3.3V), U1.3.3V_2 (3.3V), U1.3.3V_3 (3.3V)
5V: J1.1, J3.1, J8.4, U1.VIN
GND: J1.3, J3.3, J5.2, J8.1, J9.1, R6.2, U1.20 (A6), U1.28 (RX7), U1.GND1 (GND), U1.GND2 (GND), U1.GND3 (GND), U1.GND4 (GND), U1.GND5 (GND)
unnamed: J1.4, U1.19 (A5)
unnamed: J1.5, U1.18 (A4)
unnamed: J2.1, J5.6
unnamed: J3.4, U1.24 (A10)
unnamed: J3.5, U1.25 (A11)
unnamed: J4.1, U1.13 (SCK)
unnamed: J5.3, U1.10 (CS1)
unnamed: J5.4, U1.12 (MISO)
unnamed: J5.5, U1.11 (MOSI)
unnamed: J8.2, R5.1
unnamed: J8.3, U1.22 (A8)
unnamed: J9.3, U1.17 (A3)
unnamed: J9.4, U1.16 (A2)
unnamed: R5.2, R6.1, U1.23 (A9)
unnamed: U1.USB_GND1 (USB_GND), U1.USB_GND2 (USB_GND)

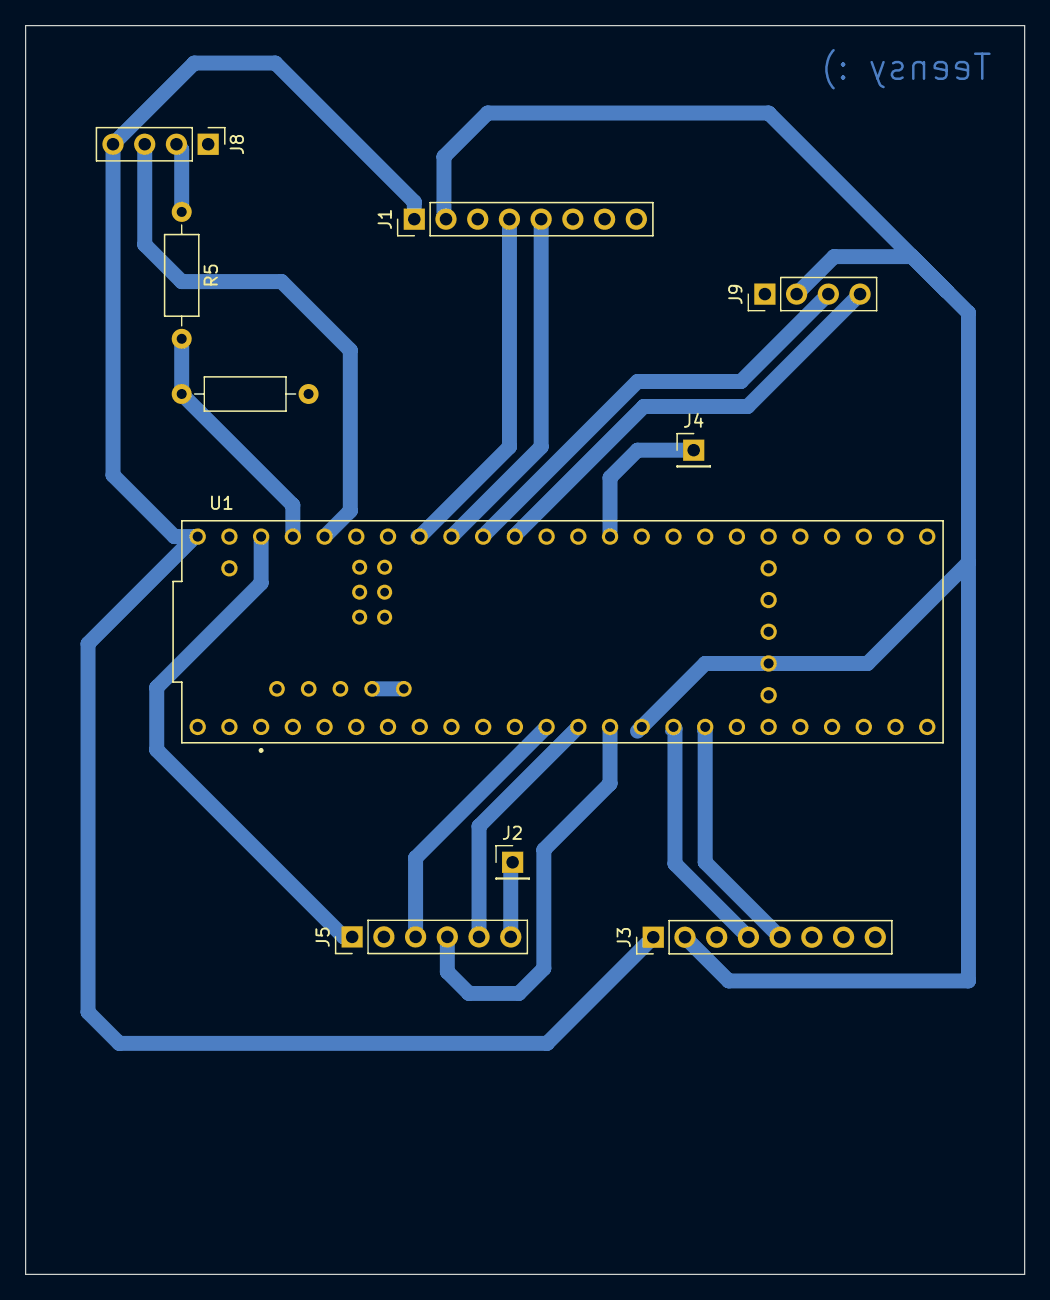
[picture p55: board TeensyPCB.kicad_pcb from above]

Board: 2 copper layers, 80.0 x 100.0 mm, 10 parts (0 on the bottom side), 18 nets.

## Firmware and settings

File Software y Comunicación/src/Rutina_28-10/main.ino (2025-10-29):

#include <Arduino.h>
#include <ODriveTeensyCAN.h>
#include <FlexCAN_T4.h>        // <–– esto debe estar
#include <Wire.h>
#include <Adafruit_GFX.h>
#include <Adafruit_SSD1306.h>
#include <pitches.h>

#define SCREEN_WIDTH  128
#define SCREEN_HEIGHT  64
#define OLED_RESET    -1          // Reset por software (GPIO no usado)
#define LOGO_WIDTH  84
#define LOGO_HEIGHT 52
#define BUZZER_PIN 6
#define PIN_BOTON 38
#define PRESSED LOW
#define NOT_PRESSED HIGH
ODriveTeensyCAN odriveCAN(250000);  // Configuración CAN
Adafruit_SSD1306 display(SCREEN_WIDTH, SCREEN_HEIGHT, &Wire, OLED_RESET);

//----------------CONFIGURACIÓN BUZZER-------------------------------
int melodynokia[] = {
  NOTE_E5, NOTE_D5, NOTE_FS4, NOTE_GS4, 
  NOTE_CS5, NOTE_B4, NOTE_D4, NOTE_E4, 
  NOTE_B4, NOTE_A4, NOTE_CS4, NOTE_E4,
  NOTE_A4
};
int durations[] = {
  8, 8, 4, 4,
  8, 8, 4, 4,
  8, 8, 4, 4,
  2
};
const int melody[] = { 262, 294, 330, 349, 330, 294, 262 };   // C4–D4–E4–F4–E4–D4–C4
const int noteDurations[] = { 200, 200, 200, 200, 200, 200, 400 };
const int melodyLength = sizeof(melody) / sizeof(melody[0]);

const int melodyHigh[] = { 392, 440, 494, 523, 494, 440, 392 };
const int noteDurationsHigh[] = { 150, 150, 150, 200, 150, 150, 300 };
const int melodyHighLength = sizeof(melodyHigh) / sizeof(melodyHigh[0]);

//------ Marcha imperial

int ImperialMarch [] = {
  
  // Dart Vader theme (Imperial March) - Star wars 
  // Score available at https://musescore.com/user/202909/scores/1141521
  // The tenor saxophone part was used
  
  // NOTE_A4,-4, NOTE_A4,-4, NOTE_A4,16, NOTE_A4,16, NOTE_A4,16, NOTE_A4,16, NOTE_F4,8, REST,8,
  // NOTE_A4,-4, NOTE_A4,-4, NOTE_A4,16, NOTE_A4,16, NOTE_A4,16, NOTE_A4,16, NOTE_F4,8, REST,8,
  NOTE_A4,4, NOTE_A4,4, NOTE_A4,4, NOTE_F4,-8, NOTE_C5,16,

  NOTE_A4,4, NOTE_F4,-8, NOTE_C5,16, NOTE_A4,2,//4
  NOTE_E5,4, NOTE_E5,4, NOTE_E5,4, NOTE_F5,-8, NOTE_C5,16,
  NOTE_A4,4, NOTE_F4,-8, NOTE_C5,16, NOTE_A4,2,
  
  NOTE_A5,4, NOTE_A4,-8, NOTE_A4,16, NOTE_A5,4, NOTE_GS5,-8, NOTE_G5,16, //7 
  NOTE_DS5,16, NOTE_D5,16, NOTE_DS5,8, REST,8, NOTE_A4,8, NOTE_DS5,4, NOTE_D5,-8, NOTE_CS5,16,

  NOTE_C5,16, NOTE_B4,16, NOTE_C5,16, REST,8, NOTE_F4,8, NOTE_GS4,4, NOTE_F4,-8, NOTE_A4,-16,//9
  NOTE_C5,4, NOTE_A4,-8, NOTE_C5,16, NOTE_E5,2,

  // NOTE_A5,4, NOTE_A4,-8, NOTE_A4,16, NOTE_A5,4, NOTE_GS5,-8, NOTE_G5,16, //7 
  // NOTE_DS5,16, NOTE_D5,16, NOTE_DS5,8, REST,8, NOTE_A4,8, NOTE_DS5,4, NOTE_D5,-8, NOTE_CS5,16,

  // NOTE_C5,16, NOTE_B4,16, NOTE_C5,16, REST,8, NOTE_F4,8, NOTE_GS4,4, NOTE_F4,-8, NOTE_A4,-16,//9
  // NOTE_A4,4, NOTE_F4,-8, NOTE_C5,16, NOTE_A4,2,
  
};

int tempo = 97;
int wholenote = (60000 * 4) / tempo;
int divider = 0;
int noteDuration = 0;
int notes = sizeof(ImperialMarch) / sizeof(ImperialMarch[0]) / 2;

//-----------CONFIGURACIÓN DISPLAY-----------------------
struct frameOLA{
  char fecha[11];
  char hora[11];
  float accX, accY, accZ;
  float gyroX, gyroY, gyroZ;
  float magX, magY, magZ;
  float temp;
  float freq;
} data;
constexpr int Buff_len = 128;
char Buff[Buff_len];

const unsigned char PROGMEM logo[] = {
	0x00, 0x00, 0x00, 0x00, 0x00, 0x00, 0x00, 0x00, 0x00, 0x00, 0x00, 0x00, 0x00, 0x00, 0x00, 0x00, 
	0x00, 0x00, 0x00, 0x00, 0x00, 0x00, 0x00, 0x00, 0x00, 0x00, 0x00, 0x00, 0x00, 0x00, 0x00, 0x00, 
	0x00, 0x00, 0x00, 0x00, 0x00, 0x00, 0x00, 0x00, 0x00, 0x00, 0x00, 0x00, 0x00, 0x00, 0x00, 0x00, 
	0x00, 0x00, 0x00, 0x00, 0x00, 0x00, 0x00, 0x00, 0x00, 0x00, 0x00, 0x00, 0x00, 0x00, 0x00, 0x00, 
	0x00, 0x00, 0x00, 0x00, 0x00, 0x00, 0x00, 0x00, 0x00, 0x00, 0x00, 0x00, 0x00, 0x00, 0x00, 0x00, 
	0x00, 0x00, 0x00, 0x00, 0x00, 0x00, 0x00, 0x00, 0x00, 0x00, 0x00, 0x00, 0x00, 0x00, 0x00, 0x00, 
	0x00, 0x00, 0x00, 0x00, 0x00, 0x00, 0x00, 0x00, 0x00, 0x00, 0x00, 0x00, 0x00, 0x00, 0x00, 0x00, 
	0x00, 0x00, 0x00, 0x00, 0x00, 0x00, 0x00, 0x00, 0x00, 0x00, 0x00, 0x00, 0x00, 0x00, 0x00, 0x00, 
	0x00, 0x00, 0x00, 0x00, 0x00, 0x00, 0x00, 0x00, 0x00, 0x00, 0x00, 0x00, 0x00, 0x00, 0x00, 0x00, 
	0x00, 0x00, 0x00, 0x00, 0x00, 0x00, 0x00, 0x00, 0x00, 0x00, 0x00, 0x00, 0x00, 0x00, 0x00, 0x00, 
	0x00, 0x00, 0x00, 0x00, 0x00, 0x00, 0x00, 0x00, 0x00, 0x00, 0x00, 0x00, 0x00, 0x00, 0x00, 0x00, 
	0x00, 0x00, 0x00, 0x00, 0x00, 0x00, 0x00, 0x00, 0x00, 0x00, 0x00, 0x00, 0x00, 0x00, 0x00, 0x00, 
	0x00, 0x00, 0x00, 0x00, 0x00, 0x00, 0x00, 0x00, 0x00, 0x00, 0x00, 0x00, 0x00, 0x00, 0x00, 0x00, 
	0x00, 0x00, 0x00, 0x00, 0x00, 0x00, 0x00, 0x00, 0x00, 0x00, 0x00, 0x00, 0x00, 0x00, 0x00, 0x00, 
	0x00, 0x00, 0x00, 0x00, 0x00, 0x00, 0x00, 0x00, 0x00, 0x00, 0x00, 0x00, 0x00, 0x00, 0x00, 0x00, 
	0x00, 0x00, 0x00, 0x00, 0x00, 0x00, 0x00, 0x00, 0x00, 0x00, 0x00, 0x00, 0x00, 0x00, 0x00, 0x00, 
	0x00, 0x00, 0x00, 0x00, 0x00, 0x00, 0x00, 0x00, 0x00, 0x00, 0x00, 0x00, 0x00, 0x00, 0x00, 0x00, 
	0x00, 0x00, 0x00, 0x00, 0x00, 0x00, 0x00, 0x00, 0x00, 0x00, 0x00, 0x00, 0x00, 0x00, 0x00, 0x00, 
	0x00, 0x00, 0x00, 0x00, 0x00, 0x00, 0x00, 0x00, 0x00, 0x00, 0x00, 0x00, 0x00, 0x00, 0x00, 0x00, 
	0x00, 0x00, 0x00, 0x00, 0x00, 0x00, 0x00, 0x00, 0x00, 0x00, 0x00, 0x00, 0x00, 0x00, 0x00, 0x00, 
	0x00, 0x00, 0x00, 0x00, 0x00, 0x00, 0x00, 0x00, 0x00, 0x00, 0x00, 0x00, 0x00, 0x00, 0x00, 0x00, 
	0x00, 0x00, 0x00, 0x00, 0x00, 0x00, 0x00, 0x00, 0x00, 0x00, 0x00, 0x00, 0x00, 0x00, 0x00, 0x00, 
	0x00, 0x00, 0x00, 0x00, 0x00, 0x00, 0x00, 0x00, 0x00, 0x00, 0x00, 0x00, 0x00, 0x00, 0x00, 0x00, 
	0x00, 0x00, 0x00, 0x00, 0x10, 0x00, 0x00, 0x00, 0x00, 0x00, 0x00, 0x08, 0x00, 0x00, 0x00, 0x00, 
	0x00, 0x00, 0x00, 0x00, 0x08, 0x00, 0x00, 0x00, 0x00, 0x00, 0x00, 0x38, 0x00, 0x00, 0x00, 0x00, 
	0x00, 0x00, 0x00, 0x00, 0x00, 0x00, 0x00, 0x00, 0x00, 0x00, 0x00, 0xf0, 0x00, 0x00, 0x00, 0x00, 
	0x00, 0x00, 0x00, 0x00, 0x05, 0x80, 0x00, 0x00, 0x00, 0x00, 0x01, 0xf0, 0x00, 0x00, 0x00, 0x00, 
	0x00, 0x00, 0x00, 0x00, 0x05, 0x80, 0x00, 0x00, 0x00, 0x00, 0x03, 0xe0, 0x00, 0x00, 0x00, 0x00, 
	0x00, 0x00, 0x00, 0x00, 0x00, 0x08, 0x00, 0x00, 0x00, 0x00, 0x09, 0xe0, 0x00, 0x00, 0x00, 0x00, 
	0x00, 0x00, 0x00, 0x00, 0x00, 0x4f, 0x00, 0x00, 0x00, 0x00, 0x6c, 0xc0, 0x00, 0x00, 0x00, 0x00, 
	0x00, 0x00, 0x00, 0x00, 0x00, 0xdf, 0x00, 0x00, 0x00, 0x03, 0xce, 0x00, 0x00, 0x00, 0x00, 0x00, 
	0x00, 0x00, 0x00, 0x00, 0x00, 0xde, 0x1c, 0x00, 0x00, 0x0f, 0xdf, 0x00, 0x00, 0x00, 0x00, 0x00, 
	0x00, 0x00, 0x00, 0x00, 0x00, 0x58, 0x9f, 0x10, 0x0f, 0xc7, 0xde, 0x00, 0x00, 0x00, 0x00, 0x00, 
	0x00, 0x00, 0x00, 0x00, 0x00, 0x03, 0x9e, 0x1f, 0x3f, 0x97, 0xde, 0x00, 0x00, 0x00, 0x00, 0x00, 
	0x00, 0x00, 0x00, 0x00, 0x00, 0x0f, 0xbc, 0x9e, 0x3f, 0xb3, 0xd8, 0x00, 0x00, 0x00, 0x00, 0x00, 
	0x00, 0x00, 0x00, 0x00, 0x00, 0x0f, 0xb9, 0xde, 0xbf, 0x3b, 0x90, 0x00, 0x00, 0x00, 0x00, 0x00, 
	0x00, 0x00, 0x00, 0x00, 0x00, 0x03, 0xb3, 0xdd, 0x9f, 0x79, 0x80, 0x00, 0x00, 0x00, 0x00, 0x00, 
	0x00, 0x00, 0x00, 0x00, 0x00, 0x01, 0xa7, 0xd9, 0xdf, 0x7d, 0x80, 0x00, 0x00, 0x00, 0x00, 0x00, 
	0x00, 0x00, 0x00, 0x00, 0x00, 0x00, 0x0f, 0xdb, 0xde, 0xfe, 0x00, 0x00, 0x00, 0x00, 0x00, 0x00, 
	0x00, 0x00, 0x00, 0x00, 0x00, 0x00, 0x1f, 0xd3, 0xde, 0xf8, 0x00, 0x00, 0x00, 0x00, 0x00, 0x00, 
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


//-------------------BOTONES E IMU-----------------
bool modoIMU = false;               // false: muestra imagen, true: muestra datos
bool currentState;
const unsigned long shortPress = 30;
const unsigned long  longPress = 1500;
const int debounce = 30;
unsigned long counter=0;
bool prevState = NOT_PRESSED;

bool flagShort = false;
bool flagLong  = false;

//-------------CONFIGURACIÓN MOTORES------------------------

// La estructura 'MotorConfig' define las propiedades de cada motor.
struct MotorConfig {          //Estructura de Configuración
  uint8_t node_id;            // Node ID en el bus CAN
  float pos_a;                // Posición 1 (vueltas)
  float pos_b;                // Posición 2 (vueltas)
  float current_target;       // Último objetivo enviado
  unsigned long lastMoveTime; // Último cambio
  unsigned long intervalo_ms; // Intervalo entre movimientos
  float last_position_deg;    // Última posición en grados
  float last_current_A;       // Última corriente
};

// ---------------NOO CAAMBIAAR!!--------------

MotorConfig motores[] = {
  {0, 0.0, -2.5, 0.0, 0, 4000, 0.0, 0.0},      // Motor con Node ID 1
  {1, 0.0, 2.5, 0.0, 0, 4000, 0.0, 0.0},        // Motor con Node ID 0
  {2, 0.0, -0.5, 0.0, 0, 4000, 0.0, 0.0},       // Motor con Node ID 2
  {3, 0.0, 0.5, 0.0, 0, 4000, 0.0, 0.0},         // Motor con Node ID 3
  {4, 0.0, -0.3, 0, 0, 5000, 0,0},
  {5, 0.0, 0.3, 0, 0, 5000, 0,0}     
};

const int num_motores = sizeof(motores) / sizeof(MotorConfig);  //Se calcula automáticamente para saber cuántos motores hay.
const int espera = 700;

// ------------VARIABLES DE CONTROL DE ESTADOS----------------
enum Estado { MENU, EJECUTANDO, DETENIENDO };  // Se define un 'enum' para los estados del programa (código más legible)
Estado estado = MENU; // Estado inicial del programa.
char rutina_seleccionada = 0;// Almacena la opción de rutina ('1', '2').
bool detener_rutina = false;// Bandera para indicar si se debe detener la rutina actual.

void setup() {
  Serial.begin(115200);
  Serial2.begin(115200);         // UART2 (pines 7-8)
  while (!Serial);
  while (!Serial2);
  Wire1.begin();                  // inicia bus I²C en pins 17/16
  Wire1.setClock(400000);         // 400 kHz (rápido y estable)

  pinMode(PIN_BOTON, INPUT_PULLUP);

  if (!display.begin(SSD1306_SWITCHCAPVCC, 0x3C)) { // dirección 0x3C
    while (true) {
      // Si falla, parpadea el LED integrado
      digitalToggle(LED_BUILTIN);
      delay(200);
    }
  }

  //Sonrisa inicial
  display.clearDisplay();
  display.drawBitmap(0,0,logo,128,64,WHITE);
  display.display();


  bool ejesOk[num_motores] = {false};
  bool errorMostrado[num_motores] = {false};

  //------ LÓGICA DE INICIALIZACIÓN Y CHEQUEO DE MOTORES ----------
  while (true) {                  // Bucle principal para asegurar que todos los motores estén en el estado correcto.
    int motoresPendientes = 0;
    for (int i = 0; i < num_motores; i++) {
      if (ejesOk[i]) continue;      // Si este motor ya está OK, salta al siguiente.
      
      odriveCAN.RunState(motores[i].node_id, 8);// Envía un comando CAN (id=8) para poner el motor modo closed-loop control

      uint32_t axisError = 0;
      uint8_t estadoActual = 0;
      bool ok = false;
      unsigned long start = millis();
      while (millis() - start < 1200) {
        CAN_message_t msg;
        // Procesa los mensajes CAN entrantes.
        while (odriveCAN.ReadMsg(msg)) {
          uint8_t node_id = (msg.id >> 5);
          if (node_id == motores[i].node_id &&
              (msg.id & 0x1F) == ODriveTeensyCAN::CMD_ID_ODRIVE_HEARTBEAT_MESSAGE) {
            HeartbeatMsg_t hb;
            odriveCAN.Heartbeat(hb, msg);
            axisError = hb.axisError;
            estadoActual = hb.currentState;
            if (axisError == 0 && estadoActual == 8) {
              ok = true;
              break;
            }
          }
        }
        if (ok) break;
        delay(10);
      }

      if (ok) {
        ejesOk[i] = true;
        Serial.print("Axis ");
        Serial.print(motores[i].node_id);
        Serial.println(" en modo cerrado OK.");
      } else {
        motoresPendientes++;
        if (!errorMostrado[i]) {
          Serial.print("ERROR: Axis "); Serial.print(motores[i].node_id);
          Serial.print(" NO entró en lazo cerrado (estado actual: ");
          Serial.print(estadoActual); Serial.print("). axisError: 0x");
          Serial.println(axisError, HEX);
          errorMostrado[i] = true;
        }
      }
      
    }
    imprimirHeartbeats();

    if (motoresPendientes == 0) break; // Todos OK, salimos del bucle
    delay(1000); // Espera antes de reintentar (silenciosamente)
  }

  ImperialMarchfun();

  Serial.println("Sistema iniciado.");
  Serial.println("Seleccione un modo:");
  Serial.println("[1] Axis Tests");
  Serial.println("[2] Walking On Sunshine");
  Serial.println("[3] Ejecutar extension");
  Serial.println("[9] Para cambiar modo IMU");
  Serial.println("Presione brevemente el botón para Axis_Test");
  Serial.println("Presione por 2 segundos el botón para Walking On Sunshine");
  Serial.println("Para detener una rutina en ejecución, presione [s] y Enter.");
}


void loop() {
  //leerDatosCAN();
  leerErroresCAN();

  size_t n = Serial2.readBytesUntil('\n', Buff, Buff_len - 1);
  if (n > 0) {
    Buff[n] = '\0';
  } else {
    Buff[0] = '\0';
  }
  // 2) Parseo de los datos recién leídos
  parsearIMU();
  if (modoIMU) {
    visualizarIMU(); 
  }
  millisBoton();
  // ========================= MENU =========================
  
  static char c = 0;   // guarda el último dígito tecleado
  if (estado == MENU) {
    while (Serial.available() > 0) {
      char Car = Serial.read();
      Serial.write(Car);
      if (Car >= '0' && Car <= '9') {
      // Guarda el último dígito que escribiste
      c = Car;
      }
      if (Car == '\n'){        
        if (c == '1') {
          //playLowMelody(); 
          rutina_seleccionada = '1';
          estado = EJECUTANDO;
        } else if (c == '2') {
          //playHighMelody();
          rutina_seleccionada = '2';
          estado = EJECUTANDO;
        } else if (c == '3'){
          rutina_seleccionada = '3';
          estado = EJECUTANDO;
        } else if (c == '9') {
          // Alterna la bandera
          modoIMU = !modoIMU;


          // Si volvemos a carita, la dibujamos de una vez
          if (modoIMU) {
            visualizarIMU();
            Serial.println(">> Mostrando senseo IMU");
            Serial.println(" ");
            Serial.println("Seleccione un modo:");
            Serial.println("[1] Axis Tests");
            Serial.println("[2] Walking On Sunshine");
            Serial.println("[3] Ejecutar extension");
            Serial.println("[9] Para cambiar modo IMU");
            Serial.println("Presione brevemente el botón para Axis_Test");
            Serial.println("Presione por 2 segundos el botón para Walking On Sunshine");
            Serial.println("Para detener una rutina en ejecución, presione [s] y Enter.");
    
          }
          else {
            mostrarSonrisa();
            Serial.println(" ");
            Serial.println("Seleccione un modo:");
            Serial.println("[1] Axis Tests");
            Serial.println("[2] Walking On Sunshine");
            Serial.println("[3] Ejecutar extension");
            Serial.println("[9] Para cambiar modo IMU");
            Serial.println("Presione brevemente el botón para Axis_Test");
            Serial.println("Presione por 2 segundos el botón para Walking On Sunshine");
            Serial.println("Para detener una rutina en ejecución, presione [s] y Enter.");
 
          }
        }
        c = 0;
      }              
     }   
    }

  else if (estado == EJECUTANDO) {
    detener_rutina = false;
    if (rutina_seleccionada == '1') {
      playMelody(); 
      Rutina_A();
    } 
    else if (rutina_seleccionada == '2') {
      playHighMelody();
      Rutina_B();
    }
    else if (rutina_seleccionada == '3') {
      playNokia();
      Rutina_C();
    }
    //millisBoton();
    if (flagLong) {
      PushLong();   
      flagLong = false; 
    }

    if (flagShort) {
      PushShort();        
      flagShort = false;
    }

    // Al terminar, volver a posiciones originales
    Serial.println(">> Volviendo a posición original...");
    delay(100);
    moverMotoresAPosicionInicial();
    estado = MENU;
    rutina_seleccionada = 0;
    R2D2_Beep();
    Serial.println(" ");
    Serial.println("Seleccione un modo:");
    Serial.println("[1] Axis Tests");
    Serial.println("[2] Walking On Sunshine");
    Serial.println("[3] Ejecutar extension");
    Serial.println("[9] Para cambiar modo IMU");
    Serial.println("Presione brevemente el botón para Axis_Test");
    Serial.println("Presione por 2 segundos el botón para Walking On Sunshine");
    Serial.println("Para detener una rutina en ejecución, presione [s] y Enter.");
    }
    
  delay(10);
}

// Rutina A: Pero chequea si hay stop
void Rutina_A() {
  Serial.println(">> Ejecutando Axis Tests...");
  for (int m = 0; m < num_motores; m++) {
    leerErroresCAN();
    if (checkearStop()) return;
    odriveCAN.SetPosition(motores[m].node_id, motores[m].pos_a);
    esperarConInterrupcion(espera);
    if (checkearStop()) return;
    odriveCAN.SetPosition(motores[m].node_id, motores[m].pos_b);
    esperarConInterrupcion(espera);
    if (checkearStop()) return;
    odriveCAN.SetPosition(motores[m].node_id, motores[m].pos_a);
    esperarConInterrupcion(espera);
    
  }
  //Serial.println(">> Modo completado.");
}

// Rutina B: Simular caminata
void Rutina_B() {
  Serial.println(">> Ejecutando Walking On Sunshine...");
  for (int contador = 0; contador < 15; contador++){
    //Mover Pierna Izquierda
//Mover Pierna Izquierda
    odriveCAN.SetPosition(motores[0].node_id, motores[0].pos_b);  // Posición objetivo 0 extensión pantorilla
    esperarConInterrupcion(100);
    odriveCAN.SetPosition(motores[3].node_id, motores[3].pos_b);  // Posición objetivo 2 extensión rodilla
    esperarConInterrupcion(900);
    odriveCAN.SetPosition(motores[0].node_id, motores[0].pos_a);  // Regreso a inicial      -1
    esperarConInterrupcion(20);
    odriveCAN.SetPosition(motores[3].node_id, motores[3].pos_a);  // Regreso a inicial

    esperarConInterrupcion(10);

    //Mover Pierna Derecha
    odriveCAN.SetPosition(motores[1].node_id, motores[1].pos_b);  // Posición objetivo 1 extensión pantorrilla
    esperarConInterrupcion(100);
    odriveCAN.SetPosition(motores[2].node_id, motores[2].pos_b);  // Posición objetivo 3 extensión rodilla
    esperarConInterrupcion(900);
    odriveCAN.SetPosition(motores[1].node_id, motores[1].pos_a);  // Regreso a inicial      1
    esperarConInterrupcion(20);
    odriveCAN.SetPosition(motores[2].node_id, motores[2].pos_a);  // Regreso a inicial
  }
  esperarConInterrupcion(1000);
  //Serial.println(">> Modo completado");
}
void Rutina_C() {
  Serial.println(">> Ejecutando última rutina...");
  odriveCAN.SetPosition(motores[0].node_id, -3.5);  // der
  esperarConInterrupcion(800);
  odriveCAN.SetPosition(motores[1].node_id, 3.5);  // der
  esperarConInterrupcion(800);
  //odriveCAN.SetPosition(motores[4].node_id, motores[4].pos_b);  // Posición objetivo 1 extensión pantorrilla
  //esperarConInterrupcion(2000);
  //odriveCAN.SetPosition(motores[5].node_id, motores[5].pos_b);  // Posición objetivo 1 extensión pantorrilla
  //esperarConInterrupcion(2000);

float pos_b_forward3= -0.9;    //Hacia atrás 0.5
float pos_b_forward2= 0.9;     //Hacia atrás -0.5

for (int contador = 0; contador < 8; contador++){
  odriveCAN.SetPosition(motores[3].node_id,pos_b_forward3);  // Posición objetivo 3 extensión rodilla
  esperarConInterrupcion(600);
  odriveCAN.SetPosition(motores[3].node_id, motores[3].pos_a);  // Posición objetivo 1 extensión pantorrilla
  esperarConInterrupcion(500);
  odriveCAN.SetPosition(motores[2].node_id,pos_b_forward2);  // Regreso a inicial      1
  esperarConInterrupcion(600);
  odriveCAN.SetPosition(motores[2].node_id, motores[2].pos_a);  // Posición objetivo 3 extensión rodilla
  esperarConInterrupcion(500);
  }
  esperarConInterrupcion(1000);;
}

void esperarConInterrupcion(unsigned long ms) {
  unsigned long start = millis();
  while (millis() - start < ms) {
    if (Serial.available() > 0 && Serial.read() == 's') {
      Serial.println("Rutina detenida por el usuario.");
      detener_rutina = true;
      break;
    }
    delay(10);  // Evita saturar el micro
  }
}

bool checkearStop() {
  if (detener_rutina) {
    Serial.println("Deteniendo rutina, saliendo...");
    return true;
  }
  return false;
}

// Mueve todos los motores a pos_a (posición original)
void moverMotoresAPosicionInicial() {
  const int repeticiones = 5;
  const int intervalo = 20;  // ms entre cada repetición (debe ser menor que el watchdog timeout)

  for (int r = 0; r < repeticiones; r++) {
    for (int i = 0; i < num_motores; i++) {
      odriveCAN.SetPosition(motores[i].node_id, motores[i].pos_a);
    }
    delay(intervalo);
  }
}


void leerErroresCAN() {
  CAN_message_t msg;
  while (odriveCAN.ReadMsg(msg)) {
    uint8_t node_id = (msg.id >> 5);
    if ((msg.id & 0x1F) == ODriveTeensyCAN::CMD_ID_ODRIVE_HEARTBEAT_MESSAGE) {
      HeartbeatMsg_t hb;
      odriveCAN.Heartbeat(hb, msg);
      if (hb.axisError != 0) {
        Serial.print("[ERROR] Axis "); Serial.print(node_id);
        Serial.print(": axisError = 0x"); Serial.println(hb.axisError, HEX);
        odriveCAN.RunState(node_id, 1); // Pone el eje en IDLE
      }
      if (hb.currentState != 8) { // Aquí va currentState, no axisState
        Serial.print("[ADVERTENCIA] Axis "); Serial.print(node_id);
        Serial.print(" fuera de Closed Loop. Estado: "); Serial.println(hb.currentState);
      }
    }
    // Agrega chequeos de otros mensajes aquí si lo necesitas
  }
}
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

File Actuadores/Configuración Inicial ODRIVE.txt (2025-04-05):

#Connected to ODrive 376433703433 as odrv0
#In [1]: odrv0.vbus_voltage
#Out[1]: 23.987035751342773

#In [20]: odrv0.erase_configuration()
#Oh no odrv0 disappeared

#Reconnected to ODrive 376433703433 as odrv0

## Driver Configuration
odrv0.config.brake_resistance = 2
odrv0.config.dc_bus_undervoltage_trip_level = 8.0
odrv0.config.dc_bus_overvoltage_trip_level = 56
odrv0.config.dc_max_positive_current = 20
odrv0.config.dc_max_negative_current = -5.0
odrv0.config.max_regen_current = 0
odrv0.save_configuration()

## Motor Configuration
odrv0.axis0.motor.config.pole_pairs = 20
odrv0.axis0.motor.config.calibration_current = 4
odrv0.axis0.motor.config.resistance_calib_max_voltage = 2
odrv0.axis0.motor.config.motor_type = MOTOR_TYPE_HIGH_CURRENT
odrv0.axis0.motor.config.current_lim = 22
odrv0.axis0.motor.config.requested_current_range = 40
odrv0.save_configuration()

## Encoder Configuration
odrv0.axis0.encoder.config.mode = ENCODER_MODE_SPI_ABS_AMS
odrv0.axis0.encoder.config.cpr = 16384
odrv0.axis0.encoder.config.bandwidth = 3000
odrv0.axis0.encoder.config.abs_spi_cs_gpio_pin = 7
odrv0.axis0.encoder.config.calib_range = 10
odrv0.save_configuration()


## Calibration Configuration
odrv0.axis0.config.calibration_lockin.current = 4
odrv0.axis0.config.calibration_lockin.ramp_time = 0.5
odrv0.axis0.config.calibration_lockin.ramp_distance = 3.1415927410125732
odrv0.axis0.config.calibration_lockin.accel = 20
odrv0.axis0.config.calibration_lockin.vel = 40
odrv0.save_configuration()

## Controller Configuration
odrv0.axis0.controller.config.control_mode = CONTROL_MODE_POSITION_CONTROL
odrv0.axis0.controller.config.pos_gain = 70
odrv0.axis0.controller.config.vel_gain = 0.02
odrv0.axis0.controller.config.vel_integrator_gain = 0.05
odrv0.axis0.controller.config.vel_limit = 80
odrv0.axis0.controller.config.input_mode = INPUT_MODE_TRAP_TRAJ
odrv0.axis0.trap_traj.config.vel_limit = 20
odrv0.axis0.trap_traj.config.accel_limit = 10
odrv0.axis0.trap_traj.config.decel_limit = 10

#Calibration Commands
odrv0.axis0.requested_state = AXIS_STATE_MOTOR_CALIBRATION
odrv0.axis0.motor.config.pre_calibrated = True
odrv0.axis0.requested_state = AXIS_STATE_ENCODER_OFFSET_CALIBRATION
odrv0.axis0.config.startup_encoder_offset_calibration = True
odrv0.axis0.config.startup_closed_loop_control = True

#States Commands
odrv0.axis0.requested_state = AXIS_STATE_CLOSED_LOOP_CONTROL     #Control
odrv0.axis0.requested_state = AXIS_STATE_IDLE                    #Defecto

#Troubleshooting Commands
print(odrv0.axis0.error)
print(odrv0.axis0.motor.error)
print(odrv0.axis0.encoder.error)
print(odrv0.axis0.controller.error)
print(odrv0.axis0.encoder.pos_estimate)
print(odrv0.axis0.requested_state)


#INPUTS Palanca 0
odrv0.axis0.controller.input_pos = 0   	     	#Referencia - Origen
odrv0.axis0.controller.input_pos = -0.25     	#Mitad pi/2
odrv0.axis0.controller.input_pos = -0.5     	#Pi
odrv0.axis0.controller.input_pos = -0.65	    #IMPACTO!!

odrv0.axis0.controller.input_pos = 90/360    #90°
odrv0.axis0.controller.input_pos = 180/360   #180°


#Ganancias Actuales
odrv0.axis0.controller.config.vel_gain = 0.04
odrv0.axis0.controller.config.vel_integrator_gain = 0.05
odrv0.axis0.controller.config.pos_gain = 70


odrv0.reboot()   #ENCENDER Y APAGAR

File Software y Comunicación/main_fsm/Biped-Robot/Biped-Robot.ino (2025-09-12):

String  version = "2025-08-16_B1P0_V.0.0.2";

/*
  Proyecto BIPO
	Bastian Inostroza
	German Inostroza
	Alonso Garrido

*/

/*
------------- Teensy 4.1 pinout --------------------

						<						 +--------+
				#   Analog   Digi|        |Digi  Analog
							  	    GND|        |VIN    
				0               0|        |GND    
				1               1|        |3V3    
				2               2|        |23    9
				3               3|        |22    8
				4               4|        |21    7
				5               5|        |20    6     
				6               6|        |19    5      SCL
				7               7|        |18    4			SDA
				8               8|        |17    3
				9               9|        |16    2
			 10              10|        |15    1
			 11              11|        |14    0
			 12              12|        |13    
			 13             3V3|        |GND    
		   14      10      24|        |41    17
			 15      11      25|        |40    16
			 16      12      26|        |39    15
			 17      13      27|        |38    14
			 18              28|        |37    
			 19              29|        |36    
			 20              30|        |35    
			 21              31|        |34    
			 22              32|        |33    
												 +--------+>

------------- MP2790 pinout --------------------



*/

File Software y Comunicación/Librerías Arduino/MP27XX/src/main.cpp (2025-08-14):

/*
 * I2C MP27xx Read Write
 *
 * Reads the value of each byte of the I2C MP27xx and prints it
 * to the computer.
 * This example code is in the public domain.
 */

#include <Arduino.h>
#include "MP2790.h"

//Global Variables
#define RED_BUTTON GPIO_NUM_14
uint16_t mp2790_nCells = 0x06;  //6 cells
uint16_t mp2790_address = 0x01; // Default address, can be changed later
bool mpStatus = false;

//Function declarations
void setupMP2790();
void setupValues();
void checkSensors();

// Initialize using MP27XX(i2c_address, number of cells).  
MP2790 mp27 = MP2790(mp2790_address, mp2790_nCells); //empty for default

void setup() {
  //Initialize serial and wait for port to open:
  Serial.begin(38400);
  while (!Serial) {
    ; // wait for serial port to connect. Needed for native USB port only
  } 

  //Initialize Wire/I2C
  #if I2CDEV_IMPLEMENTATION == I2CDEV_ARDUINO_WIRE
    Wire.begin(); 
  #elif I2CDEV_IMPLEMENTATION == I2CDEV_BUILTIN_FASTWIRE
    Fastwire::setup(400, true);
  #endif

  //Check MP2790 connection
  mpStatus = mp27.testConnection();

  //Initialize GPIO
  pinMode(RED_BUTTON, INPUT_PULLUP);
}


void loop() {

  //Setup sequence when button is pressed
  if (digitalRead(RED_BUTTON) == LOW) {
    Serial.println("Button pressed, initializing MP2790 Setup...");
    setupMP2790();
    setupValues();
    checkSensors();
  }

}

void setupMP2790() {

  // Check Address
  // uint16_t addressi2c = mp27.getAddress(); //reads address from object
  uint16_t addressi2c = mp27.readReg(MP2790_Reg::DEVICE_ADD); //reads address using register
  Serial.print("MP2790 I2C Address: ");
  Serial.println(addressi2c, HEX);
  
  // //Checking MTP status
  // Serial.println("Checking MTP status");
  // uint16_t mtpStatus = mp27.readReg(MP2790_Reg::MTP_STATUS); //by register
  // Serial.print("MTP Status: ");
  // Serial.println(mtpStatus, BIN);
  // Serial.print("MEMORY STATUS: ");
  // Serial.println(mp27.readAdd(MEM_STATUS), BIN); //by address

  // // //Writing new address
  // Serial.println("Writing new address");
  // mp27.setAddress(11);                                                   //writes 11 as device address on the go
  // // mp27.writeReg(MP2790_Reg::DEVICE_ADD, 11);                          //writes 11 to device register, needs to initialize
  // //// Serial.println(mp27.writeAdd(COMM_CFG, 0b00000000101100000000));  //writes 11 to device address, needs to initialize
  // Serial.println("Initializing new address");
  // mp27 = MP2790(11);                                                     //initializes with new address
  // // Re-Check Address
  // Serial.print("MP2790 I2C Address2: ");
  // addressi2c = mp27.readAdd(COMM_CFG);
  // Serial.println(addressi2c, HEX);
  // //Re-Check Connection
  // mp27.testConnection();


  // Storing toNVM page
  // Serial.println("Access code input");
  // mp27.storeAccessCode();
  // Serial.println("Storing NVM page");
  // if (mp27.storeNVM() != true) {
  //   Serial.println("Failed to store NVM page.");
  // } else {
  //   Serial.println("NVM page stored successfully.");
  // }

  // //Checking MTP satus
  // Serial.println("Checking MTP status");
  // uint16_t mtpStatus = mp27.checkMTPStatus();
  // Serial.print("MTP Status: ");
  // Serial.println(mtpStatus, HEX);

}
  
void setupValues(){

  // // Importing data
  Serial.println("Loading configuration values...");
  mp27.writeAdd(CELLS_CTRL, 0x00C3);
  mp27.writeAdd(ACT_CFG, 0x0000);
  mp27.writeAdd(STB_CFG, 0x0022);
  mp27.writeAdd(SAFE_CFG, 0x000D);
  mp27.writeAdd(RGL_CFG, 0x0005);
  mp27.writeAdd(LOAD_CHARGER_CFG, 0x0500);
  mp27.writeAdd(GPIO_OUT, 0x0000);
  mp27.writeAdd(GPIO_CFG, 0x0444);
  mp27.writeAdd(PINS_CFG, 0x0061);
  mp27.writeAdd(WDT_CFG_X, 0x4E9D);
  mp27.writeAdd(FET_CTRL, 0x0000);
  mp27.writeAdd(FET_MODE, 0x051B);
  mp27.writeAdd(FET_CFG_X, 0x68F0);
  mp27.writeAdd(INT0_EN, 0xC7FF);
  mp27.writeAdd(INT1_EN, 0x2FFE);
  mp27.writeAdd(INT_TYPE0, 0x0000);
  mp27.writeAdd(INT_TYPE1, 0x0000);
  mp27.writeAdd(INT_TYPE2, 0x0000);
  mp27.writeAdd(MASK_INT0, 0x00FF);
  mp27.writeAdd(MASK_INT1, 0x0140);
  mp27.writeAdd(OCFT_CTRL, 0x01BF);
  mp27.writeAdd(DSGOC_LIM, 0x2C19);
  mp27.writeAdd(DSGOC_DEG, 0x0428);
  mp27.writeAdd(CHGOC_DEG, 0x0404);
  mp27.writeAdd(SCFT_CTRL, 0x003F);
  mp27.writeAdd(DSGSC_CFG, 0x0115);
  mp27.writeAdd(CHGSC_CFG, 0x0804);
  mp27.writeAdd(PACKFT_CTRL, 0x1B33);
  mp27.writeAdd(CELLFT_CTRL, 0x6036);
  mp27.writeAdd(CELL_HYST, 0x0AA0);
  mp27.writeAdd(PACK_UV_OV, 0x8080);
  mp27.writeAdd(CELL_UV_X, 0x009F);
  mp27.writeAdd(CELL_OV_X, 0x00D7);
  mp27.writeAdd(PACK_UV, 0x0276);
  mp27.writeAdd(PACK_OV, 0x0355);
  mp27.writeAdd(CELL_DEAD_THR, 0x0068);
  mp27.writeAdd(CELL_MSMT, 0x0002);
  mp27.writeAdd(NTC_CLR, 0x0000);
  mp27.writeAdd(DIE_CFG, 0x000A);
  mp27.writeAdd(NTC_CFG, 0xE4F5);
  mp27.writeAdd(NTCC_OTHR_DSG, 0x012E);
  mp27.writeAdd(NTCC_UTHR_DSG, 0x0294);
  mp27.writeAdd(NTCC_OTHR_CHG, 0x012E);
  mp27.writeAdd(NTCC_UTHR_CHG, 0x8A94);
  mp27.writeAdd(NTCM_OTHR, 0x80EB);
  mp27.writeAdd(DIE_OT, 0xAAEC);
  mp27.writeAdd(SELF_STS, 0x0000);
  mp27.writeAdd(SFT_GO, 0x0501);
  mp27.writeAdd(SELF_CFG, 0x470F);
  mp27.writeAdd(OPEN_CFG, 0x0407);
  mp27.writeAdd(REGIN_UV, 0x016D);
  mp27.writeAdd(V3P3_UV, 0x00F0);
  mp27.writeAdd(VDD_UV, 0x0084);
  mp27.writeAdd(SELF_THR, 0x6555);
  mp27.writeAdd(FT_REC, 0x1000);
  mp27.writeAdd(FT0_CFG, 0x3DD0);
  mp27.writeAdd(FT1_CFG, 0x1000);
  mp27.writeAdd(ADC_CTRL, 0x0000);
  mp27.writeAdd(CC_CFG, 0x5F0A);
  mp27.writeAdd(TRIMG_IPCB, 0x4000);
  mp27.writeAdd(HR_SCAN0, 0x0373);
  mp27.writeAdd(HR_SCAN1, 0x003C);
  mp27.writeAdd(HR_SCAN2, 0x01E0);
  mp27.writeAdd(SILC_INFO1, 0x0000);
  mp27.writeAdd(COMM_CFG, 0x0100);
  mp27.writeAdd(BAL_LIST, 0x0000);
  mp27.writeAdd(BAL_CTRL, 0x0000);
  mp27.writeAdd(BAL_CFG, 0x00F8);
  mp27.writeAdd(BAL_THR, 0x0A21);

}

void checkSensors() {
  // Read and print some sensor values
  // Temperature 
  uint16_t dieTemp = mp27.getDieTemperature();
  Serial.print("Die Temperature: ");
  Serial.println(dieTemp);
  
  // Temperature HR
  uint16_t dieTempHR = mp27.getHRDieTemperature();
  Serial.print("Die Temperature HR: ");
  Serial.println(dieTempHR);

  // ADC Readings
  uint16_t adcValues[4];
  mp27.getADCReadings(adcValues);
  Serial.print("ADC Readings: 1v8, 3v3, regin, Vself: ");
  for (int i = 0; i < 4; i++) {
    Serial.print(adcValues[i]);
    Serial.print(" ");
  }
  Serial.println();

  // Vtop Readings
  Serial.print("VTop Readings: "); 
  Serial.println(mp27.getVTopReadings());
  

}

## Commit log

2025-04-05 Update Configuración Inicial ODRIVE.txt
    [Configuración Inicial ODRIVE.txt]
2025-04-14 Create TeensyPCB_René
2025-04-15 Agrego tabla de ensayos del motor
2025-08-14 Subiendo libreria MP2790 alpha
    Para comunicarse con monitor de bateria
2025-08-26 Agregando carpeta librealsense dentro de Cámara
2025-08-26 Agregando carpeta librealsense como archivos normales
    [D415.obj, D435.obj, D455.obj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]
2025-09-12 Unificacion en teensy
2025-10-13 Create Setup Odrive GUI.md
2025-10-13 Update headings in Setup Odrive GUI.md
2025-10-13 Enhance Setup Odrive GUI documentation with new sections
    Added sections for Encoder, Control Mode, Interfaces, and Apply and Calibrate with corresponding images.
2025-10-13 Update Odrive GUI setup instructions for actuators
2025-10-13 Update Setup Odrive GUI.md
2025-10-13 Add controller parameters section to Odrive GUI setup
    Added section for controller parameters with image.
2025-10-30 Add electrical diagram and device list to README
2025-10-30 Update README with current progress section
    Added a new section for current progress and a link.
2026-01-19 Add Final_Prototype file to PCB directory
